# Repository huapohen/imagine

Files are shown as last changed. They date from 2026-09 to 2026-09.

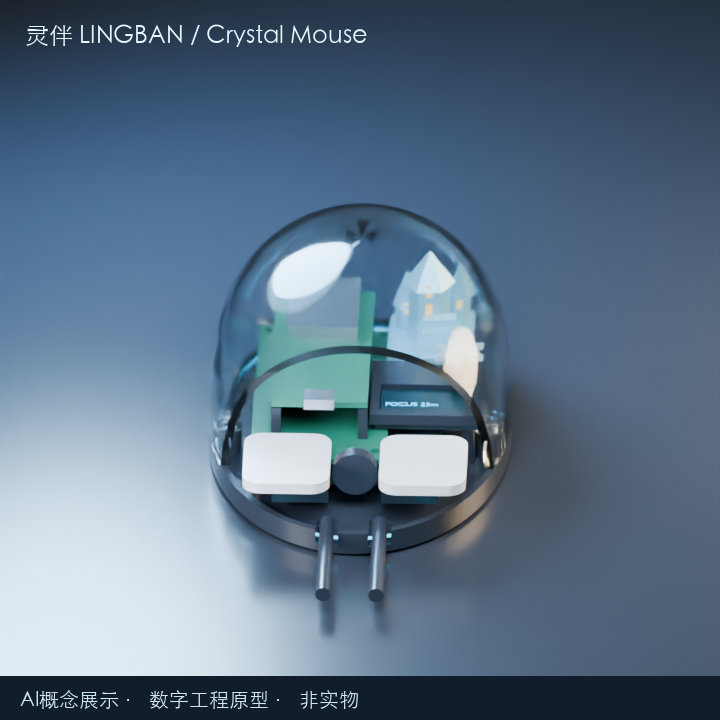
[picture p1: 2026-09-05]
hardware/renders/frames-labeled/0004.png

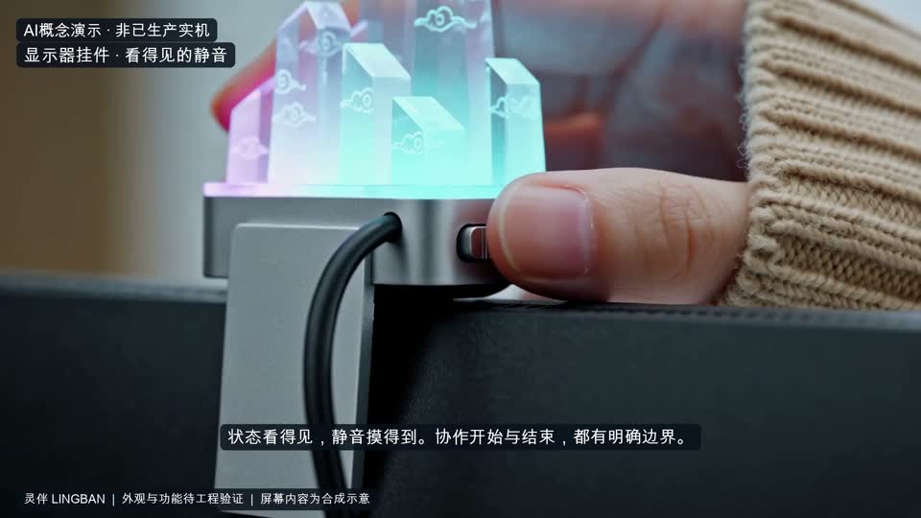
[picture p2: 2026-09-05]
media/qa/05_monitor_charm_05s.jpg

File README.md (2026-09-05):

# 灵伴 LINGBAN / Imagine

透明晶鼠中的原创微型城堡，与电脑上的主动办公伙伴。当前交付是**可运行软件、固件与数字工程原型、商业与路演资料、AI概念影片**；实物样机、认证与量产尚待验证。

## 打开交付

- [本地资料中心](http://127.0.0.1:8766/)：产品图、全部文档、概念影片与评审资料。
- [16页商业计划PDF](pitch/business-plan/lingban-business-plan.pdf) · [商业计划源文](docs/business/business-plan.md)
- [18页可编辑PPTX](pitch/deliverables/final-20260906/lingban-vc-deck.pptx) · [PDF](pitch/deliverables/final-20260906/lingban-vc-deck.pdf) · [离线HTML](pitch/deliverables/final-20260906/lingban-vc-deck.html)
- [3分钟与8分钟逐字稿](docs/business/pitch-scripts.md) · [60个投资人问题](docs/business/investor-qa-60.md)
- [软件启动说明](software/README.md) · [模型接入与真实测试](docs/software/MODEL_INTEGRATION.md) · [固件](firmware/README.md)
- [CAD/PCB工程交接](hardware/COMPLETION.md) · [工厂RFQ](docs/manufacturing-commercial/rfq-template.md) · [独立硬件评审](docs/verification/HARDWARE_REVIEW.md)
- [八条影片与制作验证](media/FINAL_REPORT.md) · [私有GitHub仓库](https://github.com/huapohen/imagine)

## 本地运行

Python 3.9+，软件服务仅使用标准库：

```sh
./software/start.sh
```

按终端显示的员工/企业链接进入。角色令牌是访问凭据，只保存在页面内存；不要把带令牌的链接放进报告。所有默认演示数据均为合成数据，审批结果只进入本地outbox。

本次交付已在8765启动默认离线服务。当前角色链接记录在权限0600、Git忽略且资料服务不提供访问的`.local/demo-server.log`；可在本机终端查看。用户既有Chrome配置曾拦截该端口，未关闭浏览器保护；隔离浏览器验收已通过，录屏可直接查看。

另开终端运行资料中心：

```sh
python3 scripts/serve_workspace.py
```

临时模型测试使用根目录已被Git忽略的`.env`，须按[模型说明](docs/software/MODEL_INTEGRATION.md)显式开启。默认模型为`gpt-6-astra`、推理强度`medium`；模型负责合成场景草稿，本地权限、本人确认和调用预算保持有效。临时配置不进入镜像、交付压缩包或生产环境。

## 验证与交付边界

[最终验收矩阵](docs/verification/RELEASE_READINESS.md)记录自动化、浏览器、协议、固件编译、CAD、KiCad与视频的实际证据及未验证项。

299元是1000台情景下核心版的目标售价；108元制造成本和66.51元单位贡献是模型估算。五台EVT样机的开发板、透明件和装配成本单独计算。融资500万元是建议方案，60万元精简经营模型单独列示，没有收入或融资实绩假设。

企业只获得本人明确分享的业务结果与至少五人的聚合。人数阈值不代表匿名化；不做秘密采集、键盘记录、情绪/生理员工评分或自动雇佣决策。

EVT-A采用OEM USB HID鼠标总成与独立ESP32-S3交互模块、两路USB连接，电脑承担AI。设备唯一线协议是LB1 ASCII + CRC16；MCP 2025-06-18与A2A 0.3.0是本地实现子集。固件可编译、数字检查通过都不能替代实际通电、ESD/EMC、人体工学和工厂DFM签字；制造文件保持**NOT-FOR-FAB**。

大体积影片和制造ZIP通过私有GitHub Release附件分发，源码、财务、文档和精确哈希清单保留在Git。仅克隆仓库时，按[附件清单](docs/operations/RELEASE_ASSETS.md)恢复媒体。没有联系厂家/投资人、租GPU或额外购买工具。

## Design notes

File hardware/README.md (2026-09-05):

# 灵伴 LINGBAN / Crystal Mouse EVT-A

**实际CAD与真实布线PCB数字原型已交接；全部制造文件NOT-FOR-FAB。** 从[COMPLETION.md](COMPLETION.md)查看精确产物、复现命令、实际测试与未验证门槛。

- 主控先传[架构与LB1 ASCII + CRC16串口协议](specs/architecture.md)、[官方核对引脚](specs/pin-map.md)给固件。
- [CAD](cad/README.md)：20件编辑源/STEP/STL，整机和爆炸STEP；底壳、透明上壳、原创独立晶堡/雪花、屏框与组件占位。
- [渲染](renders/README.md)：带概念标识的透明PNG、爆炸PNG、本地转台MP4与可复现Blender源。
- [PCB](pcb/README.md)：可编辑KiCad、实际511段走线/17过孔、BOM/PnP/网表/Gerber/钻孔，真实ERC/几何DRC/schematic-parity报告（均0）。
- [工程与制造](../docs/hardware/engineering-and-manufacturing.md)：99–899分档、299核心量产目标与单列DevKit样机成本、BOM批量/税/良率/NRE、七天样机、装配与验收。
- [验证](validation/README.md)；[工具安装与完整性](tools/README.md)；精简交付包在`delivery/`，不含tools/cache/本地状态。

OEM USB HID + 独立ESP32-S3开发板，双USB或外部Hub；电脑运行Agent。没有融合USB、硬件大模型、已打样/认证/量产或医疗/员工评分声明。主控负责Git、集成与发布；大体积局部工具/DMG/缓存不进交付包。

最终集成：LB1 ASCII+CRC16为唯一设备协议；GPIO/N8R8不变，隐私断SW3V3后灯/屏不显示privacy。49功能节点＋33明确NC节点与原理图完整网名一致，4个机械孔为board_only。既有CAD和pitch渲染hash不变，结果见`validation/integration/result.json`。

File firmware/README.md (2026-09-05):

# 灵伴 ESP32-S3 固件 — safe / EVT-A

工程数字原型，NOT-FOR-FAB。电脑承载 Agent，成熟 USB HID 鼠标底座独立；ESP32-S3 只负责灯光、触摸、隐私开关、可选状态屏与 LB1 串口。无录音摄像、医疗推断或外发。

## 实际构建与测试

```sh
./firmware/test.sh
./software/test-integration.sh
# 已有隔离缓存，构建两个目标，无需安装或网络探测：
PLATFORMIO_CORE_DIR="$PWD/firmware/.platformio" PLATFORMIO_SETTING_ENABLE_TELEMETRY=No \
  firmware/tools/venv/bin/python -m platformio run -d firmware
```

本轮两个目标实际编译 SUCCESS：

|目标|RAM|Flash|物理配置|
|---|---:|---:|---|
|esp32s3_safe|19,964 B / 327,680 B|328,405 B / 3,342,336 B|全部交互引脚和屏地址 -1，缺省隐私，外设不启用|
|esp32s3_evt_a|19,964 B / 327,680 B|332,461 B / 3,342,336 B|GPIO与硬件pin-map对齐，触摸阈值未标定，仍禁用|

产物 `.pio/build/<目标>/firmware.bin` / `.elf`，日志 `build/integration-build.log`。`test.sh` 用 C++11、-Wall/-Wextra/-Werror 编译实际固件共用的协议核心和 Controller 模板。包含104行共用golden以及GPIO/Wire/PWM时序mock，软件完整回归结果见 [COMPLETION](../software/COMPLETION.md)。**这些不是烧录、板测、USB枚举、反灌或触摸校准证明。**

## 板型与端口

PlatformIO Core 6.1.18，espressif32 6.9.0，Arduino ESP32 2.0.17。注册表 `esp32-s3-devkitc-1` 默认描述 N8/no PSRAM，因此两个profile显式覆盖 **N8R8：8MB QIO flash、OPI PSRAM、memory_type=qio_opi、BOARD_HAS_PSRAM**。没有宣称通用板默认配置就是N8R8；实际板标签、PSRAM自检待实物验证。

`ARDUINO_USB_CDC_ON_BOOT=0`。注册表的 `ARDUINO_USB_MODE=1` 仅选择芯片USB模式，**不会自动启用CDC**；本实现的 `Serial` 是 UART0，代码显式 RX44/TX43、115200/SERIAL_8N1。使用开发板 **USB-UART桥连接器**，不是nativeUSB连接器；烧录端口也须硬件人员明确选择，固件会话未运行upload。OEM鼠标另有USB线，载板不并接VBUS。

## EVT-A 针脚与共阳电气合同

|宏|GPIO / 默认值|用途|
|---|---|---|
|LB_PIN_LED_R/G/B|4 / 5 / 6|SW3V3共阳RGB，各经470Ω至GPIO灌电流|
|LB_PIN_TOUCH|7|电极输入；阈值0时不调用touchRead|
|LB_PIN_SDA/SCL|8 / 9|100kHz I2C，外部4.7k上拉到SW3V3|
|LB_PIN_PRIVACY|10|外部10k上拉常供3V3；LOW允许，HIGH/断线隐私|
|LB_SCREEN_ADDRESS|0x3C|SSD1306 128×64候选地址，不等于已探测成功|
|LB_TOUCH_THRESHOLD|0|未实测，禁用触摸采集|

共阳LED亮度b对应8-bit duty=255−b；**off=255/HIGH**，不能写0。恢复时先准备PWM通道off，再预装GPIO HIGH，再attach。当前低亮颜色逻辑为teal=(0,60,38)、amber=(70,30,0)、blue=(0,18,70)，均是占空亮度，不是已实测电流。470Ω限制峰值，LED具体Vf/电流仍需板测。

## 隐私与断线时序

共用控制器 `include/controller.hpp` 是实际固件和mock唯一外设启停策略：

1. 启动先配置/读取GPIO10，再将RGB/I2C/TOUCH全部INPUT，不给未判定电源状态的外设初始化。
2. 物理允许LOW连续稳定40ms，且LB1握手online后，才初始化PWM和屏。屏初始保持Display OFF，写入新图标后才点亮。
3. 检测HIGH立即detach PWM、Wire.end，将4/5/6/7/8/9设INPUT（无内部上拉），清灯/屏/触摸逻辑状态；停止屏刷新。**此分支不发送OLED指令、不强亮LED**，因为SW3V3已经切断。隐私指示靠UI/开关本体。
4. 允许态需重新稳定40ms才能恢复外设；不会恢复隐私前缓存的灯屏指令。
5. 无有效GET/PING心跳>=5秒，清ready/session/cache/灯屏状态；电源仍允许时先OLED Display OFF再释放外设。隐私断电时不发送这个命令。重新HELLO才能恢复online；没有每消息TTL。

主循环每轮及每串口字节检查控制器，串口单轮最多64字节；I2C每个事务前读物理状态、事务timeout=5ms。高电平在正在执行的事务期间变化时，在下一次检查返回后释放外设。这是软件检测时序，**不保证DPDT触点切换瞬间零反灌**；开关两极错时、GPIO复用、在途I2C与实测漏电仍是NOT-FOR-FAB门槛。

无OLED ACK时Wire.end并释放I2C，不持续刷不存在的屏。屏幕仅绘制状态图标，不含中文字体；UTF-8逻辑文本只在串口STATE查询。CAPS声明配置能力，不冒充实物探测报告。

## 触摸启用指南（本轮未启用）

保持threshold=0直至hardware核对电极、串1k、ESD器件DNI/选型、地与外壳，使用合成操作验证干燥/潮湿、接触/不接触噪声分布。不要采用网络示例的未标定固定阈值。经实物审定阈值后，在单独的本地测试profile显式加 `-DLB_TOUCH_THRESHOLD=<实测阈值>`；S3逻辑为touchRead>阈值、稳定40ms才变更布尔状态。

然后必须实测隐私切换时GPIO7输入复用/漏电/触摸硬件是否完全停止、允许恢复是否正确、串口是否始终屏蔽隐私态touch。现有mock不能证明芯片触摸外设的电气状态。触摸只做非敏感本地交互，不能变成情绪/生理信息、医疗判断或审批捷径。

## 串口桥与协议

唯一 [LB1精确规范](../docs/software/serial-protocol.md) 和 [104行golden](../docs/software/serial-golden-vectors.tsv)。无NDJSON、无ttl_ms、无TOUCH/PRIVACY线缆类型。

```sh
cd software
python3 -m lingban.serial_protocol --self-test
LINGBAN_TOKEN='员工本地令牌占位' python3 -m lingban.serial_protocol --once
# 已确认硬件后显式给出设备；本轮未运行：
LINGBAN_TOKEN='员工本地令牌占位' python3 -m lingban.serial_protocol --device /dev/已确认USB_UART
```

桥默认模拟器，不扫描设备。POSIX stdlib termios/select配置115200/8N1；同帧最多重试3次，每次1秒。GET检测offline后新nonce重握手；设备物理拔除造成错误时退出，明确重启后重新打开。关闭时恢复该设备的termios，不改系统全局配置。

## 隔离工具链来源

本轮复用已有 `firmware/tools/venv`、`.platformio` 和 `.pio` 缓存，未下载或安装新依赖。首轮工具来自实测后的可信PyPI镜像和已验证动态系统代理的PlatformIO官方包，包管理器完整性检查开启。`tools-lock.txt` 记录Python依赖；缓存数GiB，均在firmware目录并由.gitignore排除。

新环境需按AGENTS.md先短测源/代理/可信镜像，再建局部venv安装platformio==6.1.18；`build_local.py` 为需网络探测的首次构建辅助脚本，已有缓存优先上面的命令。禁止把构建成功当成允许投板、烧录、认证或量产的依据。

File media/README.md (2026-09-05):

# 灵伴视频研究与制作

官方核验见 `API_CAPABILITIES.md`，完整出处与快照哈希见 `sources.json`。本目录研究代理未读取原始需求/凭据、未调用付费生成。8条原生H3/2K/15秒方案刊例价96元。创建与账单由主控制器负责。

## 复现

```sh
cd /Users/lwblx/huapohen/agent/execute/enterprise_work/imagine/media
python3 video_client.py plan
python3 -m unittest test_video_client.py
# 原生15秒片烧录标签；保留提供方原始尺寸，不将上采样冒称原生2K。
python3 assemble_concept.py --video generated/01_crystal_mouse_focus.mp4 --output edited/01_crystal_mouse_focus.mp4 --title '灵伴晶鼠 · 掌心城堡'
# 可选：真人录制的旁白（voiceover_zh在requests.json），覆盖生成音频。
# 添加 --voiceover narration.wav
# 已有6/10秒AI片源 + CAD静图 = 后期15秒，自动记录provenance而非冒称原生15秒。
python3 assemble_concept.py --video source10s.mp4 --still ../hardware/renders/mouse.png --output edited/composite.mp4
# macOS真实软件屏幕录制；先选中本地演示窗口、全屏，仅显示合成数据。
python3 record_screen.py --list
python3 record_screen.py --screen-index 1 --seconds 15 --output recordings/software-demo.mp4
python3 assemble_concept.py --video recordings/software-demo.mp4 --software-recording --output edited/software-demo.mp4 --title '灵伴本地软件 · 合成数据'
```

屏幕索引必须从本机实时列表取得，示例1不是固定设备。录屏不录麦克风，macOS可能要求系统屏幕录制权限；未授权时不能声称完成录屏。`assemble_concept.py`依赖已有Pillow和ffmpeg/ffprobe，用透明PNG烧录中文，避免当前ffmpeg缺少drawtext/subtitles的问题。默认静音，可添加自有旁白，不下载未经授权配乐。

## 提交与恢复

`MINIMAX_API_KEY`只从环境变量读，不保存在请求/账本或日志。`submit --budget-cny 100 --id …`每次仅提交一条。先将首帧图片以data URL或HTTPS加入对应payload.content（role=first_frame），去掉ratio；参考图免费总数不得超过5。始终保留原始requests和CAD来源。

账本在请求前预占12元；提交后保存task_id；每ID禁止再次提交。网络超时也不释放预占。若task_id未落盘，`list`查看最近任务，与时间/模型/时长/分辨率人工核对，确认身份后`attach`；不可猜测。最近任务窗口7天。失败和取消未核实退款前仍占预算。`poll`只查询一次，不内置等待。`download`只向查询返回的已核验官方CDN域名发送无凭据下载，未知CDN先核验官方文档，不把Key发往CDN。

## 验证与局限

见 `VALIDATION.md`。H3接口/价格为2026-09-06公开文档快照，并非真实账户权限或余额验证。官方未给出输出2K的固定宽高像素表，应保留生成原始分辨率并用ffprobe记录，不强行声称2560×1440。下载SHA-256只能证明本地文件一致性，不能替代提供方签名。没有真实硬件、功能工程验证、医疗测量或量产证明。

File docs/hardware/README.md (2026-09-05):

# 硬件工程交接

产物清单与实际验证：`../../hardware/COMPLETION.md`。

- 架构、引脚和LB1 ASCII + CRC16协议：`../../hardware/specs/`，先传给固件与主控。
- 可编辑CadQuery、STEP/STL：`../../hardware/cad/`。
- 带概念标识的pitch PNG/转台与Blender源：`../../hardware/renders/`。
- 实际布线KiCad、Gerber/drill/BOM/PnP/netlist：`../../hardware/pcb/NOT-FOR-FAB/`。
- 成本分档、7天样机计划、机械/电气审查、制造就绪矩阵及装配验收：`engineering-and-manufacturing.md`。

数字工程原型，不是已验证样机。主控集成与Git；本独立硬件会话没有联系厂家、付费或承诺量产认证。

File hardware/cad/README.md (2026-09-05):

# 参数化机械 EVT-A

编辑 `parameters.json`（mm）与 `build_cad.py`，运行 `hardware/tools/venv/bin/python hardware/cad/build_cad.py`。`exports/`包含每件STEP/STL和整机STEP；`parts.json`列明零件、占位、包围盒和实体有效性。参数并非所有尺寸的唯一来源：放样截面、安装坐标、装饰几何及公差须同时编辑Python源；这是可编辑工程，不是已锁定模具模型。

制造件包括底壳、透明上壳、左右按钮盖、独立晶堡、独立雪花、屏框和城堡定位底座。其余名称带placeholder或标为placeholder的实体仅组件包络。OEM按钮杠杆/滚轮支架/光学镜片安装高度、开关真实固定结构、线缆止拉和屏模组孔位尚未完成，需实际模块图纸后ECO。

实际检查在`../validation/cad-brep.json`及`cad-intersections.json`；不是实物装配通过。STL检查另外记录 watertight/winding；透明壳双层放样名义壁厚非完整等厚认证。工程与装配约束见`../../docs/hardware/engineering-and-manufacturing.md`。

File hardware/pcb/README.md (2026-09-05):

# ESP32-S3 交互载板 EVT-A

`NOT-FOR-FAB/lingban_carrier.kicad_pro` 为可编辑工程；同目录包含原理图、实际双面走线PCB、自包含符号/封装库。36×76×1.6mm，2层1oz假设，0.25mm线宽，0.65/0.30mm过孔。所有输出仅工程评审用。

本载板只含插座、限流/上拉阻容、屏/LED/触摸/物理开关线束接口；ESP32-S3、RGB灯、屏幕与DPDT是外部器件。原理图所有引脚是无源载板触点，ERC只证明本载板连接规则；不证明ESP电气配置或外接器件正确。D1为DNI ESD占位，量产必须冻结真实TVS并更改封装/复验。

复现：仓库根运行 `python3 hardware/pcb/build_pcb.py --sync-existing`、`python3 hardware/pcb/finalize_project.py`、`python3 hardware/pcb/export_and_verify.py`。最后一条真实调用KiCad9.0.7，强制--schematic-parity及--exit-code-violations，同时记录独立几何DRC、ERC并导出制造文件。`gerber-review-only/`不是下单包；禁止仅因DRC/ERC通过即生产。

官方pinout/协议见`../specs/`；供电、线束、装配、成本与未验证项见`../../docs/hardware/engineering-and-manufacturing.md`。PCB顶面箭头方向尚需丝印完善，按J1/J3官方脚1及方形焊盘识别。PnP.csv为设计清单，PnP-kicad.csv为KiCad导出坐标；优先后者并由贴片厂核对底面旋转、原点和DNI。

`build_pcb.py --sync-existing`与`semantic_sync.py`只统一局部标签的完整网名、明确NC单脚网、符号path和机械孔board_only属性，不改铜线坐标。普通全量生成也会调用同一逻辑，未新增忽略规则。H1–H4的exclude_from_bom/pos是真实板上专用机械语义；采购BOM不列机械孔。49功能节点、33个无铜NC节点共82项与KiCad导出网表逐项匹配，检查不删除/前缀。

`sexpr.py`随本目录交付；工具环境不进入ZIP。设备接口只使用LB1；USB-UART115200、GPIO4–10及N8R8按已实装配置冻结，见specs/。

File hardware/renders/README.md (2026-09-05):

# 概念渲染与转台

本地Blender/Cycles渲染，源网格来自同批CAD导出的STL。不是硬件照片，未打样/认证。光环、发光窗和屏幕内容为视觉示意/合成数据；不代表当前低电流LED已经达到光环均匀效果。

```sh
hardware/tools/mount-blender/Blender.app/Contents/MacOS/Blender -b -t 8 --python hardware/renders/render_scene.py -- hero
hardware/tools/mount-blender/Blender.app/Contents/MacOS/Blender -b -t 8 --python hardware/renders/render_scene.py -- exploded
hardware/tools/mount-blender/Blender.app/Contents/MacOS/Blender -b -t 8 --python hardware/renders/render_scene.py -- turntable
hardware/tools/venv/bin/python hardware/renders/finish_media.py
```

`lingban_hero.blend`内已保存120帧/24fps、线性完整旋转的关键帧源；`render_scene.py`可确定性重建灯光、材质、相机、爆炸间距与转台。演示MP4使用每4帧抽样、6fps回放，约5秒一周；不是实时交互。PNG附有概念标识，可直接交pitch；raw文件只供后处理，外发须使用带标识版本。

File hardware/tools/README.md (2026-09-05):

# 任务局部工具环境

已安装/使用 CadQuery 2.8.0（OpenCascade7.9.3）、trimesh5.1.0、Blender4.5.3、KiCad9.0.7；系统现有ffmpeg。Python venv、下载缓存和只读DMG挂载点全部位于hardware/tools或hardware/downloads。未执行brew全局安装，未接受KiCad全局库配置。GUI不是复现依赖。

当前命令：

```sh
hardware/tools/venv/bin/python hardware/cad/build_cad.py
hardware/tools/mount-blender/Blender.app/Contents/MacOS/Blender --version
hardware/tools/mount-kicad/KiCad/KiCad.app/Contents/MacOS/kicad-cli version
```

重启后重新挂载已验证的DMG：

```sh
mkdir -p hardware/tools/mount-blender hardware/tools/mount-kicad
hdiutil attach -readonly -nobrowse -mountpoint "$PWD/hardware/tools/mount-blender" hardware/downloads/blender.dmg
hdiutil attach -readonly -nobrowse -mountpoint "$PWD/hardware/tools/mount-kicad" hardware/downloads/kicad.dmg
```

重建venv先遵守AGENTS网络短测，采用已测可用的PyPI/可信镜像，再运行 `uv venv hardware/tools/venv --python 3.13` 与 `uv pip sync --python hardware/tools/venv/bin/python --require-hashes hardware/tools/requirements.lock`。Python3.13须已经存在；不要为便捷改系统Python。uv缓存使用`UV_CACHE_DIR="$PWD/hardware/tools/uv-cache"`。

网络证据：validation/network-probes.json、mirror-probes.json、download-progress.log。Blender经官方SHA256比对；KiCad DMG通过hdiutil内部校验且应用通过codesign严格验证，签发主体KiCad Services Corporation (9FQDHNY6U2)。首次Blender分段文件损坏已精确删除并重新完整下载，重新校验通过；未清空系统缓存。官方校验文本在downloads/blender.sha256。

主控集成时只打包源码/产物/文档，**不要把downloads、venv、uv-cache或mount-*应用树加入Git或发布包**。本会话不执行Git操作。

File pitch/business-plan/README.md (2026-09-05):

# 灵伴中文商业计划书

交付：`lingban-business-plan.pdf`，A4竖版16页，约3.5MB。包含原创产品概念渲染、需求与主动交互、公司授权边界、20人验证方案、官方竞品事实、完整价格梯度、BOM/单位贡献图、三情景现金图、500万元建议融资用途、7天/30天门槛、工厂验收、半年生态、团队与10个月战略选择、来源页。

本PDF是详细中文BP关键内容的阅读版，非18页横版投资演示稿；完整叙述与可修改假设保留在 `../../docs/business/business-plan.md`、`financial-model.md`、其余商业Markdown和CSV中。正文排版稿在 `build_pdf.py`，财务图表和情景表读取原始CSV，生成时检查关键财务口径；不改变原始模型。融资第11节已追加到源BP。

## 复现

在项目根目录执行：

```bash
/Users/lwblx/.cache/codex-runtimes/codex-primary-runtime/dependencies/python/bin/python3 pitch/business-plan/build_pdf.py
/Users/lwblx/.cache/codex-runtimes/codex-primary-runtime/dependencies/python/bin/python3 pitch/business-plan/validate_pdf.py
```

依赖本机bundled Python中的reportlab、pypdf、pdfplumber、Pillow及bundled Poppler。使用本机 `/System/Library/Fonts/Supplemental/Arial Unicode.ttf`，只在PDF中嵌入必要字体子集；目录没有复制或分发字体文件。未用LibreOffice、网络下载或外部服务。非本机复现需自行提供合法可用的中文TTF和更新脚本中的字体/运行时路径。

`qa/`保留16页实际Poppler渲染、全页拼图、结构/字形检查、抽取文本、布局记录和来源哈希。人工检查结论见 `QA.md`。若修改正文或CSV，重新构建、渲染并目检；修改源Markdown不会自动替代所有编辑过的PDF排版文案。

## 财务与真实性口径

- 500万元为本方案建议的天使融资金额，不是用户原文指定金额、已承诺投资或已到账资金；用途为建议，不构成支出授权。
- 60万元是独立的精简验证模型。500万元用途尚未建立同口径分月模型，因此不报告跑道和投资回报。
- 产品图是原创三维概念渲染，非实物/制造证明；留存、订单、销售与交付门槛均未声称已经达成。
- 官方竞品标价/性能主张与独立测试、订单和众筹成功明确分开。

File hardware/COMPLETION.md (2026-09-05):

# 灵伴 LINGBAN / Crystal Mouse EVT-A — 完成交接

**交付状态：实际CAD + 实际布线PCB的数字工程原型；全部制造输出 NOT-FOR-FAB。** 完成日期2026-09-06。唯一首发为299元核心目标含税零售价（1000台情景，灯＋触摸＋OLED）；当前5台DevKit样机成本约863–1850元/合格台未税工程估算、待报价；108元是未来批量商业模型假设，499仅未来外观/服务套装。没有实物打样、板级通电、固件烧录、认证或量产完成声明。本会话只写hardware/与docs/hardware/，不做Git、不读取原始input/需求或.env、不联系厂家、不付费；主控负责集成。

## 本轮最终集成结果

- 唯一协议LB1 ASCII+CRC16，UART桥115200 8N1、N8R8和GPIO冻结；无每消息TTL/推送事件。隐私切SW3V3并高阻GPIO4–9，不显示privacy灯/屏；touch阈值0默认禁用，屏为状态图标。
- 修复已复现的86项parity差异：保留原理图局部标签，用完整`/3V3`等名称匹配PCB；33个明确NC单脚网按KiCad语义保留且无铜连接；H1–H4设`board_only/exclude_from_bom/exclude_from_pos_files`，不使用全局忽略或错误豁免。
- **KiCad9.0.7 schematic parity=0、几何DRC=0、未连接项=0、ERC=0**。完整网络名逐节点比较：49功能节点＋33明确NC节点，共82节点一致；36项选定/保留脚检查通过。
- CAD与pitch渲染118个既有文件hash均未改变，铜线/过孔/焊盘/板框几何hash未改变，既有CAD干涉仍为[]。本轮不重新生成几何、不重渲染产品图；仅刷新PCB检查、制造导出与PCB图。
- 交付ZIP重新生成，严格不含`tools/`、下载/缓存、`.env`、锁文件、KiCad本地状态或`.DS_Store`；源码S表达式辅助模块随PCB提供。包与逐文件hash在delivery/，包装审核见`package-audit.json`。

证据：`validation/integration/result.json`、`integration/parity-before.json`、`pcb-drc.json`、`pcb-geometric-drc.json`、`sch-erc.json`、`netlist-pinmap-check.json`。生成器用`--sync-existing`只修项目语义，铜线原样保留；之后从头生成也调用同一语义逻辑。

## 精确产物

|用途|路径|内容|
|---|---|---|
|冻结软硬件架构|`hardware/specs/architecture.md`|OEM USB HID + 独立ESP32-S3开发板，双USB/外部Hub，电脑运行Agent；LB1 ASCII + CRC16串口协议|
|官方核对引脚|`hardware/specs/pin-map.md`、`pin-map.json`|GPIO4/5/6/7/8/9/10对应J1.4/5/6/7/12/15/16；v1.1板载RGB38/初版48均避开；官方文本、DXF与原理图缓存在references/|
|参数化CAD源|`hardware/cad/parameters.json`、`build_cad.py`|mm单位，外壳/底板/光学孔/双出线槽/柱位与公差、屏框、原创云阶晶堡、六折雪花、定位底座及组件占位|
|CAD工程导出|`hardware/cad/exports/`|20件逐件STL + 20件逐件STEP；`lingban_assembly.step`整机装配；`lingban_exploded.step`爆炸装配。当前零件以parts.json为准，无旧插座重复件|
|pitch图片|`hardware/renders/lingban_hero.png`、`lingban_exploded.png`|1800×1500透明Cycles渲染，带“AI概念展示 / 数字工程原型 / 非实物”标识|
|动画与源|`hardware/renders/lingban_turntable_concept.mp4`、`lingban_hero.blend`、`lingban_exploded.blend`、`lingban_turntable.blend`、`render_scene.py`、`finish_media.py`|720×720、约5秒完整转台视频；120帧24fps可编辑旋转源，视频每4帧抽样。raw/frames只作中间产物|
|可编辑PCB工程|`hardware/pcb/NOT-FOR-FAB/lingban_carrier.kicad_pro`、`.kicad_sch`、`.kicad_pcb`|36×76×1.6mm两层载板，开发板双排插座，灯/触摸/屏/DPDT物理开关线束，底面阻容，自包含符号和封装库|
|真实走线图|`hardware/pcb/NOT-FOR-FAB/plots/pcb-routed.svg`、`pcb-routed.png`|由实际KiCad铜线/焊盘坐标导出，511段铜线、17过孔、35条连接树边；无未布线连接|
|网表/装配清单|`hardware/pcb/NOT-FOR-FAB/lingban_carrier.net`、`.xml`、`BOM.csv`、`PnP.csv`、`PnP-kicad.csv`|KiCad真实网表；底面SMD贴装坐标，D1标DNI；厂商须确认底视/顶视、原点与旋转|
|制造评审文件|`hardware/pcb/NOT-FOR-FAB/gerber-review-only/`|F/B铜、F/B阻焊、F/B丝印、底面锡膏、Edge.Cuts共8个Gerber；PTH/NPTH两份Excellon钻孔、钻孔图、gbrjob。不是下单包|
|工程/商业交接|`docs/hardware/engineering-and-manufacturing.md`|99/199/299/499/899电子机械差异、BOM批量/税/良率/NRE估算、7天样机计划、制造就绪矩阵、装配验收与工厂待确认尺寸|
|局部工具与校验|工作区`hardware/tools/README.md`（不随ZIP）、`hardware/requirements.lock`；`hardware/validation/tool-integrity.json`|CadQuery2.8.0、trimesh5.1.0、Blender4.5.3、KiCad9.0.7；官方哈希/应用签名验证；不依赖全局brew安装|
|精简交付包|`hardware/delivery/lingban_evt_a_review.zip`、`SHA256SUMS.txt`|供主控集成，不含tools目录、DMG、venv、缓存、挂载应用树、本地状态和视频逐帧中间文件|

## 可重复运行命令

在仓库根运行；工具挂载/重建步骤见hardware/tools/README.md。

```sh
python3 hardware/pcb/build_pcb.py --sync-existing
python3 hardware/pcb/finalize_project.py
python3 hardware/pcb/export_and_verify.py
hardware/tools/venv/bin/python hardware/pcb/render_board.py
hardware/tools/venv/bin/python hardware/validation/validate_artifacts.py
python3 hardware/validation/integration/check_integration.py
python3 hardware/package_delivery.py
```

`export_and_verify.py`调用真实KiCad，parity检查同时启用`--schematic-parity --exit-code-violations`，另导出独立几何DRC和ERC，失败非零退出。当前命令使用工作区既有工具；精简ZIP不附带tools，可用已安装的等版本工具或以hardware/requirements.lock重建局部Python环境。CAD尺寸参数不是全部独立约束求解器；更改壳宽/壳长会调整放样，但安装坐标、OEM接口与装饰仍须检查Python参数与干涉，不能只改一个数字直接制造。

## 实际验证

- OpenCascade：当前20件BREP均有效、均为一个实体；两两正体积干涉 >0.05mm³ 为0。见`validation/cad-brep.json`、`cad-intersections.json`。不意味着局部法向壁厚、公差、强度或实物手感已通过。
- 导出STL：20件均封闭、水密、法向一致、正体积、单连通实体，见`stl-mesh-check.json`、`artifact-check-summary.json`。
- KiCad9.0.7：**ERC 0违规；几何DRC 0违规、0未连接项；schematic parity 0**，未靠规则忽略/排除消除报告。见`sch-erc.json`、`pcb-drc.json`、`pcb-geometric-drc.json`与`kicad-command-results.json`。ERC对象是无源载板触点，不证明ESP/外部模块电气特性。
- 36项官方选定脚/保留脚核对通过；49功能焊盘及33个明确NC焊盘与KiCad导出原理图网表完整名称一致（不再去掉/前缀），NC均单脚且无铜连接。见`netlist-pinmap-check.json`。本轮已只读核对LB1软件/固件、N8R8 profile及GPIO；主控报告两目标编译和HAL测试通过，本会话不重复编译/烧录。
- Blender官方SHA256匹配，Blender/KiCad应用codesign严格验证退出0；KiCad DMG内部校验有效。Python以官方PyPI元数据生成hash锁并从实测可信镜像执行`--require-hashes --reinstall`成功。见工具完整性/安装日志。
- 渲染由本地Cycles执行；视频由ffmpeg编码、ffprobe检查，见`media-probe.json`。城堡窗发光、光导环与屏幕文案是视觉示意/合成数据。

## 工程师/厂商确认后才能推进的点

1. **制造状态不提升到fab-candidate**：D1为未冻结封装的ESD DNI占位；RGB、OLED、DPDT及插座未全部冻结MPN/供应商图纸。需要真实TVS方案、线束脚序、装配方向和DFM审核。
2. **电气未实测**：开发板稳压器/USB能力、启动与无线峰值、满白屏/满亮、隐私断电反灌、触摸阈值/ESD、温升。初版默认USB-UART且关闭Wi-Fi/BLE；通用500mA端口不能按1A电源使用。
3. **隐私边界明确**：机械DPDT切屏/灯电源并给GPIO状态，断线默认隐私；不硬断USB、触摸线路或主机Agent。实装HAL detach PWM/Wire.end并将GPIO4–9置INPUT，无内部上拉；SW3V3断电后不显示privacy灯/屏，只由UI/开关本体指示。触摸默认阈值0、禁用采集，屏仅状态图标；没有音视频、生理诊断、员工评分或秘密采集。
4. **机械需实物ECO**：OEM外形/固定孔/镜片到桌面高度/光学中心、按钮杠杆与滚轮结构；屏模块厚度/孔位和屏框防脱卡扣；装饰底座防脱；隐私开关固定孔与实际止拉件；铜螺母/底脚/螺钉/透明料收缩和后处理。当前名义126×80×54，实际曲面可能超调，完整包络见`assembly-envelope.json`。
5. **RF净空未完成整机验证**：PCB有禁铜区，但附近金属紧固件/铜螺母仍需移位或改非金属，按实际模块天线参考布局复审；不宣称无线/EMC验证通过。
6. **下阶段是7天样机**：到货、工程师签字、电气上电与机械验收均是门槛；30天试销受法规/认证/小批量验收限制。没有厂商报价，所有成本明确批量、税、良率和NRE假设；VC/退出估值不属于本次硬件事实。

specs/已与实装LB1/GPIO同步，继续使用hash未变的带标识PNG/MP4供pitch，最后将NOT-FOR-FAB工程交给电子/机械工程师审核。不要把hardware/downloads、tools/venv、uv-cache、mount-*加入Git或对外包。

## 本轮影响文件

- 接口与商业：`hardware/specs/architecture.md`、`pin-map.md`、`pin-map.json`；`hardware/README.md`、本文件；`docs/hardware/README.md`、`engineering-and-manufacturing.md`。
- PCB语义与复现：`hardware/pcb/build_pcb.py`、新增`semantic_sync.py`与本地`sexpr.py`、`finalize_project.py`、`export_and_verify.py`、`render_board.py`、PCB README；NOT-FOR-FAB中的PCB/原理图、库、BOM、导出网表/制造文件/PCB图已刷新。铜线几何未改，原项目规则未加忽略项。
- 验证与交付：`hardware/validation/validate_artifacts.py`、README、`integration/`和当前检查报告；`hardware/package_delivery.py`、用于无工具环境交付的`hardware/requirements.lock`、delivery/ZIP/manifest/SHA/audit。CAD与产品PNG/MP4/Blender源均未修改；软件、固件及商业主文只读。

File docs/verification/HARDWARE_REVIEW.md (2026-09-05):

# 独立硬件与协议集成评审

日期：2026-09-06。对象：`hardware/pcb/NOT-FOR-FAB` 数字工程原型、当前 CAD、固件与主机串口代码。评审期间各包持续修改，以下为本轮实际读取/执行的快照；未将实物未验证或正常在制列为缺陷。保留 NOT-FOR-FAB 状态，不授权投板。

## 2026-09-06 最终再复核状态（以此表覆盖下方早期快照）

本轮已发现的代码、电气网表一致性与交付口径问题均已关闭；没有剩余必须修改源码的阻断。制造文件仍为 NOT-FOR-FAB，原因是实物验证门槛尚未完成。

|项目|最新独立证据|状态|
|---|---|---|
|共阳 RGB 反相|真实 Controller 输出 OFF=255，teal=[255,195,217]；独立 Mock HAL 测试通过|代码级关闭，未通电验证|
|隐私高阻/I2C 停止|启动先读 GPIO10；隐私进入 detach PWM、Wire.end、GPIO4..9 INPUT；期间不刷屏；允许稳定 40ms 后才重启|代码级关闭，未测物理反灌瞬态|
|5秒通信失效|独立测试精确 5000ms、恢复握手、millis uint32 回绕；失效关灯/清文本/断外设驱动|代码级关闭|
|固件配置/端口|safe 全部交互禁用；独立 EVT-A GPIO4..10、触摸阈值0、OLED候选0x3C、CDC_ON_BOOT=0、UART0 RX44/TX43；N8R8 qio_opi/8MB|两个配置独立编译通过|
|LB1 实现|Python 编码 HELLO/SET/GET → C++ → Python 解码 CAPS/ACK/STATE，含 session nonce；C++/Python各执行104行冻结golden，75条期望响应CRC另经stdlib独立核验|已通过原生互通|
|硬件协议/299售价文件|architecture、hardware README/COMPLETION、docs/hardware 已统一LB1和299灯＋触摸＋OLED核心目标；499仅未来套装，5台DevKit成本863–1850单列，旧LBP仅出现在废弃声明|口径冲突关闭|
|KiCad parity|硬件修复后独立官方 CLI full parity：0几何错误、0未连线、**0 parity**；再次导出XML，82个SCH针脚与PCB精确网名完全一致|原86项已关闭|
|CAD|最新完整生成报告为 `[]`；独立回读20个实际导出STEP全部有效，base/carrier/canopy分别与所有其他当前部件求交，无>0.05mm³正体积干涉|已有几何证据，未做公差/实物装配验收|
|硬件专用ZIP|02:25更新的145条manifest与磁盘、ZIP逐SHA一致；ZIP CRC、SHA256SUMS均通过，关键LB1/299文档和PCB为最新|包内一致性通过；完整软硬件交付范围见下文|

独立 HAL 测试交付源码为 [hal_independent.cpp](hal_independent.cpp)，没有复用构建者测试。覆盖启动隐私、safe 配置、允许去抖、共阳 OFF/颜色、隐私停止、禁用触摸、通信失效/重连、PWM准备期间隐私突变和计时回绕；全部通过。另编译运行构建者 protocol/controller 测试，也通过。测试源码不包含本机绝对路径、凭据或二进制。

在项目根目录复现（仅 C++11 编译器，输出位于忽略的本地目录）：

```sh
mkdir -p .local/review
c++ -std=c++11 -Wall -Wextra -Werror -Ifirmware/include \
  docs/verification/hal_independent.cpp -o .local/review/hal_independent
.local/review/hal_independent
```

STEP 回读证据 `.local/review/final-step-check.json` 使用当前 `parts.json` 有效清单，不导入 exports 中的旧迭代部件；没有重跑或修改硬件生成源。

硬件专用ZIP的独立核对证据为 `.local/review/final-package-check.json`，145条manifest与包中内容全部匹配，未包含 `.env`、`.local`、工具虚拟环境或下载目录。该专包未包含权威 `docs/software/serial-protocol.md` 与 `serial-golden-vectors.tsv`。主控已确认总集成 `scripts/package_factory.py` 负责配套完整协议/向量、固件src/include/test、本独立HAL源码与报告、RFQ/验收资料；完整工程交接应使用总集成包。总包的最终生成、打包检查与发布由主控收尾，本评审不把尚未执行的总包发布写作已验证。

共享协议向量已分别用 C++ runner 和 Python Simulator 独立重放 **104 行**，全部通过；75 条带线缆帧的期望响应另外用 Python 标准库 `binascii.crc_hqx(...,0xffff)` 核验 CRC。可复现命令：

```sh
c++ -std=c++11 -Wall -Wextra -Werror -Ifirmware/include \
  firmware/test/protocol_test.cpp -o .local/review/protocol_final
.local/review/protocol_final --golden docs/software/serial-golden-vectors.tsv
```

编译使用现有缓存 PlatformIO/ESP32 工具链，无下载；输出目录 `.local/review/pio-build`，日志 `independent-pio-build.log`：safe 和 EVT-A 均 SUCCESS。safe RAM 19,964B、Flash 328,405B；EVT-A RAM 19,964B、Flash 332,461B。**编译、Mock HAL 与原生协议通过不等于烧录或实物验证。**

<details>
<summary>首次发现记录（历史快照；已修固件问题不作为当前阻断）</summary>

1. **P1：固件输出模式与载板电气合同不一致。** 当前 `firmware/src/main.cpp:36-41` 用 active-high PWM，`firmware/include/board_config.hpp` 也明确写 active-high；载板为 SW3V3 共阳 RGB，GPIO 经 470Ω 灌电流。启用实际引脚后，`off` 对应三路 0 占空比，即持续拉低、实际全亮；颜色和亮度反相。必须为共阳反相输出。默认全部引脚 -1 使此问题暂未施加到实物，不能据此将错误的 EVT 配置交给接线人员。
2. **P1：隐私态未停止外设 GPIO/I2C 驱动。** 当前 `firmware/src/main.cpp:57` 仅更新逻辑状态；`:71-72` 继续 PWM 与定期 Wire 刷屏，`:48-50` 在首次读取物理隐私输入前已初始化外设。载板切断 SW3V3 后，这不满足 pin-map 要求的 RGB/I2C/TOUCH 高阻，并可能经数据线给断电外设反灌。应先采样隐私，再按允许态启用；隐私激活时立即停止/卸载 PWM、结束 Wire 并将交互引脚设高阻；恢复允许需明确重初始化。主控已通知软件会话修复，**本轮尚未获得修复后硬件适配代码回归结果**。
3. **协议合同冲突必须收敛。** 已实现的 Python/C++ 都是 `LB1|seq|TYPE|payload|CRC16`，ASCII、256-byte 上限、序号 1..65535；`hardware/specs/architecture.md:14-26` 当时仍为 LBP/0.1 NDJSON、512-byte、uint32、RGB/TTL 字段。二者不可互解。主控已裁决 LB1 为唯一现行协议并通知硬件更新；收尾需全仓消除将 NDJSON 视为现行协议的声明。`firmware/platformio.ini` 当前还启用 USB CDC，而硬件架构约定 USB-UART 桥，主控已通知用独立 EVT 配置统一端口。
4. **P2：KiCad 原理图/PCB 实际网名不一致。** 独立开启 `--schematic-parity` 得到 86 条：82 条 net_conflict、4 条 extra_footprint。49 个有效连接的拓扑逐脚一致；冲突主要为 SCH 局部标签 `/3V3` 与 PCB `3V3` 的根路径名称，以及 SCH 的 33 个 `unconnected-*` 与 PCB 空网。4 个安装孔没有 SCH 元件。必须统一网名/NC 与机械孔策略，或精确记录认可的 board-only 孔项，不能以普通 DRC=0 宣称 parity=0。这不是已证实的电气短接或 GPIO 接错。

上述 P1 与协议冲突已即时发送主控。旧协议中的 5 秒离线/TTL 承诺也需处理：当前 `main.cpp:70` 仅在半帧超时时清输入缓存，完整会话断线不清 ready/灯/屏状态；采用 LB1 后应实现有效帧心跳失效回安全态，或明确不再宣称尚未实现的能力。

</details>

## 针脚、网络与电源核对结果

用实际挂载的 **KiCad 9.0.7 CLI** 导出 SCH 的 XML 网表，另行解析 PCB 的每个 footprint/pad-net；没有仅依赖路由脚本或 DRC 摘要。首次49个有效连接节点/14个网络在规范化根路径后拓扑一致；**修复后再次独立导出，全部82个SCH针脚（含NC）与PCB精确网名直接比较，零错配，不再去掉根路径**。PCB 86 个焊盘中的额外4个是明确的board-only安装孔 H1–H4。

|功能|实际连接|判定|
|---|---|---|
|常供 3V3|J1-1/2、C1-1、R7-1、J7-2|与开发板官方针序一致|
|GND|J1-22、J3-1/21/22，以及屏/触摸/电容/开关回路|与官方针序一致|
|红/绿/蓝|J1-4/5/6 → R1/R2/R3 470Ω → J5-2/3/4|GPIO4/5/6 正确，共阳 J5-1 接 SW3V3|
|触摸|J1-7(GPIO7) → R4 1k → J6-1 ELECTRODE；D1 预留到 GND|拓扑一致，D1 是明确 DNI 的待选件|
|屏|J1-12(GPIO8) SDA、J1-15(GPIO9) SCL；R5/R6 4.7k 上拉到 SW3V3；J4=GND/VCC/SCL/SDA|正确，没有将上拉接常供 3V3|
|隐私|J1-16(GPIO10) ↔ R7 10k 常供 3V3 ↔ J7-4；J7-5=GND|高/断线为隐私，与 fail-closed 文档一致|
|双极外置开关|J7-1=SW3V3 common、2=3V3 allow、3=NC；4=PRIVACY_N common、5=GND allow、6=NC|按已写的外置线束约定允许态两极同时闭合；无开关具体料号，仍需实物触点/线束核对|

缓存官方文本 `hardware/specs/references/esp32-official-text.txt` 的 J1/J3 表与上述接用针脚一致。22×2 排针节距 2.54 mm；两排 x=6.57/29.43，中心距 22.86 mm。未用 J1-21 的 5V，未占用 N8R8 的 GPIO35/36/37、启动绑带或 USB/UART 保留脚。

LED 峰值不能只凭低 PWM 占空比声称达标，串阻才约束峰值。以常见红 LED Vf≈1.8 V 举例，(3.3−1.8)/470≈3.2 mA；绿色/蓝色电流取决于真实 Vf。当前 470Ω 共阳方案没有发现必然过流，但 LED 具体料号与 Vf 未定，“每路峰值 ≤5 mA”仍须按最坏电源/电阻/LED 参数复核，不能算已板测。

触摸 D1 在 SCH 标 dnp、BOM 标 DNI，当前实板设计不具有已选定/已装配的 ESD 防护。该限制已写入工程资料，作为 NOT-FOR-FAB 候选可接受；接触放电、漏电/寄生电容和触摸阈值必须在器件选型后验收。

## KiCad 实际检查

- 本轮独立执行 ERC：**0 violations**。
- 本轮独立执行 DRC，含 all-track-errors、severity-all：**0 几何/间距 violations、0 unconnected items**。
- 修复后同一命令加 schematic-parity、severity-all：**0 parity issues**；原86项已关闭，没有把4个安装孔误作缺失电气元件。
- 所有符号为被动连接器/无源器件，ERC=0 不会检测 MCU 固件方向、共阳反相或断电反灌。
- PCB 0..36 × 0..76 mm，厚 1.6 mm；实际有 511 段铜线、17 个过孔，不是仅飞线。天线区存在实际双层 keepout：x=7..29、y=0..8，禁止 tracks/vias/pads/copperpour；当前铜线端点最低 y=10 mm，没有看到进入该区域的线路。keepout 不证明射频性能，开发板版本/天线位置/外壳金属距离仍须实物核对。

最终独立证据：`.local/review/final-netlist.xml`、`final-drc.json`、`final-erc.json`。初次 `independent-drc.json` 的86项只保留作修复历史。命令使用项目内挂载的 `hardware/tools/mount-kicad/KiCad/KiCad.app/Contents/MacOS/kicad-cli`，没有安装/下载工具或修改系统设置。ERC/DRC 配置目录限定 `.local/review`。

安装同版本 KiCad 后，从项目根目录复现全量 parity 检查（可将 `kicad-cli` 替换为本机官方工具路径）：

```sh
kicad-cli pcb drc --schematic-parity --all-track-errors --severity-all \
  --exit-code-violations --format json -o .local/review/final-drc.json \
  hardware/pcb/NOT-FOR-FAB/lingban_carrier.kicad_pcb
kicad-cli sch erc --severity-all --exit-code-violations --format json \
  -o .local/review/final-erc.json hardware/pcb/NOT-FOR-FAB/lingban_carrier.kicad_sch
```

## CAD 与载板实物占位

当前 `hardware/cad/build_cad.py:52-57` 的载板为 36×76×1.6 mm，与实际 PCB Edge.Cuts 相同。CAD 坐标关系可对齐为 x_CAD=x_PCB−28、y_CAD=40−y_PCB；PCB 四孔 (3,3)/(33,3)/(3,71)/(33,71) 对应 CAD x=−25/5、y=37/−31，孔径均 2.5 mm。排母 x=−21.43/1.43、长 55.88 mm，与双排 22 脚及 22.86 mm 排距一致。

CAD 的板底 z=12 mm、板顶 13.6 mm、排母高 9 mm、开发板底 z=23 mm 已留出堆叠关系；但板底 SMD 元件、连接器壳体/插头/线束、焊点高度尚无完整实体包络，不能把“载板矩形没有相交”写为完整装配净空验证。开发板和 OEM 仍是明确的待实测占位。

评审中相交报告持续更新：开始见排母与屏框/屏占位相交，后续已消失；本轮最后读取 `hardware/validation/cad-intersections.json` 尚列 canopy↔castle_socket_sled 2.564 mm³。硬件会话仍在修，此项记为**在制、未做最终关闭**，不把此前已消失的中间问题列作当前缺陷。最终应检查最新 assembly 与有效 parts 清单；exports 中存在以前迭代的不同排母坐标文件，不能逐个导入整个目录当作最终装配。

## 协议实际运行与上一轮 P1 回归

本轮把现有 `firmware/test/protocol_test.cpp` 编译至 `.local/review/protocol_test`，未修改源码。原生 C++ 测试通过 CRC16-CCITT-FALSE 标准向量、帧界限、握手、默认隐私、幂等/冲突、字段验证。再用 Python 的真实 `encode` 生成 HELLO/SET/GET 喂给 C++ `--echo`，Python `decode` 成功读取 CAPS/ACK/STATE。**这证明 LB1 编解码跨语言一致，不证明 Arduino GPIO、USB、OLED 或真实串口通信。**

- 前轮 R1 已关闭：全新内存 Store 首次 `task.upsert` 与 `meeting.upsert` 都成功，不再出现 9 列/10 占位符错误。
- 前轮 R2 已关闭：5 人企业 A2A 摘要后撤回 1 人，旧 `tasks/get` 返回 404，同 `messageId` 重放重新计算 `available=false`；旧 artifacts/history/status.message 不再经该路径读回。
- 本轮没有再次审计全部前轮 P2 或新增加的全部软件 API，不能将上述两项通过扩大为全软件验收。

## 可接受限制

无真实样机、板级功耗/ESD/反灌/射频/人机工程验证，属于明确的数字原型边界。safe 配置引脚禁用、EVT-A 触摸阈值待标定、D1 DNI、双 USB、未完成中文屏幕字体均可在准确标识下接受。共阳 PWM 与隐私高阻已完成代码修复和独立 Mock HAL 回归；生产输出继续保持 NOT-FOR-FAB，直到工程复核与实测门槛完成。

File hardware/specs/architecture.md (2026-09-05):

# 灵伴 LINGBAN / Crystal Mouse — EVT-A 冻结接口

工程数字原型，未打样、未板测、未认证。日期2026-09-06。主控集成；所有尺寸mm。原创「云阶晶堡」。本轮同步已实装的协议和固件配置，不改变GPIO、CAD几何或pitch渲染。

## 唯一首发与硬件边界

- **299元是1000台情景的核心版目标含税零售价，功能为灯＋触摸＋OLED。** 首轮只验证这一核心硬件；108元批量直接成本是未来商业模型假设，非当前开发板样机报价。5台DevKit工程样机成本单列、待报价。499元仅未来外观/服务套装，不是第二个首发版本。完整分档和敏感性见docs/hardware/engineering-and-manufacturing.md。
- 成熟有线USB HID鼠标OEM总成＋独立ESP32-S3-DevKitC-1 N8R8开发板＋交互载板，电脑运行Agent。A线为OEM鼠标，B线固定使用开发板**USB-UART桥**：UART0 RX44/TX43、115200 8N1、无流控；`ARDUINO_USB_CDC_ON_BOOT=0`。可接外部供电Hub；不融合USB、不并接VBUS、不改OEM HID。
- 载板接3V3/GND与GPIO4/5/6低电流共阳RGB、GPIO7触摸、GPIO8/9 I2C、GPIO10物理隐私。GPIO和N8R8设置以已实装的`firmware/platformio.ini`、`include/board_config.hpp`及`include/controller.hpp`为准，见本目录pin-map.md/json。
- 3V3来自开发板稳压器；载板外设预算<=60mA，5V电源按1A能力预留验证。500mA端口不得按1A使用，实耗、启动峰值和热耗未测；首版关闭Wi-Fi/BLE。
- 物理DPDT一极切断灯/屏SW3V3，另一极在允许态将GPIO10接GND；外10k上拉常供3V3。HIGH/断线/未配置=隐私。隐私时外设断电，**不显示隐私灯，也不在屏上显示privacy**；指示由主机UI和开关本体提供。
- 固件先读取隐私再初始化外设。进入隐私时detach PWM、Wire.end，GPIO4/5/6/7/8/9改INPUT、不启用内部上拉，清灯/屏/触摸逻辑状态。允许LOW连续40ms且已握手online才恢复。共阳RGB的PWM duty=255−亮度，off=255/HIGH，初始化先预装off。
- 隐私开关不硬断触摸线路、USB或主机Agent，不删除电脑任务、不自动改变主机专注计时器。无音视频/医疗传感器、无员工评分；审批仍由主机执行授权流程，触摸不隐式批准。
- OEM原主控、镜片、光学高度、滚轮和按键沿用成熟总成，CAD包络不等于任意OEM能装入。壳体和电气仍需工程师及实物审查。

## 唯一设备协议：LB1 ASCII + CRC16

**权威规范：`docs/software/serial-protocol.md`**；`firmware/serial-protocol.md`指向同一合同。软件标识`lingban.serial/1`对应线缆`LB1`，非MCP/A2A。旧LBP/0.1 NDJSON草案已废弃，无兼容解析器。下表只是硬件交接摘要，不定义第二套协议。

```text
LB1|<seq>|<TYPE>|<payload>|<CRC16><LF>
```

|项目|冻结值/行为|
|---|---|
|帧|ASCII，最多256 bytes（含单个LF），不接受CRLF；seq=1..65535十进制、无前导零|
|CRC|CRC16-CCITT-FALSE，poly=0x1021、init=0xffff、无反射/xorout=0；覆盖最后CRC分隔符之前全部字节；4位大写hex；123456789→29B1|
|握手|HELLO `versions=1;session=<16位小写hex>`；每次连接新nonce，返回CAPS；无session仅一次性自检兼容|
|状态赋值|SET只允许`led=off/teal/amber/blue`和/或`text=<0..80 UTF-8 bytes的小写hex>`，非空字段集合；无任意RGB数组、无每消息TTL；ACK applied=1不代表电脑审批执行完成|
|读取/心跳|GET/PING payload为空；GET→STATE，PING→ACK alive=0/1。正式桥每秒GET，其他控制器最多每2秒GET/PING|
|5秒离线|距最后有效心跳>=5000ms，poll清会话/缓存/输出。仅合法空GET/PING（含同帧重试）刷新心跳；SET、错误帧、序号冲突、缓存HELLO不保活。恢复需HELLO|
|离线电气|仍有外设电源时先Display OFF再卸载PWM/Wire并高阻；若已物理隐私断电，跳过所有屏/PWM写操作，直接高阻|
|重试|最近16个seq FIFO；同seq异帧sequence_conflict；SET重试不重复应用，GET/PING重试返回当前状态|
|错误|坏CRC/帧/ASCII/类型词/seq静默丢弃；合法帧的方法/字段错误才返回可信seq的ERR；无ttl_ms、TOUCH/PRIVACY推送类型|
|能力|EVT-A配置led=1、privacy=1、screen=1，**touch=0**（阈值0未标定）；safe四项为0。CAPS描述配置而非板测|
|屏幕|SSD1306候选0x3C；当前HAL显示状态图标。text为逻辑数据，GET可读取，无任意文字/中文字体已实装承诺|
|隐私状态|STATE privacy=1、led=off、touch=0、text为空；SET被拒绝。主机UI的`led=privacy`是合成标签，不是线缆枚举或物理灯光|

未完成帧1秒清接收缓冲仅用于分帧恢复，不是命令TTL或5秒会话watchdog。黄金向量为`docs/software/serial-golden-vectors.tsv`，RESET/PRIVACY/TOUCH/POLL是测试驱动命令，不是线缆消息。本轮只读核对实现；主控报告两目标编译及HAL隐私/共阳/断联测试通过，不替代烧录和实际串口/反灌/屏幕验证。

## 机械与制造边界

名义126×80×54，已验证的CAD/STEP及pitch渲染本轮保持不变。偏大展示样机，人体工学未验证。壁厚、间隙、柱位、双USB槽、光学孔等见CAD参数与工程交接；OEM真实尺寸、屏/LED/开关料号、反灌、ESD、天线净空和止拉须到货复审。即使ERC/DRC/parity清零，制造文件仍为NOT-FOR-FAB。

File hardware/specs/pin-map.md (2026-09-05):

# EVT-A 冻结引脚表（已对照官方 v1.1 文档逐脚核对）

ESP32-S3-DevKitC-1，N8R8，2×22排针，2.54mm节距。必须逐脚对照官方表；禁止用 ESP32 普通款 pinout。避开启动绑带GPIO0/3/45/46，USB19/20，UART43/44，板载RGB38（v1.1）/48（初版），以及N8R8保留GPIO35/36/37。

|信号|GPIO|方向|电平/约束|
|---|---:|---|---|
|RGB_R|4|PWM sink|3.3V，串470Ω，低亮|
|RGB_G|5|PWM sink|3.3V，串470Ω|
|RGB_B|6|PWM sink|3.3V，串470Ω|
|TOUCH|7|touch input|3.3V，1k串联，ESD；调校后启用|
|I2C_SDA|8|open drain|3.3V，4.7k到外设电源；隐私态高阻|
|I2C_SCL|9|open drain|3.3V，4.7k到外设电源；100kHz起步|
|PRIVACY_ALLOW_N|10|input|外10k上拉到常供3V3；开关允许态接GND；高/断线=隐私|

屏幕候选 0.96in SSD1306 128×64 I2C 模组，首版连接器约定GND/VCC/SCL/SDA，不假定市售模块排列一致。禁止5V模块上拉进入GPIO。物理DPDT开关一极外设3V3通断，另一极允许态GPIO10接地。固件进入隐私立即将RGB/I2C/TOUCH变高阻，防止GPIO反灌断电外设；反灌仍须板测。

官方来源：https://docs.espressif.com/projects/esp-dev-kits/en/latest/esp32s3/esp32-s3-devkitc-1/user_guide_v1.1.html ，缓存 references/esp32-official-text.txt。所选GPIO4/5/6/7/8/9/10分别为官方J1的4/5/6/7/12/15/16脚；J1-1/2=3V3，J1-22=GND；J3-1/21/22=GND。实物排针宽度与脚1方向仍需量测。不得投板。

机读接口见 `pin-map.json`。额外官方尺寸证据 `references/devkit-dimensions.dxf` 提取到62.74mm、25.40mm、2.54mm、1.27mm、8.00mm文字；排间22.86=25.40−2×1.27。CAD开发板与载板定位按该几何假设对应，但到货仍需确认绘图基准和公差。v1.1板载RGB=GPIO38（官方明确），初版=GPIO48，均保留不用。

注意：`PRIVACY_ALLOW_N`是硬件说明名，PCB网络缩写为`PRIVACY_N`，都是GPIO10、高/断线=隐私，低=允许。本轮已只读核对固件实现；主控报告safe/EVT-A两目标编译和mock HAL测试通过。本硬件会话未重复编译或烧录，不冒称板测。

## 已实装 profile 与设备合同

唯一设备协议为 **LB1 ASCII + CRC16**，以 `docs/software/serial-protocol.md` 为准；UART桥115200 8N1，UART0 RX44/TX43，native CDC关闭。GPIO43/44由开发板USB-UART桥使用，载板不再接它们。

`firmware/platformio.ini`的esp32s3_evt_a：8MB flash、qio、qio_opi、opi PSRAM、BOARD_HAS_PSRAM、ARDUINO_USB_CDC_ON_BOOT=0；GPIO4/5/6/7/8/9/10与上表逐项一致，屏地址固定候选0x3C。LB_TOUCH_THRESHOLD=0，触摸采集默认禁用，CAPS touch=0；有电极不等于已标定。safe所有引脚/屏地址默认-1，能力为0。

共阳灯PWM duty=255−亮度，off=255/HIGH；先预装off再attach。隐私切SW3V3后灯/屏不显示privacy；GPIO4–9全部INPUT且不启用内部上拉。LOW稳定40ms且online才恢复。离线>=5秒会清状态并释放外设；已断电不再向屏/PWM写入。逻辑text可经GET读取，当前屏只画状态图标，不承诺渲染任意文字。实现来源为firmware/include/board_config.hpp、controller.hpp及software/lingban/serial_protocol.py；不自行变更引脚/协议。

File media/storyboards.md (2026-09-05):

# 灵伴 LINGBAN · 8 条原生15秒概念片

统一输出：MiniMax-H3 / 2K / 15秒 / 16:9；每条预算12元，总96元。原生视频生成不是硬件实机证明。

常驻后期标签：左上「AI概念演示 · 非已生产实机」；结尾12–15秒附「功能/外观待工程验证」。屏幕内容如有重建须标「合成演示数据」。

统一风格：透明PC晶体感、原创非IP城堡、珍珠银底座、青紫柔光。企业明确分享与≥5人聚合；不展现隐蔽监控。

## 01_crystal_mouse_focus · 晶鼠 · 透明城堡产品 Hero

场景：透明鼠标 / 开放工位

0–4s：微距掠过透明顶壳，城堡浮雕与USB线清晰可见。4–10s：缓慢环绕完整鼠标，珍珠银底座与物理按键保持形状。10–15s：手指轻触侧面独立交互区，柔和青紫灯亮起，城堡不运动、不凭空漂浮。

旁白：一座掌心城堡，让提醒变得温柔。灵伴晶鼠，外观与交互概念。

生成Prompt：

```text
A photorealistic original industrial-design concept film for LINGBAN, not an existing manufactured product. Contemporary Chinese creative workplace, calm premium materials, believable object scale, practical USB cabling. Unified design language: optically clear crystal-like polycarbonate shell, original miniature architectural castle with asymmetrical stepped spires and floating-cloud motifs, soft cyan to lavender accent lighting, brushed pearl-silver lower structure. This castle must be original, not resembling any famous entertainment castle or branded character. Restrained cinematic lighting, macro material detail, physically plausible reflections and refraction, stable geometry and consistent object identity across shots. 16:9, continuous 15-second storytelling. No fabricated medical readouts, no biometric employee scoring, no surveillance, no hidden camera, no keyboard logging. Do not generate logos, subtitles, readable screen text or watermarks; reserve top-left empty space for a permanent post-production AI concept label. No speech; quiet natural room ambience only. The hardware appearance and interactions are speculative, not claims of a tested prototype.

0–4 seconds: extreme macro glide across the clear top shell of a palm-sized wired computer mouse, revealing a miniature asymmetrical stepped crystal castle firmly mounted inside. 4–10 seconds: slow 120-degree tabletop orbit reveals the entire mouse with two real click buttons, a scroll wheel, a pearl-silver base and a visible USB cable. The shell proportions remain constant. 10–15 seconds: a single adult hand enters and gently touches the distinct side interaction pad; only a subtle cyan-lavender light blooms inside. No moving castle, no hologram, no magical floating objects. Clear functional mouse silhouette throughout, hero product framing.
```

## 02_crystal_mouse_workday · 晶鼠 · 由人批准的办公搭档

场景：透明鼠标 / 设计项目审批

0–4s：设计师在开放工位审阅合成任务卡。4–10s：鼠标侧灯提醒，设计师看屏幕、主动点击确认；屏幕文字留给后期。10–15s：一个任务完成标记出现于后期叠层，手离开鼠标短暂舒展。

旁白：待办先提醒，执行由你确认。工作进度分享，也由你选择。

生成Prompt：

```text
A photorealistic original industrial-design concept film for LINGBAN, not an existing manufactured product. Contemporary Chinese creative workplace, calm premium materials, believable object scale, practical USB cabling. Unified design language: optically clear crystal-like polycarbonate shell, original miniature architectural castle with asymmetrical stepped spires and floating-cloud motifs, soft cyan to lavender accent lighting, brushed pearl-silver lower structure. This castle must be original, not resembling any famous entertainment castle or branded character. Restrained cinematic lighting, macro material detail, physically plausible reflections and refraction, stable geometry and consistent object identity across shots. 16:9, continuous 15-second storytelling. No fabricated medical readouts, no biometric employee scoring, no surveillance, no hidden camera, no keyboard logging. Do not generate logos, subtitles, readable screen text or watermarks; reserve top-left empty space for a permanent post-production AI concept label. No speech; quiet natural room ambience only. The hardware appearance and interactions are speculative, not claims of a tested prototype.

0–4 seconds: medium over-shoulder shot of an adult designer at a bright open studio desk, looking at a monitor with simple abstract neutral task cards, no readable text. The same transparent wired crystal castle mouse sits next to a keyboard. 4–10 seconds: a subtle amber reminder light appears in its dedicated side strip; the designer calmly reviews the monitor and deliberately clicks once to approve an action. 10–15 seconds: monitor changes to a simple abstract completion card; the person releases the mouse and stretches fingers gently. Show agency and consent, not automatic computer takeover. No health diagnosis or metrics, no colleague tracking. Keep the mouse geometry consistent.
```

## 03_keyboard_sidecar · 键盘边栏 · 专注节奏

场景：键盘独立侧边栏 / 财务合成报表

0–4s：宽镜头展示键盘旁独立透明侧边栏与独立线缆。4–10s：拨轮设置专注时段，阶梯城堡灯缓缓变暖。10–15s：轻按静音键，灯降低亮度，回到安静工作。

旁白：一个拨轮，切换专注节奏。独立边栏，不读取你的每次击键。

生成Prompt：

```text
A photorealistic original industrial-design concept film for LINGBAN, not an existing manufactured product. Contemporary Chinese creative workplace, calm premium materials, believable object scale, practical USB cabling. Unified design language: optically clear crystal-like polycarbonate shell, original miniature architectural castle with asymmetrical stepped spires and floating-cloud motifs, soft cyan to lavender accent lighting, brushed pearl-silver lower structure. This castle must be original, not resembling any famous entertainment castle or branded character. Restrained cinematic lighting, macro material detail, physically plausible reflections and refraction, stable geometry and consistent object identity across shots. 16:9, continuous 15-second storytelling. No fabricated medical readouts, no biometric employee scoring, no surveillance, no hidden camera, no keyboard logging. Do not generate logos, subtitles, readable screen text or watermarks; reserve top-left empty space for a permanent post-production AI concept label. No speech; quiet natural room ambience only. The hardware appearance and interactions are speculative, not claims of a tested prototype.

0–4 seconds: overhead shot of a compact keyboard with a separate narrow transparent control sidecar to its right, with its own visible USB cable, on an accounting workspace showing only abstract synthetic spreadsheet shapes. 4–10 seconds: close-up of one hand rotating a tactile silver dial on the sidecar; a tiny original stepped crystal skyline under the clear shell glows warmer to suggest a focus timer. 10–15 seconds: the user presses an obvious physical mute button; light dims and the hand returns to normal desk work. The sidecar is physically independent, not a keylogger. No scrolling personal data, no unreadable text to camera.
```

## 04_desktop_orb · 桌面晶球 · 私人待办入口

场景：透明晶球 / 产品经理计划

0–4s：磨砂环座托住透明晶球，内部原创阶梯小城堡。4–10s：轻触环座，后方屏幕展现三张合成任务卡。10–15s：手动旋钮选择一张卡，球内柔光回应。

旁白：把一天的重点，放在看得见的地方。私人待办，按需唤醒。

生成Prompt：

```text
A photorealistic original industrial-design concept film for LINGBAN, not an existing manufactured product. Contemporary Chinese creative workplace, calm premium materials, believable object scale, practical USB cabling. Unified design language: optically clear crystal-like polycarbonate shell, original miniature architectural castle with asymmetrical stepped spires and floating-cloud motifs, soft cyan to lavender accent lighting, brushed pearl-silver lower structure. This castle must be original, not resembling any famous entertainment castle or branded character. Restrained cinematic lighting, macro material detail, physically plausible reflections and refraction, stable geometry and consistent object identity across shots. 16:9, continuous 15-second storytelling. No fabricated medical readouts, no biometric employee scoring, no surveillance, no hidden camera, no keyboard logging. Do not generate logos, subtitles, readable screen text or watermarks; reserve top-left empty space for a permanent post-production AI concept label. No speech; quiet natural room ambience only. The hardware appearance and interactions are speculative, not claims of a tested prototype.

0–4 seconds: slow dolly in on a palm-sized clear crystal desk orb on a brushed silver ring base, containing a firmly mounted miniature original stepped castle. A product manager sits in a calm private desk setting. 4–10 seconds: a hand taps the clearly visible base touch pad; a desktop monitor behind the orb reveals three simple abstract task cards without readable text. 10–15 seconds: rotate a small physical ring dial one notch to select a card and the orb gives a restrained cyan light response. No floating interfaces, no hidden camera, no magical projections. Refraction remains realistic and the orb stays perfectly spherical.
```

## 05_monitor_charm · 显示器挂件 · 看得见的静音

场景：显示器透明挂件 / 远程协作

0–4s：屏幕顶部夹持式透明小城堡挂件特写。4–10s：侧面物理静音滑钮切换，指示灯显著变化。10–15s：镜头拉远到用户自主开启的协作会话，所有人屏幕为合成头像。

旁白：状态看得见，静音摸得到。协作开始与结束，都有明确边界。

生成Prompt：

```text
A photorealistic original industrial-design concept film for LINGBAN, not an existing manufactured product. Contemporary Chinese creative workplace, calm premium materials, believable object scale, practical USB cabling. Unified design language: optically clear crystal-like polycarbonate shell, original miniature architectural castle with asymmetrical stepped spires and floating-cloud motifs, soft cyan to lavender accent lighting, brushed pearl-silver lower structure. This castle must be original, not resembling any famous entertainment castle or branded character. Restrained cinematic lighting, macro material detail, physically plausible reflections and refraction, stable geometry and consistent object identity across shots. 16:9, continuous 15-second storytelling. No fabricated medical readouts, no biometric employee scoring, no surveillance, no hidden camera, no keyboard logging. Do not generate logos, subtitles, readable screen text or watermarks; reserve top-left empty space for a permanent post-production AI concept label. No speech; quiet natural room ambience only. The hardware appearance and interactions are speculative, not claims of a tested prototype.

0–4 seconds: detailed close-up of a small clear castle-shaped desk accessory clipped securely to the top corner of a computer monitor, with a visible cable and an obvious side mute slider. 4–10 seconds: user slides the physical switch, with an immediate unmistakable change from lit cyan to unlit state. 10–15 seconds: slow pullback shows the user calmly starting a remote collaboration session on a monitor showing simple synthetic avatar circles and abstract panels, no identifiable faces or readable text. The accessory has no lens and no covert recording. Emphasize tactile control, clear mounting and believable light diffusion.
```

## 06_meeting_puck · 会议 Puck · 明确共享的会议结果

场景：透明会议圆盘 / 六人项目会

0–4s：六位成人围桌，透明圆盘中央城堡浮雕、麦克风开关可见。4–10s：主持人示意与会者并按下明确启用键，状态环点亮。10–15s：屏幕上只出现共享行动项图形，用户按键结束，状态灯熄灭。

旁白：明确启用，随时静音。共享会议行动项，不评判个人状态。

生成Prompt：

```text
A photorealistic original industrial-design concept film for LINGBAN, not an existing manufactured product. Contemporary Chinese creative workplace, calm premium materials, believable object scale, practical USB cabling. Unified design language: optically clear crystal-like polycarbonate shell, original miniature architectural castle with asymmetrical stepped spires and floating-cloud motifs, soft cyan to lavender accent lighting, brushed pearl-silver lower structure. This castle must be original, not resembling any famous entertainment castle or branded character. Restrained cinematic lighting, macro material detail, physically plausible reflections and refraction, stable geometry and consistent object identity across shots. 16:9, continuous 15-second storytelling. No fabricated medical readouts, no biometric employee scoring, no surveillance, no hidden camera, no keyboard logging. Do not generate logos, subtitles, readable screen text or watermarks; reserve top-left empty space for a permanent post-production AI concept label. No speech; quiet natural room ambience only. The hardware appearance and interactions are speculative, not claims of a tested prototype.

0–4 seconds: natural wide shot of exactly six adult coworkers in a bright meeting room, a small transparent round meeting puck in the center of the table, visible physical microphone mute button and original low-relief stepped castle inside. 4–10 seconds: facilitator makes an open consent gesture toward participants, then deliberately presses the enable button; a conspicuous status light ring turns on. 10–15 seconds: show a wall monitor with abstract shared action-item cards, no transcript text, then the facilitator presses stop and the ring turns off. No facial recognition, no emotion scores, no covert recording, no ranking individuals. Hardware is a speculative concept, not a certification demonstration.
```

## 07_deskmat_module · 桌垫模块 · 温和休息建议

场景：桌垫边缘透明模块 / 长时写作

0–4s：羊毛灰桌垫右上角可拆透明城堡模块与USB线。4–10s：柔光提示，用户按下稍后提醒。10–15s：用户自行起身，模块安静待机；不呈现心率血压数值。

旁白：久坐时给个温和提醒。是否休息，由你决定；它不作医疗判断。

生成Prompt：

```text
A photorealistic original industrial-design concept film for LINGBAN, not an existing manufactured product. Contemporary Chinese creative workplace, calm premium materials, believable object scale, practical USB cabling. Unified design language: optically clear crystal-like polycarbonate shell, original miniature architectural castle with asymmetrical stepped spires and floating-cloud motifs, soft cyan to lavender accent lighting, brushed pearl-silver lower structure. This castle must be original, not resembling any famous entertainment castle or branded character. Restrained cinematic lighting, macro material detail, physically plausible reflections and refraction, stable geometry and consistent object identity across shots. 16:9, continuous 15-second storytelling. No fabricated medical readouts, no biometric employee scoring, no surveillance, no hidden camera, no keyboard logging. Do not generate logos, subtitles, readable screen text or watermarks; reserve top-left empty space for a permanent post-production AI concept label. No speech; quiet natural room ambience only. The hardware appearance and interactions are speculative, not claims of a tested prototype.

0–4 seconds: shallow-focus tabletop shot of a wool-grey desk mat with a small removable clear rectangular castle module clipped along its upper right edge and a practical USB cable. An adult writer is working comfortably. 4–10 seconds: the module emits a gentle warm light reminder; the user presses a clearly visible snooze button and the light dims. 10–15 seconds: the user chooses to stand and stretch beside the desk, leaving the module quietly idle. No heart-rate, blood-pressure, stress or diagnostic numbers, no claims of medical measurement. The accessory is a reminder and non-medical comfort concept.
```

## 08_robot_extension · 机器人扩展 · 由人确认的小任务

场景：桌面机器人底座 / 创意工作坊

0–4s：透明城堡上装置固定在小型桌面移动底座，轮子与急停清楚。4–10s：用户在桌面按钮确认，机器人缓慢沿空桌移动10厘米。10–15s：用户按急停，停止在文具托盘旁；保持边缘安全距离。

旁白：从桌面伙伴，到生态探索。每一步动作，先确认，再执行。

生成Prompt：

```text
A photorealistic original industrial-design concept film for LINGBAN, not an existing manufactured product. Contemporary Chinese creative workplace, calm premium materials, believable object scale, practical USB cabling. Unified design language: optically clear crystal-like polycarbonate shell, original miniature architectural castle with asymmetrical stepped spires and floating-cloud motifs, soft cyan to lavender accent lighting, brushed pearl-silver lower structure. This castle must be original, not resembling any famous entertainment castle or branded character. Restrained cinematic lighting, macro material detail, physically plausible reflections and refraction, stable geometry and consistent object identity across shots. 16:9, continuous 15-second storytelling. No fabricated medical readouts, no biometric employee scoring, no surveillance, no hidden camera, no keyboard logging. Do not generate logos, subtitles, readable screen text or watermarks; reserve top-left empty space for a permanent post-production AI concept label. No speech; quiet natural room ambience only. The hardware appearance and interactions are speculative, not claims of a tested prototype.

0–4 seconds: original small tabletop robot extension: a transparent miniature stepped castle enclosure securely fixed onto a low pearl-silver two-wheel base, visible prominent physical emergency stop, a tiny empty stationery tray. Bright creative workshop with no people in the motion path. 4–10 seconds: an adult deliberately presses a separate approval button on the desk; the robot moves slowly exactly ten centimeters across a clear flat area far from the table edge. 10–15 seconds: user presses the emergency stop and the robot comes to rest beside a pencil holder. Simple plausible wheel motion, no arms, no flight, no unsupervised action or facial tracking. This is an exploratory product concept, no claim of tested navigation.
```

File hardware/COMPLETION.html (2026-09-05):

# 灵伴 LINGBAN / Crystal Mouse EVT-A — 完成交接

交付状态：实际CAD + 实际布线PCB的数字工程原型；全部制造输出 NOT-FOR-FAB。 完成日期2026-09-06。唯一首发为299元核心目标含税零售价（1000台情景，灯＋触摸＋OLED）；当前5台DevKit样机成本约863–1850元/合格台未税工程估算、待报价；108元是未来批量商业模型假设，499仅未来外观/服务套装。没有实物打样、板级通电、固件烧录、认证或量产完成声明。本会话只写hardware/与docs/hardware/，不做Git、不读取原始input/需求或.env、不联系厂家、不付费；主控负责集成。

## 本轮最终集成结果

- 唯一协议LB1 ASCII+CRC16，UART桥115200 8N1、N8R8和GPIO冻结；无每消息TTL/推送事件。隐私切SW3V3并高阻GPIO4–9，不显示privacy灯/屏；touch阈值0默认禁用，屏为状态图标。
- 修复已复现的86项parity差异：保留原理图局部标签，用完整/3V3等名称匹配PCB；33个明确NC单脚网按KiCad语义保留且无铜连接；H1–H4设board_only/exclude_from_bom/exclude_from_pos_files，不使用全局忽略或错误豁免。
- KiCad9.0.7 schematic parity=0、几何DRC=0、未连接项=0、ERC=0。完整网络名逐节点比较：49功能节点＋33明确NC节点，共82节点一致；36项选定/保留脚检查通过。
- CAD与pitch渲染118个既有文件hash均未改变，铜线/过孔/焊盘/板框几何hash未改变，既有CAD干涉仍为[]。本轮不重新生成几何、不重渲染产品图；仅刷新PCB检查、制造导出与PCB图。
- 交付ZIP重新生成，严格不含tools/、下载/缓存、.env、锁文件、KiCad本地状态或.DS_Store；源码S表达式辅助模块随PCB提供。包与逐文件hash在delivery/，包装审核见package-audit.json。

证据：validation/integration/result.json、integration/parity-before.json、pcb-drc.json、pcb-geometric-drc.json、sch-erc.json、netlist-pinmap-check.json。生成器用--sync-existing只修项目语义，铜线原样保留；之后从头生成也调用同一语义逻辑。

## 精确产物

用途 | 路径 | 内容
冻结软硬件架构 | hardware/specs/architecture.md | OEM USB HID + 独立ESP32-S3开发板，双USB/外部Hub，电脑运行Agent；LB1 ASCII + CRC16串口协议
官方核对引脚 | hardware/specs/pin-map.md、pin-map.json | GPIO4/5/6/7/8/9/10对应J1.4/5/6/7/12/15/16；v1.1板载RGB38/初版48均避开；官方文本、DXF与原理图缓存在references/
参数化CAD源 | hardware/cad/parameters.json、build_cad.py | mm单位，外壳/底板/光学孔/双出线槽/柱位与公差、屏框、原创云阶晶堡、六折雪花、定位底座及组件占位
CAD工程导出 | hardware/cad/exports/ | 20件逐件STL + 20件逐件STEP；lingban_assembly.step整机装配；lingban_exploded.step爆炸装配。当前零件以parts.json为准，无旧插座重复件
pitch图片 | hardware/renders/lingban_hero.png、lingban_exploded.png | 1800×1500透明Cycles渲染，带“AI概念展示 / 数字工程原型 / 非实物”标识
动画与源 | hardware/renders/lingban_turntable_concept.mp4、lingban_hero.blend、lingban_exploded.blend、lingban_turntable.blend、render_scene.py、finish_media.py | 720×720、约5秒完整转台视频；120帧24fps可编辑旋转源，视频每4帧抽样。raw/frames只作中间产物
可编辑PCB工程 | hardware/pcb/NOT-FOR-FAB/lingban_carrier.kicad_pro、.kicad_sch、.kicad_pcb | 36×76×1.6mm两层载板，开发板双排插座，灯/触摸/屏/DPDT物理开关线束，底面阻容，自包含符号和封装库
真实走线图 | hardware/pcb/NOT-FOR-FAB/plots/pcb-routed.svg、pcb-routed.png | 由实际KiCad铜线/焊盘坐标导出，511段铜线、17过孔、35条连接树边；无未布线连接
网表/装配清单 | hardware/pcb/NOT-FOR-FAB/lingban_carrier.net、.xml、BOM.csv、PnP.csv、PnP-kicad.csv | KiCad真实网表；底面SMD贴装坐标，D1标DNI；厂商须确认底视/顶视、原点与旋转
制造评审文件 | hardware/pcb/NOT-FOR-FAB/gerber-review-only/ | F/B铜、F/B阻焊、F/B丝印、底面锡膏、Edge.Cuts共8个Gerber；PTH/NPTH两份Excellon钻孔、钻孔图、gbrjob。不是下单包
工程/商业交接 | docs/hardware/engineering-and-manufacturing.md | 99/199/299/499/899电子机械差异、BOM批量/税/良率/NRE估算、7天样机计划、制造就绪矩阵、装配验收与工厂待确认尺寸
局部工具与校验 | 工作区hardware/tools/README.md（不随ZIP）、hardware/requirements.lock；hardware/validation/tool-integrity.json | CadQuery2.8.0、trimesh5.1.0、Blender4.5.3、KiCad9.0.7；官方哈希/应用签名验证；不依赖全局brew安装
精简交付包 | hardware/delivery/lingban_evt_a_review.zip、SHA256SUMS.txt | 供主控集成，不含tools目录、DMG、venv、缓存、挂载应用树、本地状态和视频逐帧中间文件

## 可重复运行命令

在仓库根运行；工具挂载/重建步骤见hardware/tools/README.md。

python3 hardware/pcb/build_pcb.py --sync-existing
python3 hardware/pcb/finalize_project.py
python3 hardware/pcb/export_and_verify.py
hardware/tools/venv/bin/python hardware/pcb/render_board.py
hardware/tools/venv/bin/python hardware/validation/validate_artifacts.py
python3 hardware/validation/integration/check_integration.py
python3 hardware/package_delivery.py

export_and_verify.py调用真实KiCad，parity检查同时启用--schematic-parity --exit-code-violations，另导出独立几何DRC和ERC，失败非零退出。当前命令使用工作区既有工具；精简ZIP不附带tools，可用已安装的等版本工具或以hardware/requirements.lock重建局部Python环境。CAD尺寸参数不是全部独立约束求解器；更改壳宽/壳长会调整放样，但安装坐标、OEM接口与装饰仍须检查Python参数与干涉，不能只改一个数字直接制造。

## 实际验证

- OpenCascade：当前20件BREP均有效、均为一个实体；两两正体积干涉 >0.05mm³ 为0。见validation/cad-brep.json、cad-intersections.json。不意味着局部法向壁厚、公差、强度或实物手感已通过。
- 导出STL：20件均封闭、水密、法向一致、正体积、单连通实体，见stl-mesh-check.json、artifact-check-summary.json。
- KiCad9.0.7：ERC 0违规；几何DRC 0违规、0未连接项；schematic parity 0，未靠规则忽略/排除消除报告。见sch-erc.json、pcb-drc.json、pcb-geometric-drc.json与kicad-command-results.json。ERC对象是无源载板触点，不证明ESP/外部模块电气特性。
- 36项官方选定脚/保留脚核对通过；49功能焊盘及33个明确NC焊盘与KiCad导出原理图网表完整名称一致（不再去掉/前缀），NC均单脚且无铜连接。见netlist-pinmap-check.json。本轮已只读核对LB1软件/固件、N8R8 profile及GPIO；主控报告两目标编译和HAL测试通过，本会话不重复编译/烧录。
- Blender官方SHA256匹配，Blender/KiCad应用codesign严格验证退出0；KiCad DMG内部校验有效。Python以官方PyPI元数据生成hash锁并从实测可信镜像执行--require-hashes --reinstall成功。见工具完整性/安装日志。
- 渲染由本地Cycles执行；视频由ffmpeg编码、ffprobe检查，见media-probe.json。城堡窗发光、光导环与屏幕文案是视觉示意/合成数据。

## 工程师/厂商确认后才能推进的点

1. 制造状态不提升到fab-candidate：D1为未冻结封装的ESD DNI占位；RGB、OLED、DPDT及插座未全部冻结MPN/供应商图纸。需要真实TVS方案、线束脚序、装配方向和DFM审核。
2. 电气未实测：开发板稳压器/USB能力、启动与无线峰值、满白屏/满亮、隐私断电反灌、触摸阈值/ESD、温升。初版默认USB-UART且关闭Wi-Fi/BLE；通用500mA端口不能按1A电源使用。
3. 隐私边界明确：机械DPDT切屏/灯电源并给GPIO状态，断线默认隐私；不硬断USB、触摸线路或主机Agent。实装HAL detach PWM/Wire.end并将GPIO4–9置INPUT，无内部上拉；SW3V3断电后不显示privacy灯/屏，只由UI/开关本体指示。触摸默认阈值0、禁用采集，屏仅状态图标；没有音视频、生理诊断、员工评分或秘密采集。
4. 机械需实物ECO：OEM外形/固定孔/镜片到桌面高度/光学中心、按钮杠杆与滚轮结构；屏模块厚度/孔位和屏框防脱卡扣；装饰底座防脱；隐私开关固定孔与实际止拉件；铜螺母/底脚/螺钉/透明料收缩和后处理。当前名义126×80×54，实际曲面可能超调，完整包络见assembly-envelope.json。
5. RF净空未完成整机验证：PCB有禁铜区，但附近金属紧固件/铜螺母仍需移位或改非金属，按实际模块天线参考布局复审；不宣称无线/EMC验证通过。
6. 下阶段是7天样机：到货、工程师签字、电气上电与机械验收均是门槛；30天试销受法规/认证/小批量验收限制。没有厂商报价，所有成本明确批量、税、良率和NRE假设；VC/退出估值不属于本次硬件事实。

specs/已与实装LB1/GPIO同步，继续使用hash未变的带标识PNG/MP4供pitch，最后将NOT-FOR-FAB工程交给电子/机械工程师审核。不要把hardware/downloads、tools/venv、uv-cache、mount-*加入Git或对外包。

## 本轮影响文件

- 接口与商业：hardware/specs/architecture.md、pin-map.md、pin-map.json；hardware/README.md、本文件；docs/hardware/README.md、engineering-and-manufacturing.md。
- PCB语义与复现：hardware/pcb/build_pcb.py、新增semantic_sync.py与本地sexpr.py、finalize_project.py、export_and_verify.py、render_board.py、PCB README；NOT-FOR-FAB中的PCB/原理图、库、BOM、导出网表/制造文件/PCB图已刷新。铜线几何未改，原项目规则未加忽略项。
- 验证与交付：hardware/validation/validate_artifacts.py、README、integration/和当前检查报告；hardware/package_delivery.py、用于无工具环境交付的hardware/requirements.lock、delivery/ZIP/manifest/SHA/audit。CAD与产品PNG/MP4/Blender源均未修改；软件、固件及商业主文只读。

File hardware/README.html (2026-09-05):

# 灵伴 LINGBAN / Crystal Mouse EVT-A

实际CAD与真实布线PCB数字原型已交接；全部制造文件NOT-FOR-FAB。 从COMPLETION.md查看精确产物、复现命令、实际测试与未验证门槛。

- 主控先传架构与LB1 ASCII + CRC16串口协议、官方核对引脚给固件。
- CAD：20件编辑源/STEP/STL，整机和爆炸STEP；底壳、透明上壳、原创独立晶堡/雪花、屏框与组件占位。
- 渲染：带概念标识的透明PNG、爆炸PNG、本地转台MP4与可复现Blender源。
- PCB：可编辑KiCad、实际511段走线/17过孔、BOM/PnP/网表/Gerber/钻孔，真实ERC/几何DRC/schematic-parity报告（均0）。
- 工程与制造：99–899分档、299核心量产目标与单列DevKit样机成本、BOM批量/税/良率/NRE、七天样机、装配与验收。
- 验证；工具安装与完整性；精简交付包在delivery/，不含tools/cache/本地状态。

OEM USB HID + 独立ESP32-S3开发板，双USB或外部Hub；电脑运行Agent。没有融合USB、硬件大模型、已打样/认证/量产或医疗/员工评分声明。主控负责Git、集成与发布；大体积局部工具/DMG/缓存不进交付包。

最终集成：LB1 ASCII+CRC16为唯一设备协议；GPIO/N8R8不变，隐私断SW3V3后灯/屏不显示privacy。49功能节点＋33明确NC节点与原理图完整网名一致，4个机械孔为board_only。既有CAD和pitch渲染hash不变，结果见validation/integration/result.json。

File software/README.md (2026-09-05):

# 灵伴 LINGBAN · 本地主动 Agent 原型

全部为合成演示数据。电脑运行确定性规则 Agent，透明晶鼠为原创概念插画和交互模拟。默认离线；可显式启用受限的第三方模型合成测试。无外部消息发送、录音摄像、生理推断或员工评分。名称与商标待检索。

## 一键启动

```sh
./software/start.sh
```

Python 3.9+，仅标准库，无需 pip。默认 `http://127.0.0.1:8765`，数据库在 `software/data/lingban.sqlite3`。终端显示员工和企业两个带片段令牌的链接；打开后令牌从地址栏清除，仅在页面内存持有。重启会轮换令牌，不恢复撤销的授权。链接持有者拥有对应角色权限，请勿分享。

```sh
./software/start.sh --port 8766 --db data/custom.sqlite3
```

注意脚本工作目录为 software，因此自定义数据库建议使用绝对路径或 `--db data/custom.sqlite3`。板级与可选模型集成当前共通过 59 项离线回归测试；完整接口、测试及限制见 `COMPLETION.md` 和 `../docs/software/README.md`。

## 快速体验

1. 员工工作台点击「会议将近」或「项目阻塞」，查看提醒及判断依据。
2. 点击「专注与休息」：新提醒暂缓；点击「结束专注」查看休息建议。
3. 批准待办动作，只生成本地 outbox；拒绝无 outbox。
4. 另开企业令牌链接，初始可见 5 位合成员工的聚合。员工撤销分享，企业立即隐藏结果。

服务端根据 Bearer 令牌识别角色和归属。页面没有权限切换后门。插件只做 manifest 注册和受限 API 调用，不加载第三方代码。串口模拟与固件见 `../firmware/README.md`。

## 复现测试

本轮板级/LB1固定回归从仓库根目录执行 `./software/test-integration.sh`，不包含并行模型测试。全量集成测试由主控执行：

```sh
cd software
python3 -m unittest discover -s tests -v
```

## 临时真实模型测试

仅本机明确启用：`./software/start.sh --local-model-test`（从仓库根目录执行）。配置只从权限为 0600、Git 忽略的根 `.env` 读取，容器镜像不包含该文件。员工在行动审批区同意本次固定合成场景后生成草稿，仍须批准才保存本地 outbox。默认启动不调用模型。完整预算、复现与实测见 [MODEL_INTEGRATION.md](../docs/software/MODEL_INTEGRATION.md)。

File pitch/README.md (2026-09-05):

# 灵伴 LINGBAN 中文VC演示稿

最终交付是 **18页、16:9、中文** 的可编辑PPTX、同内容PDF、自包含HTML和逐页讲稿。指定会话口径为 gpt-6-astra / high。所有本会话写入限定在 `pitch/`，主控负责后续集成、Git和对外发布。

## 最终交付

**唯一发布入口：`deliverables/final-20260906/`**。旧release已移至`.build/archived-deliverables/`，不作为当前版本：

- [可编辑PPTX](deliverables/final-20260906/lingban-vc-deck.pptx)
- [同内容PDF](deliverables/final-20260906/lingban-vc-deck.pdf)
- [自包含HTML](deliverables/final-20260906/lingban-vc-deck.html)
- [逐页演讲稿](deliverables/final-20260906/speaker-notes.md)
- [与幻灯片一致的正文](deliverables/final-20260906/deck-content.md)

PPTX包含原生文字、6张原生表格及可编辑架构图，18页均写入演讲者备注和来源。产品图作为嵌入图像，可替换或缩放；封面原创图同时提供[SVG源文件](assets/crystal-mouse.svg)。PDF通过bundled LibreOffice直接从最终PPTX生成，包含已嵌入的中文字体。HTML将最终PDF的18张1600×900渲染页完整嵌入，不依赖网络、字体下载或相邻文件；其展示页为图像，编辑请使用PPTX或构建源代码。

## HTML使用

双击HTML在浏览器打开。方向键、空格、PageUp/PageDown切页，Home/End跳到首尾，N显示或隐藏当前讲稿，F进入或退出全屏，P打开打印。移动端支持按钮及横向滑动。全屏控制栏靠近底部悬停或聚焦后显示。打印样式输出全部18页，不包含操作栏或讲稿。

## 内容和口径

1. 首发299元，99/199/499/899元为目标价格及后续方案，1499/3999仅生态探索。透明晶鼠、原创城堡、电脑承担AI、HID与ESP32-S3伴随模块分离。
2. 个人先受益，企业只看逐项明确批准的业务结果和≥5人聚合。禁止个人钻取、秘密采集、键盘记录、情绪/生理员工评分和自动雇佣决策。人数阈值不等于匿名化。
3. 协议页已按软件源码及验收记录同步：**MCP 2025-06-18 stdio JSON-RPC tools子集**，覆盖initialize、notifications/initialized、ping、tools/list、tools/call，4个本地工具；**A2A 0.3.0 JSON-RPC子集**，覆盖Agent Card、message/send、tasks/get，同步新建文本摘要任务、按身份隔离和持久化。页面列出实际测试覆盖与主要未覆盖项，讲稿列出完整限制。无官方SDK端到端互通或认证。本稿以电脑端本地规则演示为验收范围，审批只写本地outbox，没有外部发送器；可选模型适配由主控独立验收，不纳入本稿验证。最新软件完成记录报告LB1集成代码与模拟测试修复完成，仍待实机验证，未接设备、未验证硬件连通。
4. 299元版贡献66.51元、22.24%、827台/月来自商业CSV。1000台规模成本108元含10元损耗预留，良率未验证；13%销项税预留、不抵进项。小批170元成本时贡献约3.27元。
5. 最新研究已补充Microduck官方产品页：预售价399美元、税运另计，不能再沿用“查无标价”。Violoop仍为预发布预约页，399美元起、优惠后369美元起。均无本次可核验销量或交付实绩。
6. **500万元是本方案提出的建议融资目标，并非用户原文指定金额**，用途200/100/60/80/60万元，与商业计划第11节一致。独立运营模型仍是假设起始60万元、NRE12万元、月固定5.5万元，基准10个月期末现金60494.30元（约6.05万元）。500万元建议尚未建立分月扩张现金模型，不报告其跑道、收入、估值或回报，也不声称融资到账。
7. 7天5台样机和30天试销均为有门槛的计划。未声称客户、订单、收入、团队履历、实物打样或认证完成。10个月1亿美元退出只在收束页及讲稿中列为无估值依据、无收购承诺的目标情景。

## 来源和素材

商业与研究来源只读 `docs/business/` 与 `docs/research/`；协议实现另核对 `software/COMPLETION.md`、`docs/software/README.md`、`docs/software/protocols.md`、`software/lingban/protocols.py`、`mcp.py` 和现有测试输出，关键数据文件及研究快照版本的SHA-256保留在 [source-manifest.json](qa/source-manifest.json)。市场20人研究、200人/30团队名单等均为目标或假设，没有转写为实绩。讲稿标出逐页来源。

封面继续使用明确标注“原创产品概念示意”的SVG。第5页已同步本轮最新 `hardware/renders/hero_raw.png` 概念建模图，裁去空白背景并保留产品主体，原图副本保留在 `assets/hardware-hero-source.png`。素材裁剪参数及哈希见 [assets/manifest.json](assets/manifest.json)。两图均标为概念示意，不能替代实物。

## 可重复构建

在仓库根目录运行：

```bash
./pitch/build.sh review-20260906
```

每次使用新的版本名，不覆盖已定稿文件。输出在 `pitch/deliverables/<版本>/`，中间文件和报告在 `pitch/.build/<版本>/`。源文件：`src/build.mjs`、`src/postprocess.py`、`src/verify-html.mjs`。生成后仍须逐页目检再选择发布版本。

脚本读取已由商业会话生成的财务CSV，不运行会写商业目录的重算脚本。关键模型假设变化时会停止并要求同步讲稿，避免固定叙事与新数据混用。非数字文字及研究事实变化需要编辑者复核。源码与字体配置均仅写 `pitch/`。`src/postprocess.py`还输出deck-content.md，并确保286段PPTX文字都能在对应PDF页中找到。

运行时定位自 `/Users/lwblx/.cache/codex-runtimes/codex-primary-runtime/runtime.json`：

- Node: `dependencies/node/bin/node`，v24.19.0
- Node packages: `dependencies/node/node_modules`，`@oai/artifact-tool` 2.8.59
- Python: `dependencies/python/bin/python3`，3.12.14
- **仅用bundled LibreOffice**: `dependencies/bin/override/soffice`，指向runtime的headless LibreOffice 25.2
- Poppler: `dependencies/bin/override/pdftoppm`
- 字体：本机已存在的 `Hiragino Sans GB`，仅通过仓库内Fontconfig配置加载，不修改全局设置、不打包系统字体文件。
- HTML验证使用bundled Playwright模块与 `/Applications/Google Chrome.app/Contents/MacOS/Google Chrome` 的隔离headless会话。无新增浏览器或依赖下载。

`load_workspace_dependencies`本轮未暴露，因此使用用户指定runtime。模板picker不可用，使用用户指定的白/深墨蓝/青绿视觉。PPTX及PDF技能的artifact开始标记脚本在初次创作前各执行一次；本次内容同步在首次修改前各执行一次edit标记，构建重试不重复标记。不使用python-pptx、不修改runtime依赖。

## 实际验收与限制

详见 [QA报告](qa/QA-report.md) 与 [全稿拼图](qa/contact-sheet.jpg)。本次重渲染18页，检查受影响的第5/6/16页及全稿缩略图，检查包结构、字体策略、原生表格、融资金额合计、PPTX/PDF正文、18页讲稿与HTML一致性。既有HTML脚本15项检查通过，实际打印18页。软件测试结果引用已有验收记录，本融资稿任务未重跑软件/固件测试。用户已有Chrome profile对8765演示的拦截与本离线file://HTML验收无关，本次未访问8765、未绕过该拦截。

**没有在Microsoft PowerPoint或Google Slides中打开、编辑并保存验证。** PPTX依赖目标电脑有兼容中文字体，跨平台替换字体可能影响行宽，正式路演前建议在实际放映电脑检查。PDF和HTML已固化中文外观。未验证真实硬件、连接器/官方协议SDK端到端互通、用户留存、供应商报价、融资可得性及法律/认证结论。

## 中间文件

`src/`是可维护构建源，`assets/`是素材源及副本，`qa/`是最终验收证据。`.build/`包含草稿、旧版、字体缓存、独立LibreOffice配置、渲染页、HTML打印检查和node_modules符号链接，均非对外交付。主控不要把`.build/node_modules`或缓存打包进项目发布物。

本任务未执行Git操作、未读取原始需求/input/1.txt或env文件、未联系外部人员、未付费。本轮没有修改`pitch/business-plan/`及其中的BP PDF，该目录由另一任务负责。

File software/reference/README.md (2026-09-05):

# 只读协议参考

- `a2a-v0.3.0.json`：A2A v0.3.0 官方 schema，Apache-2.0，许可见 LICENSE-A2A。
- `mcp-2025-06-18.ts`：MCP 2025-06-18 官方 schema，MIT，许可见 LICENSE-MCP。

来源标签 URL 与本地 SHA-256 见 `../../docs/software/protocols.md`。schema 用于实现核对与测试，不参与本地服务运行。没有使用 ../active_agent 的源代码。

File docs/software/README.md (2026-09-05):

# 灵伴软件与固件验收资料

本会话只实现 `software/`、`firmware/`、`docs/software/`；Git、主板定型与发布由主控制器负责。未访问原始需求文件、任何 .env 或已有密钥，未读取或修改 `../active_agent`；本次代码为独立实现，无该项目代码来源。

## 运行与数据流

```sh
./software/start.sh
./software/test-integration.sh
```

Python 3.9+ 标准库 HTTP 服务 + SQLite，默认仅 `127.0.0.1:8765`。员工/企业使用启动时生成的不同 256-bit 随机 Bearer 令牌。终端输出的片段链接属于本地演示凭据，不能作为公开材料。页面清除 URL 片段，令牌只在内存中保存；不使用 localStorage、Cookie、第三方脚本或外部字体。重启清除旧令牌。SQLite 中仅存令牌 SHA-256。

```text
合成日程 / 任务事件 → 鉴权与权限 → 幂等事务 → SQLite 任务记忆
                                          ↓
                               每秒 worker 评估当前证据
                                 ↓ 新版本 / 新状态
                          专注静默与同规则同任务冷却
                                 ↓
                    带依据提醒 → 用户反馈 → 模拟灯光/小屏
                                 ↓
                   动作提案 → 人工批准 / 拒绝 → 审计
                                 ↓ 批准一次
                           本地 outbox（无发送器）
```

任务版本只在任务字段实际改变时增加。幂等键按员工隔离，相同键同内容返回原事件，不同内容返回 409。新幂等键但相同任务状态不会制造新提醒。冷却按员工、规则、任务计，默认 300 秒；新证据在冷却后仍有效才触发。专注期间所有主动提醒暂缓，结束后按当前状态重评；已解决的阻塞和已过期的会议不会补发。休息来自用户设置的计时器，无生理检测。提醒反馈支持有帮助、忽略、安静 10 分钟。API 名 snooze 保留兼容，但含义是暂停全部主动提醒 10 分钟，不承诺同一证据到期再通知；新证据在安静期后仍有效才触发。

审批采用 SQLite `BEGIN IMMEDIATE`，动作状态只能从 pending 转为 approved 或 rejected；outbox.action UNIQUE，重复相同决定返回 duplicate；终态改变返回 409。所有批准只持久化本地内容。没有邮件、聊天、支付或网络动作执行器。

## 权限与撤销

| 身份 | 可读 | 可写 | 不可访问 |
| --- | --- | --- | --- |
| 员工 | 自己的任务、提醒、动作、outbox、审计、设备 | 自己的事件、反馈、审批、授权及明确业务分享 | 他人数据、企业聚合 |
| 企业 | 本组织至少 5 位明确授权员工的业务聚合 | A2A 只读摘要任务的协议状态 | 个人工作台、事件、个人动作、录音、生理数据、员工评分 |
| 插件令牌 | manifest 授予的 tasks:read，且仅所属员工 | 白名单事件 / 灯光状态 | 审批、授权、分享、注册其他插件、A2A、隐私开关 |

企业结果只包含明确分享的 completed/blocked 整数。无按员工、群组任意过滤、排名、个人结果明细或历史聚合查询接口；人数仅显示分段。4 人及以下隐藏数值和精确人数。单次雇佣同意不构成共享授权。

撤销事务删除共享行，并删除本组织企业身份缓存的全部 A2A 摘要任务，避免历史 tasks/get 继续返回撤销前的聚合。重新授权不会恢复旧分享；必须再次明确提交。SQLite 开启 secure_delete，但本地磁盘/WAL、备份及浏览器已经看到的内容不等同于可取回；本原型不声称法证级擦除。企业 API 使用 no-store，页面每 2.5 秒刷新。>=5 仅满足本次演示门槛，不构成差分隐私，持续观察与外部知识仍可能推断变化，真实部署需固定发布窗口/队列和更严格隐私设计。

输入结构禁止音频、影像、生理字段、键盘记录及评分类型。自由任务文本是员工主动提供的合成内容，不执行语义分类；本原型不能保证自由文本中永远没有个人信息。企业从不读取自由任务文本。

## 插件

manifest 权限白名单：`events:write`、`tasks:read`、`hardware:write`。事件另需 `event_types` 白名单。manifest 登记不执行代码、不访问 URL、不安装依赖，不宣称 OS 沙箱。通过 `/api/plugins/token` 生成专用插件令牌。服务端从令牌绑定插件身份，省略或伪造 plugin_id 无法绕过权限；插件不应持有员工主令牌。修改 manifest 后下一次请求重新检查权限。

## 验证范围

自动化测试和接口细节见 [COMPLETION](../../software/COMPLETION.md)、[HTTP 示例](http-examples.md)、[协议子集](protocols.md)、[部署边界](deployment.md)、[固件说明](../../firmware/README.md)。实际测试输出在 `software/test-output/latest-tests.txt`；该目录为运行产物，不应提交数据库或令牌。

主控已用独立 headless Chrome 152.0.7977.66 与实际 HTTP 完成 **14/14 UI 链路检查**，errors=[]，证据为 `docs/verification/browser/report.json` 及同目录截图。本轮读取并引用该证据，未重复浏览器测试。用户现有 Chrome profile 打开本地地址仍 `ERR_BLOCKED_BY_CLIENT`，保护未关闭；这与独立浏览器验证通过是两件事。

板级集成修复、两种固件配置及待主控协调的旧硬件文档冲突见 [INTEGRATION_NOTES](INTEGRATION_NOTES.md)。LB1精确规范与104行共用golden见 [serial-protocol](serial-protocol.md)。

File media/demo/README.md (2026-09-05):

# 灵伴 · 实际软件浏览器演示

[播放28秒演示](lingban-software-demo.mp4) · [六帧联系图](contact-sheet.jpg) · [来源/剪辑记录](provenance.json)

这是已运行软件的隔离Chrome浏览器录屏剪辑，与另外8条MiniMax AI产品概念片分开交付。常驻标签为「真实软件浏览器录屏 · 合成数据 · 设备模拟 · 离线规则」。没有硬件实测、真实业务数据或联网模型运行声明。

采用2026-09-06 01:50:09（上海时间）完成的最新成功QA员工/企业录制，与同次14项全通过的[报告快照](qa-report-snapshot.json)及截图时间一致。排除所有更早录制，包括01:49:20的一秒失败录制。员工15秒源与企业4.48秒源均为1440×960；成片放入1920×1080说明画布，不冒称原始浏览器录制为2K。

| 成片时间 | 画面与实际行为 |
|---|---|
| 00–06秒 | 员工收到会议提醒，本人批准后写入本地outbox，不外发 |
| 06–12秒 | 开启模拟隐私开关，模拟触摸被禁用 |
| 12–16秒 | 企业仅看到明确授权的业务汇总 |
| 16–21秒 | 员工撤销分享，已有共享数据被删除 |
| 21–28秒 | 同次成功验证截图定格：分享不足5人，企业汇总隐藏 |

前四段均是实际操作录像，标注0.5×慢放以便阅读。末段明确标注「同次成功验证截图定格」，原因是QA的移动布局检查会改变录屏视口；没有将静态截图伪装成连续操作。员工源8.72–8.84秒的fullPage截图瞬时视口变化已精确剪除，其他移动测试尾段也未使用。

所有选用片段都已进入认证后的工作台，未包含登录过程、令牌输入框或浏览器地址栏。原登录输入已核实`type=password`；制作脚本没有读取凭据文件、令牌或API Key。实际抽帧没有看到令牌明文。声轨为本机已有Tingting通过系统say生成的中文说明，未下载声音、未调用付费语音。

实际验收：精确28.000秒，1920×1080，25fps，H.264/AAC；[实测音量](loudness.json) −16.19 LUFS、−1.50 dBTP；全部700帧执行灰色视口异常检查，0帧异常，见[检查记录](viewport_check.json)。另目视六帧联系图，确认常驻标签、分段说明、隐私开关与撤销结果可读。像素检查不是OCR或综合秘密检测；这里通过仅选认证后工作台区间、排除登录内容来避免令牌入镜。未声称人工听音或完整UI逐帧验收。

从项目根复现：

```sh
python3 media/demo/build_demo.py
```

脚本仅读取明确选定的既有录制和成功QA截图/报告，离线剪辑与本地配音，不启动浏览器、服务端口、用户全屏或其他应用。需要本机原始`.local/qa-recording`源文件及已安装ffmpeg/Pillow。成片展示的是该次成功QA快照，不替代此后软件改动的重新验证。大文件发布由主控统一处理。

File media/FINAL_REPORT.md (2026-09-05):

# 灵伴 LINGBAN · 最终视频报告

核验时间：2026-09-05T18:06:21.358758+00:00。**8条成片及2分钟合集全部完成**。

[播放2分钟合集](final/LINGBAN_8_concepts_2min.mp4) · [8款总览图](qa/ALL_8_CONCEPTS.jpg) · [合集来源记录](final/LINGBAN_8_concepts_2min.provenance.json)

## API状态与预算

八个既有MiniMax-H3任务全部经API确认`succeeded`，每项用量15输出秒、0输入视频秒；01/02各1张首帧参考图，03–08无图输入。确认输出总计120秒。仅轮询和下载既有任务，未重提、未付费重做。

**本地预占96.00元，用户上限100.00元，未预占额度4.00元。** 按已抓取官方2K刊例价0.80元/秒，120秒对应96.00元；各任务≤5张图免费。此为预算账本与官方刊例价核算，不是账户账单结算凭证。未查询账单、余额、发票或退款，不声称账户已最终扣款96元；4元也不是账户实际余额。无收费视频参考或Context-IR，无付费语音。

[官方能力/价格核验](API_CAPABILITIES.md) · [公开来源及快照哈希](sources.json) · [脱敏API状态与成片规格](qa/final_specs_status.json)

## 成片

全部单片：**15.000秒、2560×1440、24fps、H.264**，音轨AAC / 48kHz / 单声道。原片全部为2560×1440、24fps、实际15.084秒，带AAC / 32kHz / 双声道及MiniMax AIGC元数据；后期保留原像素尺寸，仅裁至15秒，没有放大、静图补时或付费补拍。

所有片常驻「AI概念演示 · 非已生产实机」及「外观与功能待工程验证 / 屏幕内容为合成示意」，附中文旁白、字幕。旁白使用本机已有Tingting，通过系统say本地合成；保留原声10%线性增益混入。

| 片段 | API | 实测LUFS / dBTP | 检查与来源 |
|---|---|---|---|
| [01 晶鼠 · 透明城堡产品 Hero](final/01_crystal_mouse_focus.mp4) | succeeded | -16.00 / -1.50 | [4帧联系表](qa/01_crystal_mouse_focus_contact.jpg) · [来源/后期](final/01_crystal_mouse_focus.provenance.json) · [音量](qa/01_crystal_mouse_focus_loudness.json) |
| [02 晶鼠 · 由人批准的办公搭档](final/02_crystal_mouse_workday.mp4) | succeeded | -16.09 / -1.51 | [4帧联系表](qa/02_crystal_mouse_workday_contact.jpg) · [来源/后期](final/02_crystal_mouse_workday.provenance.json) · [音量](qa/02_crystal_mouse_workday_loudness.json) |
| [03 键盘边栏 · 专注节奏](final/03_keyboard_sidecar.mp4) | succeeded | -16.06 / -1.50 | [4帧联系表](qa/03_keyboard_sidecar_contact.jpg) · [来源/后期](final/03_keyboard_sidecar.provenance.json) · [音量](qa/03_keyboard_sidecar_loudness.json) |
| [04 桌面晶球 · 私人待办入口](final/04_desktop_orb.mp4) | succeeded | -16.27 / -1.50 | [4帧联系表](qa/04_desktop_orb_contact.jpg) · [来源/后期](final/04_desktop_orb.provenance.json) · [音量](qa/04_desktop_orb_loudness.json) |
| [05 显示器挂件 · 看得见的静音](final/05_monitor_charm.mp4) | succeeded | -16.04 / -1.51 | [4帧联系表](qa/05_monitor_charm_contact.jpg) · [来源/后期](final/05_monitor_charm.provenance.json) · [音量](qa/05_monitor_charm_loudness.json) |
| [06 会议 Puck · 明确共享的会议结果](final/06_meeting_puck.mp4) | succeeded | -16.17 / -1.51 | [4帧联系表](qa/06_meeting_puck_contact.jpg) · [来源/后期](final/06_meeting_puck.provenance.json) · [音量](qa/06_meeting_puck_loudness.json) |
| [07 桌垫模块 · 温和休息建议](final/07_deskmat_module.mp4) | succeeded | -15.89 / -1.51 | [4帧联系表](qa/07_deskmat_module_contact.jpg) · [来源/后期](final/07_deskmat_module.provenance.json) · [音量](qa/07_deskmat_module_loudness.json) |
| [08 机器人扩展 · 由人确认的小任务](final/08_robot_extension.mp4) | succeeded | -16.40 / -1.50 | [4帧联系表](qa/08_robot_extension_contact.jpg) · [来源/后期](final/08_robot_extension.provenance.json) · [音量](qa/08_robot_extension_loudness.json) |

合集按01–08顺序，视频与音频均从0.000开始、长120.000秒，容器精确120.000秒，2560×1440。拼接时修正AAC预滚时间戳，仅重编码音频去除21ms容器尾差，视频不二次编码。 [原片元数据脱敏记录](qa/source_metadata.json) · [合集音量](qa/compilation_loudness.json)

## 目视检查与边界

已实际查看8条各1/5/9/13秒的联系表，共32帧。中文标签和字幕可读、未裁切；主要物体可辨识，透明/晶体城堡风格贯穿。检查是抽帧和客观音量测量，不冒称完整逐帧验收或人工听音。

- 01/02以参考CAD起镜，随后转为写实鼠标；外壳、内部城堡与线缆形态有生成变化，并非严格CAD尺寸一致。只作外观/交互概念。
- 06会议人数与原始六人分镜不完全一致，圆盘演绎成透明圆顶摆件；不作为真实同意记录或会议系统验证。
- 07桌垫模块未证明夹持结构可实现；健康叙事仅休息建议、明确不作医疗判断。
- 08机器人路线靠近桌边，急停/安全距离没有工程验证；不得据此承诺运动安全。
- 生成屏幕存在合成文字/图形，旁白中的提醒、审批与共享均是叙事设想，不证明软件与硬件已联调。

原片保持不变，保留原提供方AIGC元数据。后期重编码不冒称原始数字签名仍绑定成片；来源哈希与成片哈希独立记录。企业内容禁止解读为隐蔽监控或个人情绪/生理评分。

## 复现

从项目根运行 `python3 media/final/produce.py`；脚本只做本地后期，完成项可跳过，不访问API、凭据或预算账本。八条齐全时制作合集。公开报告不包含Key、原始凭据输入、私有账本下载URL或认证响应全文。

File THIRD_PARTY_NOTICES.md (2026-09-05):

# 第三方来源与发布前许可核对

本仓库为用户个人私有工程与融资资料库。灵伴/晶鼠命名、外观和相关内容不表示已获商标、专利或第三方背书。

- `docs/research/snapshots/`：Microduck、Violoop、Espressif及法规的研究快照。来源与抓取记录见同目录上级`sources.json`。它们是事实核验材料，不是本产品的界面、美术或销售文案。公开发布产品包时排除完整第三方快照。
- `software/reference/`：MCP与A2A的版本化规范，用于核对协议；不等于官方认证、实现授权背书或已通过互操作测试。再分发时按对应上游版本许可保留版权声明。
- `hardware/downloads/`、`hardware/tools/vendor/`及本地工具环境不进入Git与厂商资料包。Blender、KiCad、CadQuery及其它工具各自保留许可；使用工具生成文件不表示继承其品牌。
- 软件吸收相邻本地`active_agent`项目的主动事件、记忆、审批和outbox设计思路。具体复用与独立实现说明以`software/README.md`为准，不向本仓库复制其本地凭据或业务数据。
- 融资PPTX通过本机授权运行时的`@oai/artifact-tool`生成；运行时和商业字体不打包分发。
- MiniMax-H3片源来自本用户授权付费生成，保留任务、费用和剪辑来源记录。成片常驻标记AI概念展示，不宣称是实物测试影像。

公开开源、插件商店上架及实际商业发售前，应由负责人核对最终依赖锁文件、上游license/notice、字体嵌入与生成内容使用条款，选择正式产品许可。此内部工程资料不代替上述具体许可检查。

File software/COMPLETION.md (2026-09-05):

# 软件会话完成记录

本轮集成修复完成时间：2026-09-06 02:12（Asia/Shanghai）。只修改 `software/`、`firmware/`、`docs/software/`，未操作 Git。未读取原始需求文件、.env、已有密钥或 `../active_agent`；无外联消息、付费模型、付费视频、厂商联系或系统全局修改。

## 本轮主控集成修复

已读 HARDWARE_REVIEW / REVIEW_FINDINGS 与实际 pin-map，修复共阳LED active-low PWM、隐私断电高阻及首次初始化时序。新增共用 Controller mock HAL 验证和 N8R8 / USB-UART 的 EVT-A profile；保留全-1 safe profile。LB1 为唯一现行协议，104行冻结golden由Python/C++共用，GET/PING连续5秒失效清握手与输出，返回安全offline；没有ttl_ms。

前轮R1任务初次INSERT和R2撤销A2A缓存修复保留，新增R2同messageId重放三个派生字段回归。A2A内容类型错误按官方0.3.0改为-32005。snooze沿用UI“安静10分钟”，明确不承诺同证据到期再通知。

请主控按 [INTEGRATION_NOTES](../docs/software/INTEGRATION_NOTES.md) 协调硬件旧文档；软件会话未越界修改硬件目录。未启动持久业务服务，临时HTTP测试服务已由测试退出清理，启动与最终推送交还主控。

## 运行

从仓库根目录：

```sh
./software/start.sh
```

Python 3.9+，stdlib 零运行依赖 + SQLite，默认 `127.0.0.1:8765`。打开终端显示的员工/企业角色链接。令牌在启动时生成并轮换，仅存哈希；链接不写入文档。合成演示数据自动初始化，撤销状态跨重启保留。

```sh
./software/test-integration.sh
# 本轮复用仓库内缓存，实际构建 safe 和 EVT-A 两个目标：
PLATFORMIO_CORE_DIR="$PWD/firmware/.platformio" PLATFORMIO_SETTING_ENABLE_TELEMETRY=No \
  firmware/tools/venv/bin/python -m platformio run -d firmware
```

## 已交付

- 暖白、墨蓝、青绿的中文响应式 Web 工作台，原创透明城堡晶鼠 SVG；员工/企业角色由服务端令牌强制区分。界面全局标注 DEMO / 合成数据，硬件模拟与命名待检索说明明确。
- 事件摄入和按员工隔离的幂等键、SQLite 任务记忆、后台 worker、证据版本解释、冷却、专注静默、非医疗休息计时器与提醒反馈。
- 人工动作审批和审计；并发批准最多写一次本地 outbox，拒绝无 outbox，没有对外发送器。
- 明确授权 + 明确提交业务结果；企业只见本组织至少 5 人聚合。撤销删除共享行及企业 A2A 历史聚合缓存，重新授权不复活旧数据。
- manifest 权限校验及专用插件令牌；省略 plugin_id 也不能越权。插件无任意代码执行，不能审批、授权或解除隐私开关。
- 模拟灯光、触摸、隐私开关、小屏逻辑状态；有真实 POSIX 串口桥、协议模拟器、CRC、版本/会话协商、16项FIFO重试窗口、严格UTF-8 hex、5秒offline和隐私高阻控制。
- MCP 2025-06-18 stdio JSON-RPC：initialize、initialized、ping、tools/list、tools/call 与错误。
- A2A 0.3.0：Agent Card、message/send、tasks/get、同步任务生命周期与持久化。正式方法与字段，支持子集，未认证。
- 一键场景：会议将近、项目阻塞、专注与休息、撤销企业分享。
- 启动脚本、Dockerfile、HTTP 示例、部署边界、官方版本化 schema 参考及许可、ESP32-S3 PlatformIO 固件和硬件无关 C++ 自检。

## 实际验证结果

| 检查 | 实际结果 |
| --- | --- |
| 启动与HTTP | 前轮一键启动成功；本轮测试实际启动本地临时HTTP服务完成协议/鉴权/审批链路，未留下持久服务 |
| `./software/test-integration.sh` | **48 项本轮固定范围 unittest 全部通过**，本轮 2.208 秒；包含真实 HTTP、worker、并发审批、MCP 子进程和模拟串口桥 |
| `./firmware/test.sh` | C++11 + `-Wall -Wextra -Werror` 编译并执行共享协议核心、104行冻结golden和实际Controller的mock HAL，PASS |
| Python 串口自检 | CRC、握手、去重和隐私优先，PASS |
| Python/C++ 交叉验证 | 同一104行fixture逐字节通过，含5秒边界、UTF-8/CRC错误、FIFO和隐私；mock含millis回绕与硬件调用顺序 |
| `node --check software/web/app.js` | PASS |
| `python3 -m compileall -q software/lingban` | PASS |
| PlatformIO safe | **SUCCESS**，RAM 19,964 B，Flash 328,405 B，binary 328,768 B |
| PlatformIO EVT-A | **SUCCESS**，RAM 19,964 B，Flash 332,461 B，binary 332,832 B；两个目标构建总计5.713秒 |
| 独立浏览器验证 | 主控隔离headless Chrome 152.0.7977.66，**14/14链路通过**、errors=[]；本轮读取 `docs/verification/browser/report.json` 与截图证据，不重复宣称自行运行 |
| 用户现有Chrome | 仍 `ERR_BLOCKED_BY_CLIENT`，未关闭保护；与独立浏览器已通过须区分 |
| Docker build/run | 未验证：本机 Docker daemon 未运行；未启动或修改系统服务 |
| 实际硬件 | 未接设备、未烧录、未板级验证，不声称打样或认证完成 |

本轮测试明细 `software/test-output/integration-tests.txt`；固件构建日志 `firmware/build/integration-build.log`。这两个目录及数据库、工具缓存列入各自 .gitignore。

两个固件的大小与SHA-256、测试数量和证据来源见 [INTEGRATION_RESULTS.json](../docs/software/INTEGRATION_RESULTS.json)。

固定范围为 `test_core.py`、`test_http.py`、`test_protocols.py`，`test-integration.sh` 不发现或执行并行新增的 `test_model.py`，不读 .env。原有 `test.sh` 仍由主控用于全仓集成测试。

覆盖项目：幂等与键冲突、状态相同不重提醒、证据变化与冷却、专注及解除、阻塞解决、会议时间窗口、后台自动触发、反馈归属、16 次并发批准仅 1 次落箱、拒绝与终态不可翻转、员工/企业/组织隔离、>=5 门槛、撤销清数据与历史摘要、重新授权不恢复、隐私输入拒绝、插件白名单和专用令牌越权、Host/Origin/令牌/体积/路径边界、MCP 握手/通知/错误/真实 stdio、A2A 生命周期/归属/类型错误、串口 CRC/重试/字段/隐私/会话/跨语言交叉验证、持久化和非回环绑定显式门槛。

## 接口与文档入口

- [运行说明](README.md)
- [架构、授权与撤销](../docs/software/README.md)
- [HTTP 示例](../docs/software/http-examples.md)
- [MCP / A2A 版本、能力和未覆盖项](../docs/software/protocols.md)
- [部署与 Docker 边界](../docs/software/deployment.md)
- [固件、配置与复现](../firmware/README.md)
- [LB1精确规范](../docs/software/serial-protocol.md) 与 [104行共用golden](../docs/software/serial-golden-vectors.tsv)

HTTP：`/api/me`、`/api/state`、`/api/events`、`/api/alerts/feedback`、`/api/actions`、`/api/actions/decide`、`/api/consent`、`/api/share`、`/api/enterprise/summary`、`/api/plugins`、`/api/plugins/token`、`/api/plugins/{id}/tasks`、`/api/hardware`、`/api/scenarios`、`/.well-known/agent-card.json`、`/a2a`、`/health`。

## 未验证与交付边界

本地合成演示，不是公网多租户生产系统。未做 TLS/SSO、限流配额、加密备份、法证级删除、差分隐私、官方协议 SDK 互通或认证。>=5 并不防止所有持续观察推断；撤销不能取回用户已看见的数据。任务列表最近 100 条，提醒/动作 UI 最近 8 条。本轮只修改离线规则与板级/协议边界，不实现或调用模型。并行主控正在加入的可选模型适配由其独立验收；不覆盖其文件、不读取配置或调用付费接口。

safe目标全部交互引脚-1，EVT-A目标按pin-map设GPIO4/5/6 LED、7 touch、8/9 I2C、10 privacy和屏地址候选0x3C。两个目标均显式N8R8内存配置、UART0 USB-UART 115200，CDC关闭。触摸阈值0未标定，禁用采集；无隐私开关时默认禁用交互。可选 SSD1306 只渲染状态图标，不具备中文字体。USB HID底座独立。共阳LED反相与隐私高阻软件时序通过mock；实际LED电流、断电反灌、开关两极触点错时、PSRAM、触摸复用/ESD、屏地址、UART桥枚举都仍须实物验收。保留NOT-FOR-FAB，不把编译与mock当作板测。

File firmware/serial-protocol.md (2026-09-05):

# LB1 串口协议

唯一现行规范位于 [docs/software/serial-protocol.md](../docs/software/serial-protocol.md)，共用 [golden vectors](../docs/software/serial-golden-vectors.tsv)。旧 LBP NDJSON 草案不再支持；没有 ttl_ms 或 TOUCH/PRIVACY 推送类型。

```sh
./firmware/test.sh
./software/test-integration.sh
```

LB1 ASCII + CRC16，115200 8N1，最大 256 bytes，16 项 FIFO 重试缓存，GET/PING 心跳 5 秒失效安全离线。精确字段、UTF-8 hex 验证、错误优先级、物理隐私时序均见唯一规范。

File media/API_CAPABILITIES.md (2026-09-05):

# MiniMax 视频接口核验 · 2026-09-06

已通过 HTTPS 实际抓取官方文档；来源、时间和本地快照 SHA-256 见 `sources.json`。SHA-256 仅用于快照一致性，不冒称官方签名。未调用付费 API、未读取或寻找任何凭据。

## 可直接满足用户规格

- 模型精确值：`MiniMax-H3`，不是 H3-Max，也不是旧 Hailuo 模型。
- 原生输出支持 `2K`；时长支持 4–15 的整数秒，**原生15秒可用**。
- 创建：`POST https://api.minimax.cn/v2/video_generation`。
- 查询：`GET https://api.minimax.cn/v2/query/video_generation/{task_id}`。
- 成功：`task.status=succeeded`，`task.content.url` 是限时下载地址；最近7天内可查询，过期下载地址可重新查询。
- 纯文本使用 `content:[{"type":"text","text":"…"}]`，`ratio:"16:9"` 必填且不能adaptive。提示词≤7000字符。
- 首尾帧可用 `image_url` + `role:first_frame/last_frame`；I2V省略ratio，以参考图片比例为准。

## 预算

官方 `pricing-paygo.md`「视频」：H3 2K **0.80元/秒**，H3 768P 0.50元/秒。H3-Max 480P 0.33元/秒、768P 0.50元/秒，但**不支持2K**。H3图片≤5张免费，超过部分0.20元/张；音频输入免费，视频参考2K按0.80元/秒另计。Context-IR按token额外计费。

本方案：**8条 × 15秒 × 0.80元 = 96元**，授权总上限100元，剩余4元不足重做一条15秒片。最便宜的原规格候选就是H3 / 2K / 15秒、纯文本或一张首帧图，无视频参考、无Context-IR。先提交透明鼠标2条（24元），合格后继续其余6条（72元）；不自动重试付费创建请求。失败/网络不确定请求保留预算占用，核实账单前不释放。

没有官方证据证明当前价格时必须拒绝提交；不能靠自定单价绕过。`video_client.py`仅支持已核验的H3纯文本或≤5张免费图片请求，并校验本地价格证据SHA-256、预算100元和最多8次提交。账本为本工作批次预算，不代表账户余额、税务发票或并发其他应用支出。账户权限及实际余额仍未验证。

## 主控制器接口

```sh
cd /Users/lwblx/huapohen/agent/execute/enterprise_work/imagine/media
python3 video_client.py plan --requests requests.json
# 主控制器从安全来源设置 MINIMAX_API_KEY，不写命令历史/产物。
python3 video_client.py submit --requests requests.json --id 01_crystal_mouse_focus --budget-cny 100
python3 video_client.py poll --id 01_crystal_mouse_focus
# poll每次只做一次请求，至少间隔10秒；成功后download。
python3 video_client.py download --id 01_crystal_mouse_focus
```

客户端默认账本 `video_ledger.json`，响应中只保留task_id/status/usage/限时下载地址，绝不打印Key、原始错误body或下载URL。提交前在磁盘保留摘要及预算预占。若创建超时，禁止盲目重试；使用 `list` 查询最近任务，人工核对后 `attach --id … --task-id …` 恢复。所有付费创建由主控制器执行。

## 质量与真实性

`storyboards.md`有8条15秒镜头、旁白与prompt。每条由后期烧录常驻「AI概念演示 · 非已生产实机」，末尾说明「功能/外观待工程验证」。不要让模型绘制中文界面或关键标签；后期叠加。健康仅舒适度/休息建议；企业展示合成数据、明确分享与≥5人聚合，禁止秘密监控。分辨率和时长必须用ffprobe验收，不能将插帧/放大当作原生2K。

原生15秒生成是首选。若质量不足，`assemble_concept.py`可把授权生成的6/10秒片源与CAD图/真实软件录屏组合成15秒，必须记录片源实际长度；这种剪辑不等同于原生15秒AI生成，不能虚报。由于本轮96元预算无足够余量，任何重新生成应先核实账单及剩余额度。

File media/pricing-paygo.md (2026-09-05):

> ## Documentation Index
> Fetch the complete documentation index at: https://platform.minimaxi.com/docs/llms.txt
> Use this file to discover all available pages before exploring further.

# 按量计费

> MiniMax按量计费定价

按量计费使用开放平台普通 API Key，并按实际用量消耗账户余额。积分是通过订阅 Key 使用的独立预付余额，资源覆盖范围与 Token Plan 相同。积分定价和使用规则请参考 [Token Plan 定价](/docs/guides/pricing-token-plan)。

## 语言模型

[立即充值](https://platform.minimaxi.com/user-center/payment/balance)

<Tabs>
  <Tab title="标准">
    | **模型**                                                                                                                                                                                                   | **输入价格**<br /> 元/百万 tokens | **输出价格**<br /> 元/百万 tokens | **缓存读取**<br /> 元/百万 tokens |
    | :------------------------------------------------------------------------------------------------------------------------------------------------------------------------------------------------------- | :------------------------: | :------------------------: | :------------------------: |
    | **MiniMax-M3**<br />≤ 512k 输入 tokens <span className="inline-flex items-center rounded-full bg-red-50 px-2 py-0.5 text-xs font-semibold text-red-700 dark:bg-red-900/30 dark:text-red-300">永久五折</span>   |        ~~4.20~~ 2.10       |       ~~16.80~~ 8.40       |        ~~0.84~~ 0.42       |
    | **MiniMax-M3**<br />> 512k 输入 tokens\* <span className="inline-flex items-center rounded-full bg-red-50 px-2 py-0.5 text-xs font-semibold text-red-700 dark:bg-red-900/30 dark:text-red-300">永久五折</span> |        ~~8.40~~ 4.20       |       ~~33.60~~ 16.80      |        ~~1.68~~ 0.84       |
  </Tab>

  <Tab title="优先*">
    | **模型**                                                                                                                                                                                                 | **输入价格**<br /> 元/百万 tokens | **输出价格**<br /> 元/百万 tokens | **缓存读取**<br /> 元/百万 tokens |
    | :----------------------------------------------------------------------------------------------------------------------------------------------------------------------------------------------------- | :------------------------: | :------------------------: | :------------------------: |
    | **MiniMax-M3**<br />≤ 512k 输入 tokens <span className="inline-flex items-center rounded-full bg-red-50 px-2 py-0.5 text-xs font-semibold text-red-700 dark:bg-red-900/30 dark:text-red-300">永久五折</span> |        ~~6.30~~ 3.15       |       ~~25.20~~ 12.60      |        ~~1.26~~ 0.63       |
    | **MiniMax-M3**<br />> 512k 输入 tokens <span className="inline-flex items-center rounded-full bg-red-50 px-2 py-0.5 text-xs font-semibold text-red-700 dark:bg-red-900/30 dark:text-red-300">永久五折</span> |       ~~12.60~~ 6.30       |       ~~50.40~~ 25.20      |        ~~2.52~~ 1.26       |

    \* 优先服务可让请求获得优先准入，从而更快响应并降低失败率。调用时将 `service_tier` 设为 `priority` 即可启用。该层级按标准价格的 1.5 倍计费。
  </Tab>
</Tabs>

| **模型** | **输入价格**<br /> 元/百万 tokens | **输出价格**<br /> 元/百万 tokens | **缓存读取**<br /> 元/百万 tokens | **缓存写入**<br /> 元/百万 tokens |
| :--- | :---: | :---: | :---: | :---: |
| **MiniMax-M2.7** | 2.1 | 8.4 | 0.42 | 2.625 |
| **MiniMax-M2.7-highspeed** | 4.2 | 16.8 | 0.42 | 2.625 |

<Accordion title="历史模型">
  | **模型**                     | **输入价格**<br /> 元/百万 tokens | **输出价格**<br /> 元/百万 tokens | **缓存读取**<br /> 元/百万 tokens | **缓存写入**<br /> 元/百万 tokens |
  | :------------------------- | :------------------------: | :------------------------: | :------------------------: | :------------------------: |
  | **MiniMax-M2.5**           |             2.1            |             8.4            |            0.21            |            2.625           |
  | **MiniMax-M2.5-highspeed** |             4.2            |            16.8            |            0.21            |            2.625           |
  | **MiniMax-M2.1**           |             2.1            |             8.4            |            0.21            |            2.625           |
  | **MiniMax-M2.1-highspeed** |             4.2            |            16.8            |            0.21            |            2.625           |
  | **MiniMax-M2**             |             2.1            |             8.4            |            0.21            |            2.625           |
</Accordion>

<Info>
  请注意：

  1. 计费项是token数；tokens字符比值根据使用场景的不同略有浮动，以实际消耗为准，字符数包括标点等
  2. Token与字符比（估算）：1600 中文字符约消耗 1000 tokens
</Info>

## 语音

[立即充值](https://platform.minimaxi.com/user-center/payment/balance)

MiniMax 语音大模型能够根据上下文，智能预测文本的情绪、语调等信息，并生成超自然、高保真、个性化的语音。在社交、播客、有声书、新闻资讯、教育、数字人等多种场景中展现出强大的实力。

| **计费项** | **模型** | **接口说明** | **单价**<br />元/万字符 |
| :--- | :--- | :--- | :---: |
| 同步语音合成<br />T2A | speech-2.8-hd | 支持音量、语调、语速调整和混音功能，支持比特率、采样率相关参数调整特性，支持音频时长、音频大小等返回参数，适用于需要短文本快速得到结果的场景，比如闲聊、对话等场景 | 3.5 |
| 同步语音合成<br />T2A | speech-2.8-turbo | 支持音量、语调、语速调整和混音功能，支持比特率、采样率相关参数调整特性，支持音频时长、音频大小等返回参数，适用于需要短文本快速得到结果的场景，比如闲聊、对话等场景 | 2 |
| 异步长文本语音合成<br />T2A Async | speech-2.8-hd | 支持基于文本到语音的异步生成，单次文本生成传输最大支持 100 万字符，生成的完整音频结果支持异步的方式进行检索。 | 3.5 |
| 异步长文本语音合成<br />T2A Async | speech-2.8-turbo | 支持基于文本到语音的异步生成，单次文本生成传输最大支持 100 万字符，生成的完整音频结果支持异步的方式进行检索。 | 2 |

| **计费项** | **模型** | **接口说明** | **单价**<br /> 元/音色 |
| :--- | :----- | :--- | :---: |
| **音色设计**<br /> Voice Design  | 所有模型 | 支持基于用户输入的声音描述 prompt，来生成音色（voice\_id）；并支持使用该生成的音色（voice\_id）在同步语音合成、异步长文本语音合成接口中进行语音合成。 | 9.9 <br /> 调用本接口获得新设计的音色时，不会立即收取音色设计费用。音色生成费用将在首次使用此音色进行语音合成时收取。<br />本接口内的试听语音合成会收取 2 元/万字符的费用。 |
| **快速复刻**<br /> Voice Cloning | 所有模型 | 基于大语言模型的音色克隆更加精准快速，无需数小时时长的超高质量原音频、无需传统 TTS 的超长工期，可以在极短时间内完成音色复刻，并通过大语言模型加持，使复刻后的音色与原音色进行高质量还原，从而满足客户需求。 | 9.9 <br /> 调用本接口获得复刻音色时，不会立即收取音色复刻费用。音色的复刻费用将在首次使用此复刻音色进行语音合成时收取。<br />试听字符根据选择的试听模型收费。 |

<Accordion title="历史模型">
  | **计费项**             | **模型**                             | **单价**<br />元/万字符 |
  | :------------------ | :--------------------------------- | :---------------: |
  | 同步语音合成 T2A          | speech-2.6-hd / speech-02-hd       |        3.5        |
  | 同步语音合成 T2A          | speech-2.6-turbo / speech-02-turbo |         2         |
  | 异步长文本语音合成 T2A Async | speech-2.6-hd / speech-02-hd       |        3.5        |
  | 异步长文本语音合成 T2A Async | speech-2.6-turbo / speech-02-turbo |         2         |
</Accordion>

<Info>
  注：计费项是字符数，以10000个字符（输入）为单位，1个汉字算2个字符，英文字母、希腊字母、标点符号、特殊符号、空格、回车等算1个字符。
</Info>

## 视频

[立即充值](https://platform.minimaxi.com/user-center/payment/balance)

**视频生成-输出价格**

| **模型/接口** | **分辨率** | **计费规则** | **刊例价**  |
| :--- | :--- | :--- | :--- |
| <div style={{minWidth:'240px'}}>MiniMax-H3</div> | 768P | 按秒计费 | 0.50 元/秒 |
| <div style={{minWidth:'240px'}}>MiniMax-H3</div> | 2K | 按秒计费 | 0.80 元/秒 |
| <div style={{minWidth:'240px'}}>MiniMax-H3-Max</div> | 480P | 按秒计费 | 0.33 元/秒 |
| <div style={{minWidth:'240px'}}>MiniMax-H3-Max</div> | 768P | 按秒计费 | 0.50 元/秒 |

<Note>
  MiniMax-H3-Max 目前仅支持 T2V、I2V，仅输出视频计费，输入素材（图片）暂不计费。
</Note>

**视频生成-输入素材价格**

| **模型/接口** | **素材类型** | **计费规则** |
| :--- | :--- | :--- |
| <div style={{minWidth:'240px'}}>MiniMax-H3</div> | 音频 | 免费 |
| <div style={{minWidth:'240px'}}>MiniMax-H3</div> | 图片 | **5 张**以内免费，超出部分 **0.20 元/张** |
| <div style={{minWidth:'240px'}}>MiniMax-H3</div> | 视频 | 按输入视频时长及生成视频分辨率计费：**2K 0.80 元/秒**，**768P 0.50 元/秒** |

**视频再生成-输出价格**

将已生成的 768P 视频进一步生成为 2K 视频，按视频再生成输出秒数计费。

| **模型/接口** | **分辨率** | **计费规则** | **刊例价**  |
| :--- | :--- | :--- | :--- |
| <div style={{minWidth:'240px'}}>MiniMax-H3-Regeneration</div> | 768P → 2K | 按视频再生成输出秒数计费 | 0.30 元/秒 |

**视频再生成-输入素材价格**

原 768P 生成任务中使用的输入素材需要重新计费。

| **模型/接口** | **素材类型** | **计费规则** |
| :--- | :--- | :--- |
| <div style={{minWidth:'240px'}}>MiniMax-H3-Regeneration</div> | 音频 | 免费 |
| <div style={{minWidth:'240px'}}>MiniMax-H3-Regeneration</div> | 图片 | **5 张**以内免费，超出部分 **0.15 元/张** |
| <div style={{minWidth:'240px'}}>MiniMax-H3-Regeneration</div> | 视频 | 按原 768P 生成任务中输入视频的秒数计费：**0.30 元/秒** |

**H3-Context-IR 任务价格**

| **模型/接口** | **输入价格** | **输出价格** |
| :--- | :---: | :---: |
| <div style={{minWidth:'240px'}}>MiniMax-H3-Context-IR</div> | 5.80 元/百万 tokens | 23.00 元/百万 tokens |

<Accordion title="历史模型">
  | **模型**                  | **功能**             | **单价**<br /> 元/视频 |
  | :---------------------- | :----------------- | :---------------- |
  | MiniMax-Hailuo-2.3-Fast | 图生视频，768P 6s       | 1.35              |
  | MiniMax-Hailuo-2.3-Fast | 图生视频，768P 10s      | 2.25              |
  | MiniMax-Hailuo-2.3-Fast | 图生视频，1080P 6s      | 2.31              |
  | MiniMax-Hailuo-2.3      | 文生视频，图生视频，768P 6s  | 2.00              |
  | MiniMax-Hailuo-2.3      | 文生视频，图生视频，768P 10s | 4.00              |
  | MiniMax-Hailuo-2.3      | 文生视频，图生视频，1080P 6s | 3.50              |
  | MiniMax-Hailuo-02       | 文生视频，图生视频，768P 6s  | 2.00              |
  | MiniMax-Hailuo-02       | 文生视频，图生视频，768P 10s | 4.00              |
  | MiniMax-Hailuo-02       | 文生视频，图生视频，1080P 6s | 3.50              |
  | MiniMax-Hailuo-02       | 图生视频，512P 6s       | 0.60              |
  | MiniMax-Hailuo-02       | 图生视频，512P 10s      | 1.00              |
</Accordion>

## 音乐

<Note title="Music API 服务调整通知">
  自 2026 年 8 月 20 日起，付费接口（音乐生成、歌词生成）不再面向新用户提供服务，历史付费用户可继续使用现有 API 服务；免费音乐生成接口（Music-3.0-free、Music-2.6-free、music-cover-free）停止服务。

  如需体验或使用音乐生成能力，可前往 [MiniMax Audio](https://www.minimaxi.com/audio)，或使用已发布在 [Hugging Face](https://huggingface.co/MiniMaxAI/MiniMax-Music3) 和 [魔搭 ModelScope](https://modelscope.cn/models/MiniMax/MiniMax-Music3) 的 MiniMax Music 3 开源模型。
</Note>

| **模型** | **接口说明** | **单价**<br /> 元/首 |
| :--- | :--- | :---: |
| Music-3.0（已下线） | RPM = 120，若需提升可联系销售定制 | 1.0 |
| Music-2.6（已下线） | RPM = 120，若需提升可联系销售定制 | 1.0 |
| 歌词生成（已下线） | 歌词生成/编辑 | 0.05 |

<Accordion title="历史模型">
  | **模型**          | **接口说明**              | **单价**<br /> 元/首 |
  | :-------------- | :-------------------- | :--------------: |
  | Music-2.5+（已下线） | 最新音乐生成模型，纯音乐解锁，突破风格边界 |        1.0       |
  | Music-2.5（已下线）  | 全维度突破，指挥细节，定义真实       |        1.0       |
  | Music-2.0（已下线）  | 多变音色，丰富乐器表现           |       0.25       |
</Accordion>

## 图像

[立即充值](https://platform.minimaxi.com/user-center/payment/balance)

| **模型** | **接口说明** | **单价**<br /> 元/张 |
| :--- | :--- | :---: |
| image-01<br />image-01-live | 支持用户通过文本描述或参考图片生成图片 | 0.025 |

## MCP

[立即充值](https://platform.minimaxi.com/user-center/payment/balance)

| **模型**  | **接口说明** | **输入价格**<br />元/次 |
| :--- | :--- | :---: |
| API-vlm | 通过 **Token Plan MCP** 插件或工具自带的视觉接口调用 | 0.025 |

通过 Token Plan 调用 API-vlm 时，会按其按量计费价格扣减套餐内 Token Plan 额度；套餐内额度耗尽且已购积分可用时，超出部分可由已购积分自动补充支付。

<Callout color="#FFC107">
  🔔 **定价调整预告**：自2026年7月22日起，API-vlm 按量价格调整为 ¥0.025 元/次。Token Plan 套餐内单次 API-vlm 调用扣减的 token 额度将同步减少，同等套餐可支持更多次调用。接口与能力保持不变，无需任何代码调整。
</Callout>

## 服务端工具 <span className="inline-flex items-center rounded-full bg-blue-50 px-2 py-0.5 text-xs font-semibold text-blue-700 before:content-['Beta'] dark:bg-blue-900/30 dark:text-blue-300" />

[立即充值](https://platform.minimaxi.com/user-center/payment/balance)

| **服务端工具** | **接口说明** | **单价**<br /> 元/次 |
| :--- | :--- | :---: |
| **web\_search** | 联网搜索，模型在服务端自动执行搜索并基于结果作答，详见[服务端工具](/docs/guides/server-tools) | 0.03 |

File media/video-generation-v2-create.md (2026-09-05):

> ## Documentation Index
> Fetch the complete documentation index at: https://platform.minimaxi.com/docs/llms.txt
> Use this file to discover all available pages before exploring further.

# 创建视频生成任务

> 视频生成 V2 接口，通过多模态 content 数组输入（文本 / 图片 / 视频 / 音频），可通过 `model` 字段切换 MiniMax H3 与 MiniMax H3 Max，覆盖文生视频、图生视频（首尾帧）、多模态参考生视频，最高 2K 输出。<br /><br />提示：若需要使用 MiniMax H3 或 MiniMax H3 Max，请点击 [按量购买 API](/docs/guides/pricing-paygo#%E8%A7%86%E9%A2%91)。

## OpenAPI

````yaml api-reference/video/generation/api/v2-video-generation.json POST /v2/video_generation
openapi: 3.1.0
info:
  title: MiniMax API
  description: MiniMax video generation V2 (Hailuo-03) API
  license:
    name: MIT
  version: 2.0.0
servers:
  - url: https://api.minimax.cn
security:
  - bearerAuth: []
paths:
  /v2/video_generation:
    post:
      tags:
        - Video V2
      summary: 创建视频生成任务
      description: >-
        创建视频生成任务。模型依据传入的文本、图片、视频、音频等多模态信息生成视频。本接口为异步接口，创建成功后返回
        `task_id`，需通过[查询任务](/api-reference/video-generation-v2-query)接口轮询任务状态，任务成功后获取生成视频。

        当前支持模型：`MiniMax-H3`。
      operationId: videoGenerationV2Create
      parameters:
        - name: Content-Type
          in: header
          required: true
          description: 请求体的媒介类型，请设置为 `application/json`。
          schema:
            type: string
            enum:
              - application/json
            default: application/json
      requestBody:
        content:
          application/json:
            schema:
              $ref: '#/components/schemas/VideoGenerationV2Req'
            examples:
              文生视频 (t2va):
                value:
                  model: MiniMax-H3
                  content:
                    - type: text
                      text: >-
                        史诗级太空歌剧院线预告：女舰长独自站在巨大观景窗前，最后一支舰队正在集结并跃迁离去，强光爆闪、舰桥震动，她被留在原地。
                  resolution: 2K
                  duration: 5
                  ratio: '16:9'
              图生视频 (i2va):
                value:
                  model: MiniMax-H3
                  content:
                    - type: text
                      text: >-
                        Pull focus to the people in the background and add more
                        steam to the ramen bowl.
                    - type: image_url
                      image_url:
                        url: >-
                          https://cdn.hailuoai.com/prod/hailuo_demo/testsets/H3_AA_I2VA/gallery/sr_v17_variants_seed42_43_20260724/inputs/4a3a90bf9100_KDmcbkhzYo5sjjxr9FqcVmWVnzb.png
                      role: first_frame
                  resolution: 2K
                  duration: 5
                  ratio: adaptive
              多模态参考生视频 (r2va):
                value:
                  model: MiniMax-H3
                  content:
                    - type: text
                      text: >-
                        角色说话：Follow the wind, live free.Leave worries behind,
                        enjoy the moment，音色参考音频1
                    - type: video_url
                      video_url:
                        url: >-
                          https://cdn.hailuoai.com/prod/hailuo_demo/testsets/h3_promo_eval_ref2va/gallery/sr_v2p26_trio_seed42_20260724/inputs/297573323635_00_%E8%A7%86%E9%A2%911_YnyRbxEwio_v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
                      role: reference_video
                    - type: audio_url
                      audio_url:
                        url: >-
                          https://cdn.hailuoai.com/prod/hailuo_demo/testsets/h3_promo_eval_ref2va/gallery/sr_v2p26_trio_seed42_20260724/inputs/f463d523c5ce_01_%E9%9F%B3%E9%A2%911_RSLcbpzJPo_6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
                      role: reference_audio
                  resolution: 2K
                  duration: 5
                  ratio: adaptive
        required: true
      responses:
        '200':
          description: >-
            创建成功后返回 `task_id`。使用该 `task_id`
            调用[查询任务](/api-reference/video-generation-v2-query)接口获取任务状态与结果。

            **查询任务成功响应示例**

            ```json

            {
              "task": {
                "id": "424010985738629",
                "model": "MiniMax-H3",
                "status": "succeeded",
                "created_at": 1785125529,
                "updated_at": 1785125946,
                "content": {
                  "url": "https://your-cdn.example.com/h3-generated-2k-output.mp4"
                },
                "resolution": "2K",
                "duration": 5,
                "usage": {
                  "total_seconds": 5,
                  "input_seconds": 0,
                  "output_seconds": 5,
                  "input_image_count": 0
                },
                "ratio": "16:9",
                "task_type": "generation",
                "modality": "video"
              }
            }

            ```
          content:
            application/json:
              schema:
                $ref: '#/components/schemas/VideoGenerationV2Resp'
        '400':
          $ref: '#/components/responses/Err400'
        '401':
          $ref: '#/components/responses/Err401'
        '402':
          $ref: '#/components/responses/Err402'
        '422':
          $ref: '#/components/responses/Err422'
        '429':
          $ref: '#/components/responses/Err429'
        '500':
          $ref: '#/components/responses/Err500'
components:
  schemas:
    VideoGenerationV2Req:
      type: object
      required:
        - model
        - content
        - resolution
        - duration
      properties:
        model:
          type: string
          description: >-
            模型名称。当前可用值：`MiniMax-H3`、`MiniMax-H3-Max`。

            - **`MiniMax-H3`**：支持文生视频、图生视频（首帧 / 尾帧）与多模态参考生视频；分辨率 `768P` /
            `2K`，时长 4~15 秒。

            - **`MiniMax-H3-Max`**：**极速生成**版本。仅支持**文生视频**与**图生视频（首帧 /
            尾帧）**，不支持多模态参考（参考图 / 参考视频 / 参考音频）；分辨率 `480P` / `768P`，**不支持
            `2K`**；时长 5~15 秒。
          enum:
            - MiniMax-H3
            - MiniMax-H3-Max
        content:
          type: array
          description: >-
            多模态输入内容数组，描述用于生成视频的信息。每个元素通过 `type` 区分类型（`text` / `image_url` /
            `video_url` / `audio_url`），并可通过 `role` 标注用途。

            **每次请求必须包含一个非空 `text` 项（prompt 必填）**；缺失会返回参数错误。

            支持的输入组合（对应不同生成场景）：

            - **文生视频**：仅一个 `text` 元素。

            - **图生视频-首帧**：`text` + 1 张 `image_url`（`role=first_frame` 或不填）。

            - **图生视频-尾帧**：`text` + 1 张 `image_url`（`role=last_frame`）。

            - **图生视频-首尾帧**：`text` + 2 张 `image_url`（`role` 分别为
            `first_frame`、`last_frame`）。

            - **多模态参考生视频**：`text` + 参考图片（`role=reference_image`）+
            参考视频（`role=reference_video`）+ 参考音频（`role=reference_audio`）的组合。

            > **图生视频与多模态参考生视频互斥**：content 中出现 `reference_image` /
            `reference_video` / `reference_audio` 任一 role，就不能再出现 `first_frame` /
            `last_frame`（反之亦然），二者不可混用。

            ---

            **输入媒体限制**（请求体总大小 ≤ 64 MB，大文件请用公网 URL，勿用 Base64）

            图片 `image_url`：

            | 项 | 限制 |

            | :--- | :--- |

            | 格式 | JPG、JPEG、PNG、WEBP、HEIC、HEIF |

            | 单文件大小 | ≤ 30 MB |

            | 宽高范围 | [256, 5760] px |

            | 长宽比（宽/高） | [0.4, 2.5] |

            | 数量 | 首帧 ≤ 1、尾帧 ≤ 1、参考图 ≤ 9 |

            视频 `video_url`（仅多模态参考场景）：

            | 项 | 限制 |

            | :--- | :--- |

            | 容器 / 格式 | MP4（`.mp4`）、MOV（`.mov`） |

            | 编码 | 视频 H.264/AVC、H.265/HEVC；音频 AAC、MP3 |

            | 单文件大小 | ≤ 50 MB |

            | 个数 | ≤ 3 |

            | 单段时长 | [2, 15] s；总时长 ≤ 15 s |

            | 宽高范围 | [256, 5760] px |

            | 长宽比（宽/高） | [0.4, 2.5] |

            | 帧率 | [23.976, 60] |

            音频 `audio_url`（仅多模态参考场景）：

            | 项 | 限制 |

            | :--- | :--- |

            | 格式 | WAV、MP3 |

            | 单文件大小 | ≤ 15 MB |

            | 个数 | ≤ 3 |

            | 单段时长 | [2, 15] s；总时长 ≤ 15 s |
          items:
            $ref: '#/components/schemas/ContentItem'
        resolution:
          type: string
          description: |-
            视频分辨率。不同模型支持的档位不同：

            - **`MiniMax-H3`**：`768P`、`2K`
            - **`MiniMax-H3-Max`**：`480P`、`768P`（默认 `768P`，不支持 `2K`）
          enum:
            - 480P
            - 768P
            - 2K
        duration:
          type: integer
          description: |-
            生成视频时长（秒），必选，整数。不同模型可用值不同：

            - **`MiniMax-H3`**：`4`~`15`
            - **`MiniMax-H3-Max`**：`5`~`15`（不支持 4 秒）
          enum:
            - 4
            - 5
            - 6
            - 7
            - 8
            - 9
            - 10
            - 11
            - 12
            - 13
            - 14
            - 15
        ratio:
          type: string
          description: >-
            生成视频的宽高比，默认 `adaptive`（自动，由输入自适应选择最合适的宽高比，实际比例可在查询接口的 `ratio`
            字段获取）。可用值：`adaptive`、`21:9`、`16:9`、`4:3`、`1:1`、`3:4`、`9:16`。

            **文生视频（t2va，content 仅含 `text`）**：`ratio` 必填，且不能为 `adaptive`；可用值
            `21:9`、`16:9`、`4:3`、`1:1`、`3:4`、`9:16`。

            **图生视频（i2va，content 含 `first_frame` / `last_frame`
            图片）**：宽高比由输入图片决定，`ratio` 恒为 `adaptive`；传入其他合理值不会报错，但会被忽略并按
            `adaptive` 处理。

            **多模态参考生视频（r2va，content 含 `reference_image` / `reference_video` /
            `reference_audio`）**：`ratio` 可选，默认 `adaptive`；也可显式指定上述任一具体比例。
          enum:
            - adaptive
            - '21:9'
            - '16:9'
            - '4:3'
            - '1:1'
            - '3:4'
            - '9:16'
        callback_url:
          type: string
          description: >-
            任务状态变更的回调通知地址。配置后 MiniMax 服务器会先发送含 `challenge` 字段的验证请求（需 3 秒内原样返回
            `challenge` 完成验证），验证成功后每当任务状态变更即向该地址 POST
            推送，推送体结构与[查询任务](/api-reference/video-generation-v2-query)接口的响应一致。
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

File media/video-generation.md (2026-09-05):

> ## Documentation Index
> Fetch the complete documentation index at: https://platform.minimaxi.com/docs/llms.txt
> Use this file to discover all available pages before exploring further.

# 视频生成

> 本文档介绍 MiniMax 视频生成服务（MiniMax H3、MiniMax H3 Max）的使用方法，助力高效创作视频内容。

MiniMax 视频生成目前提供 **MiniMax H3** 与 **MiniMax H3 Max** 两款模型：

* **MiniMax H3**：开放通用的多模态视频模型，可以统一理解文本、图片、视频和音频输入，完成视频生成、参考创作与视频编辑。
* **MiniMax H3 Max**：MiniMax 与 [fal.ai](https://fal.ai/) 联合出品，基于 MiniMax H3 后训练的视频生成模型，专为高速视频生成而优化。输出 480P、768P 主流分辨率，生成速度比 MiniMax H3 更快。当前支持 T2V（文生视频）、I2V（图生视频），全能参考生成能力敬请期待。

提示：若需要使用 MiniMax H3 或 MiniMax H3 Max，请点击 [按量购买 API](/docs/guides/pricing-paygo#视频)。

## 支持的生成方式

### MiniMax H3

| 生成方式 | 输入内容 | 适用场景 |
| --- | --- | --- |
| 文生视频 | Prompt | 根据文字描述从零生成视频 |
| 图生视频 | Prompt + 首帧图片和/或尾帧图片 | 控制视频的开始或结束画面，让指定画面自然动起来 |
| 全能参考生成 | Prompt + 参考图片、视频或音频  | 参考角色、动作、镜头、风格、声音或剪辑节奏 |

### MiniMax H3 Max

| 生成方式 | 输入内容 | 适用场景 |
| --- | --- | --- |
| 文生视频（T2V） | Prompt | 根据文字描述从零生成视频 |
| 图生视频（I2V） | Prompt + 首帧图片和/或尾帧图片 | 控制视频的开始或结束画面，让指定画面自然动起来 |

## 模型规格与输入条件

### 输出规格

| 项目 | MiniMax H3 | MiniMax H3 Max |
| ----- | --- | --- |
| 模型名称  | `MiniMax-H3` | `MiniMax-H3-Max` |
| 输出分辨率 | 768P / 2K | 480P / 768P |
| 输出时长  | 4～15 秒，仅支持整数值 | 5～15 秒，仅支持整数值 |
| 宽高比 | 支持多种常见比例或自适应，[详见 API 文档](/docs/api-reference/video-generation-v2-create) | 支持多种常见比例或自适应，[详见 API 文档](/docs/api-reference/video-generation-v2-create) |

### 输入条件

| 项目 | 要求 |
| --- | --- |
| **首/尾帧入口**  | 图片：0、1、2 张；宽高范围 \[256, 5760]；宽高比 5:2～2:5 范围内 |
| | 无图片输入时为文生视频模式 |
| **全能参考入口**  | 图片：≤ 9 张；宽高范围 \[256, 5760] |
| | 视频：≤ 3 段；单段时长 \[2, 15] 秒；总时长 ≤ 15 秒；宽高范围 \[256, 5760]；宽高比 5:2～2:5 范围内 |
| | 音频：≤ 3 段；单段时长 \[2, 15] 秒；总时长 ≤ 15 秒 |
| | 混合输入的总上限是 12 个文件 |
| | 无图片、视频、音频输入时为文生视频模式 |
| **输入格式支持**  | 视频：H.264/AVC、H.265/HEVC；视频内音频：AAC、MP3 |
| | 图片：JPG、JPEG、PNG、WEBP、HEIC、HEIF |
| | 音频：WAV、MP3 |
| **传入大小限制**  | 视频单个 50 MB；图片单个 30 MB；音频单个 15 MB（加起来的不限制，限制都在单个素材上） |
| | API 请求体 64 MB（推荐使用 URL 传入素材） |
| **提示词字数上限** | 不超过 7000 字符 |

## 工作流程

视频生成是一个异步过程，包含以下三个步骤：

1. 创建生成任务：提交一个视频生成请求，获得任务 ID (`task_id`)
2. 查询任务状态：使用 `task_id` 轮询任务状态。任务成功后，直接返回成片下载地址 (`content.url`)
3. 获取视频文件：下载 `content.url` 指向的视频并保存到本地

## 功能与代码示例

为了简化代码，我们将轮询和下载的逻辑封装为公共函数，并举例了四种模式下如何创建任务。

```python theme={null}
import os
import time
import requests

api_key = os.environ["MINIMAX_API_KEY"]
headers = {"Authorization": f"Bearer {api_key}"}
BASE_URL = "https://api.minimax.cn"
MODEL = "MiniMax-H3"

# --- 步骤 1: 发起视频生成任务 ---
# MiniMax-H3 使用多模态 content[] 结构：每个元素通过 type（text / image_url / video_url / audio_url）区分，
# 并可用 role 标注用途。以下四个函数分别对应文生视频、图生视频、首尾帧、多模态参考四种模式，
# 都会发起一个异步任务并返回唯一的 task_id。

def invoke_text_to_video() -> str:
    """（模式一）纯文本生成视频（t2va）。t2va 场景 ratio 必填且不能为 adaptive。"""
    url = f"{BASE_URL}/v2/video_generation"
    payload = {
        "model": MODEL,
        "content": [
            # type=text 为必填项，用于描述视频的动态内容。
            {"type": "text", "text": "镜头拍摄一个女性坐在咖啡馆里，女人抬头看着窗外，镜头缓缓移动拍摄到窗外的街道，画面呈现暖色调，色彩浓郁，氛围轻松惬意。"},
        ],
        "duration": 5,
        "resolution": "2K",
        "ratio": "16:9",
    }
    response = requests.post(url, headers=headers, json=payload)
    response.raise_for_status()
    return response.json()["task_id"]

def invoke_image_to_video() -> str:
    """（模式二）首帧图 + 文本生成视频（i2va）。"""
    url = f"{BASE_URL}/v2/video_generation"
    payload = {
        "model": MODEL,
        "content": [
            {"type": "text", "text": "Contemporary dance, the people in the picture are performing contemporary dance."},
            # role=first_frame 指定视频起始帧；图生视频场景下宽高比由输入图片决定，ratio 恒为 adaptive。
            {"type": "image_url", "image_url": {"url": "https://filecdn.minimax.chat/public/85c96368-6ead-4eae-af9c-116be878eac3.png"}, "role": "first_frame"},
        ],
        "duration": 5,
        "resolution": "2K",
    }
    response = requests.post(url, headers=headers, json=payload)
    response.raise_for_status()
    return response.json()["task_id"]
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

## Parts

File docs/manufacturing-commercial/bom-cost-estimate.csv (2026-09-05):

item | description | quantity_per_unit | target_unit_cost_cny_at_1000 | estimate_status | rfq_validation
M01 | 标准有线USB鼠标OEM底座 | 1 | 19 | 未报价估算 | 主控传感器微动与合法USB身份
M02 | 透明壳与底结构件 | 1 | 11 | 未报价估算 | 公模可用性材料磨损不含新开模
M03 | ESP32-S3模块 | 1 | 16 | 未报价估算 | 内存型号与供应渠道
M04 | 小屏及排线 | 1 | 15 | 未报价估算 | 尺寸接口坏点与长期供货
M05 | 离散共阳RGB灯导光触摸件 | 1 | 5 | 未报价估算 | GPIO4/5/6 PWM并按pin-map冻结
M06 | PCB电源连接器线材或hub分摊 | 1 | 14 | 未报价估算 | 优先双USB单线方案另验证供电EMC
M07 | 装配和100%功能测试 | 1 | 12 | 未报价估算 | 记录工时产测治具另列NRE
M08 | 包装标签说明书 | 1 | 6 | 未报价估算 | 运输保护序列号合规信息
M09 | 制造损耗与返工预留 | 1 | 10 | 未报价估算 | 记录首次良率避免重复加损耗

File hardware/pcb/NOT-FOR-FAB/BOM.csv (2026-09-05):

Reference | Value | Footprint | Qty | Assembly | Qualification
J1 | DevKitC1_LEFT_1x22 | LINGBAN:J1 | 1 | fit | unqualified engineering estimate; verify exact supplier drawing
J3 | DevKitC1_RIGHT_1x22 | LINGBAN:J3 | 1 | fit | unqualified engineering estimate; verify exact supplier drawing
R1 | 470R | LINGBAN:R1 | 1 | fit | unqualified engineering estimate; verify exact supplier drawing
R2 | 470R | LINGBAN:R2 | 1 | fit | unqualified engineering estimate; verify exact supplier drawing
R3 | 470R | LINGBAN:R3 | 1 | fit | unqualified engineering estimate; verify exact supplier drawing
R4 | 1k | LINGBAN:R4 | 1 | fit | unqualified engineering estimate; verify exact supplier drawing
R5 | 4.7k | LINGBAN:R5 | 1 | fit | unqualified engineering estimate; verify exact supplier drawing
R6 | 4.7k | LINGBAN:R6 | 1 | fit | unqualified engineering estimate; verify exact supplier drawing
R7 | 10k | LINGBAN:R7 | 1 | fit | unqualified engineering estimate; verify exact supplier drawing
C1 | 100nF_16V_X7R | LINGBAN:C1 | 1 | fit | unqualified engineering estimate; verify exact supplier drawing
C2 | 10uF_10V_X5R | LINGBAN:C2 | 1 | fit | unqualified engineering estimate; verify exact supplier drawing
C3 | 100nF_16V_X7R | LINGBAN:C3 | 1 | fit | unqualified engineering estimate; verify exact supplier drawing
D1 | ESD_DNI_REVIEW | LINGBAN:D1 | 1 | DNI | unqualified engineering estimate; verify exact supplier drawing
J4 | OLED_GND_VCC_SCL_SDA | LINGBAN:J4 | 1 | fit | unqualified engineering estimate; verify exact supplier drawing
J5 | REMOTE_RGB_COMMON_ANODE | LINGBAN:J5 | 1 | fit | unqualified engineering estimate; verify exact supplier drawing
J6 | TOUCH_ELECTRODE_GND | LINGBAN:J6 | 1 | fit | unqualified engineering estimate; verify exact supplier drawing
J7 | DPDT_HARNESS_6 | LINGBAN:J7 | 1 | fit | unqualified engineering estimate; verify exact supplier drawing

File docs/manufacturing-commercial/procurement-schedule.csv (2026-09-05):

phase | planned_window | item | quantity_cap | gate | owner | cash_policy | lead_time_status | fallback
原型 | D1-D2 | 现成OEM鼠标与开发板屏触摸件 | 5套加必要备件 | 规格v0.1与实物库存盘点 | 硬件负责人 | 阶段预算上限1.5万元不代表已批准付款 | 待供应商确认 | 保留双USB和外置伴随模块
原型 | D3-D4 | 打印展示壳固定架 | 5套 | 台架链路通过 | 结构负责人 | 按确认文件小单采购 | 待服务商确认 | 采用现有透明壳不抢开模
EVT | D8-D10 | 工程验证用物料 | 10套 | 原型G0通过 | 采购与工程 | 计入12万元总NRE预算不重复列支 | 待报价确认 | 延期EVT不放大采购量
EVT | D8-D14 | 实验室适用性与预检 | 1项 | 最终供电结构和目标市场清楚 | 质量负责人 | 书面范围与报价后付款 | 可能超过30天 | 延期交付不跳过测试
试产 | D15-D21 | 试产物料与装配 | 50至100套 | EVT和采购G1通过 | 采购与财务 | 拟谈30%订金70%验收后出货但模型保守按全额预付 | 依最长物料重排 | 缩批或延期不无授权替料
试产 | D22-D26 | 终检包装售后备件 | 与合格批次数匹配 | G2前缺陷闭环与追溯齐全 | 质量与交付 | 验收后支付约定余额并保留质保准备 | 按实际一次良率更新 | 隔离不良全批问题先围堵
规模 | M3以后 | 分批核心SKU采购 | 不得提前承诺1000套 | 真实留存退款贡献与90天现金覆盖 | 创始人与采购财务 | 分批采购并与实际回款匹配 | 至少双源评估关键料 | 现金不足停止非必要采购

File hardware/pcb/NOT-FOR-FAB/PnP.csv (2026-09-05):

Ref | Value | X_mm | Y_mm | Rotation_deg | Side | Fit
R1 | 470R | 14 | 18 | 0 | bottom | yes
R2 | 470R | 14 | 23 | 0 | bottom | yes
R3 | 470R | 14 | 28 | 0 | bottom | yes
R4 | 1k | 14 | 33 | 0 | bottom | yes
R5 | 4.7k | 18 | 39 | 0 | bottom | yes
R6 | 4.7k | 18 | 44 | 0 | bottom | yes
R7 | 10k | 14 | 49 | 0 | bottom | yes
C1 | 100nF_16V_X7R | 23 | 18 | 0 | bottom | yes
C2 | 10uF_10V_X5R | 23 | 24 | 0 | bottom | yes
C3 | 100nF_16V_X7R | 23 | 30 | 0 | bottom | yes
D1 | ESD_DNI_REVIEW | 23 | 50 | 0 | bottom | DNI

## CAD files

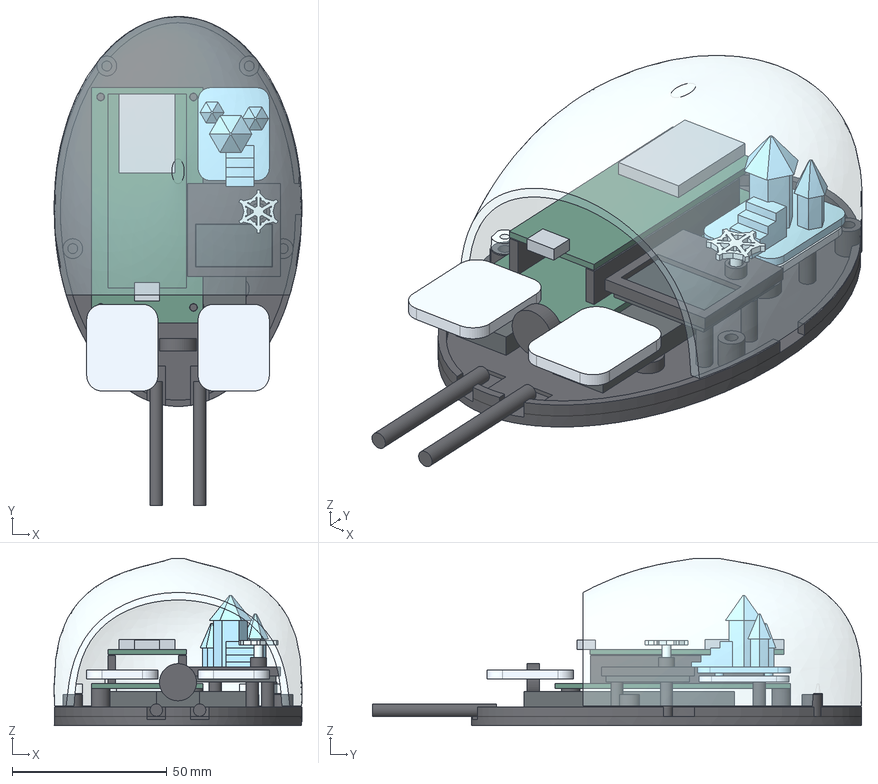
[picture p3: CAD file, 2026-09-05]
hardware/cad/exports/lingban_assembly.step
80.0 x 158.0 x 54.0 mm
01_base
02_clear_canopy
03_button_left
03_button_right
04_oem_wheel_placeholder
05_carrier_placeholder
06_devkit_placeholder
07_socket_-21.43
07_socket_1.43
08_esp_module_placeholder
09_usb_uart_placeholder
10_oem_placeholder
11_cloud_stair_castle
12_snowflake
13_screen_frame
14_display_placeholder
15_display_glass
16_castle_socket_sled
17_usb_cable_-7
17_usb_cable_7

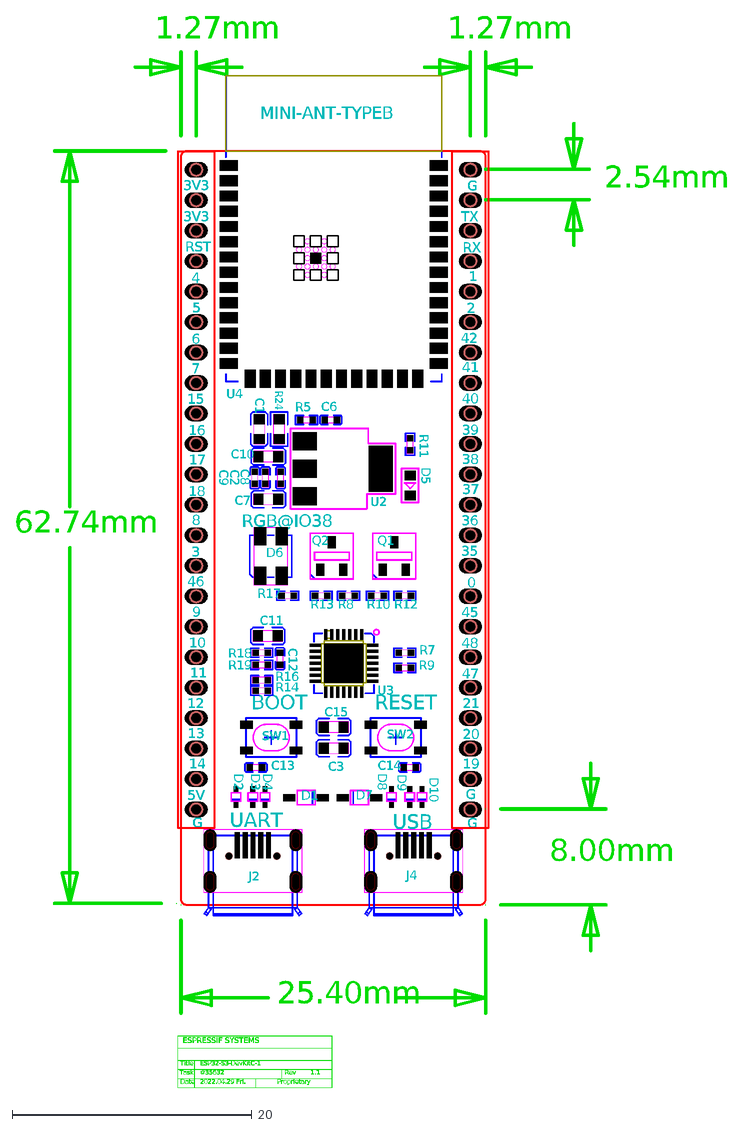
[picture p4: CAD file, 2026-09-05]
hardware/specs/references/devkit-dimensions.dxf
BOOT
RGB@IO38
Date
Task
Title
ESPRESSIF SYSTEMS
Proprietary
2022.04.29 Fri.
#35632
ESP32-S3-DevKitC-1
1.1
Rev
UART
USB
RESET
3V3
RST
4
5
6
7
15
16
17
18
8
3
46
9
10
11
12
13
14
5V
G
TX
RX
19
20
21
47
48
45
35
36
0
40
39
38
37
1
2
42
41
62.74mm
1.27mm
2.54mm
25.40mm
8.00mm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

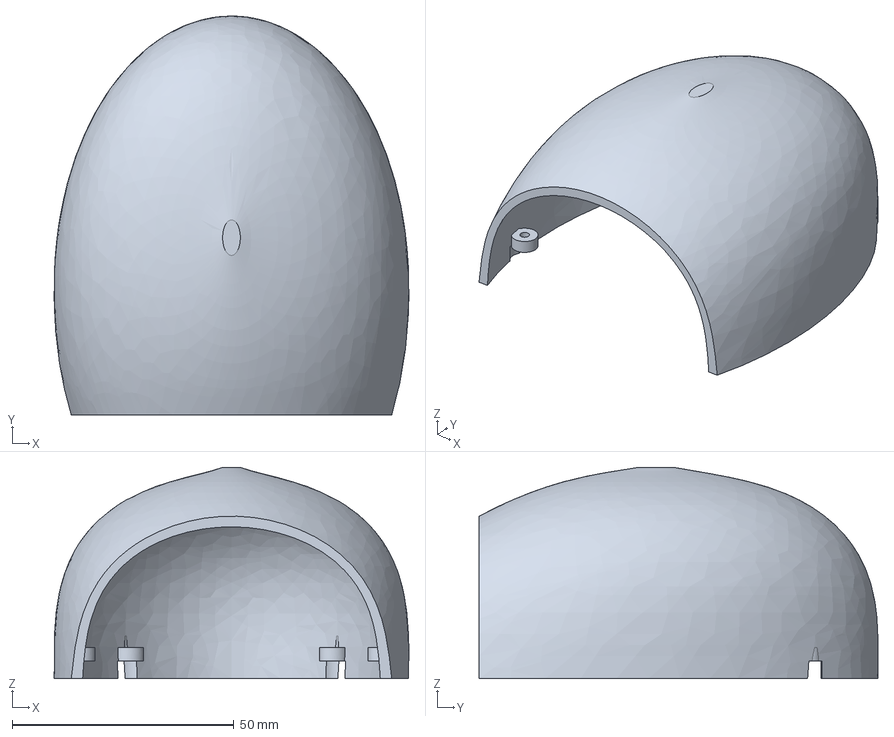
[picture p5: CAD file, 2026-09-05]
hardware/cad/exports/02_clear_canopy.step
80.0 x 90.0 x 47.6 mm

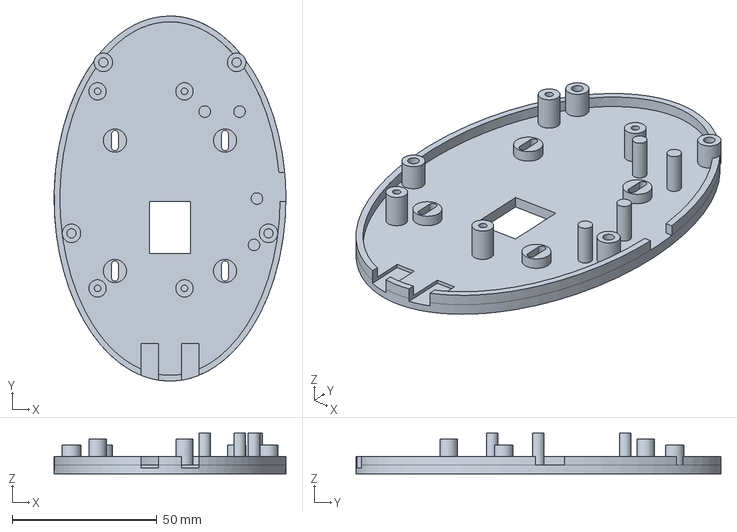
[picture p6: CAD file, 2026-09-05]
hardware/cad/exports/01_base.step
80.0 x 126.0 x 14.0 mm

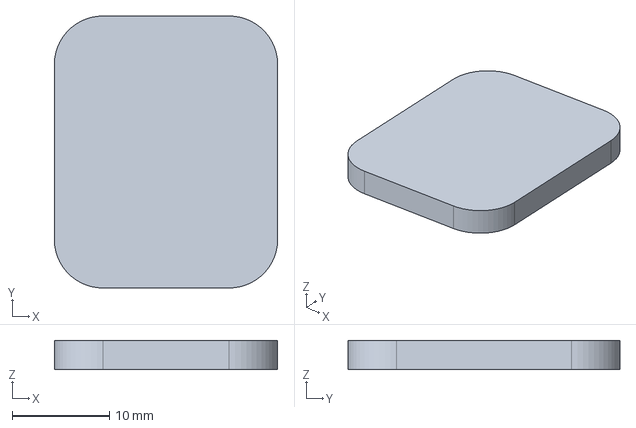
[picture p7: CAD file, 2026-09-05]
hardware/cad/exports/03_button_right.step
23.0 x 28.0 x 3.00 mm

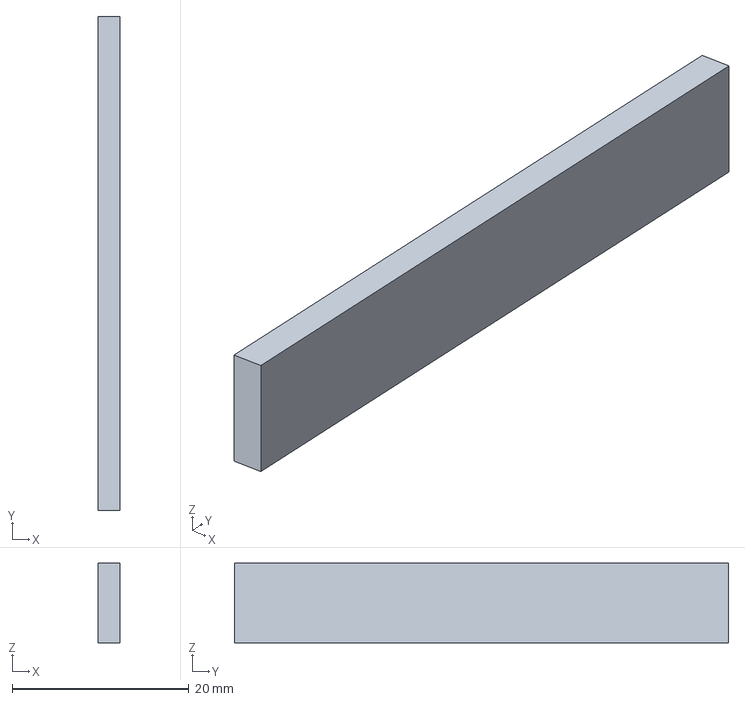
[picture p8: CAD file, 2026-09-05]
hardware/cad/exports/07_socket_1.43.step
2.50 x 55.9 x 9.00 mm

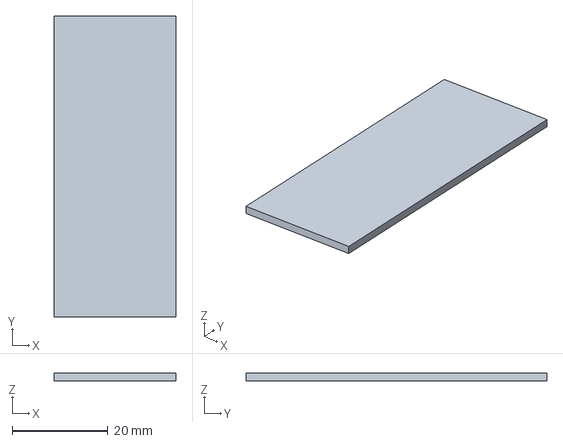
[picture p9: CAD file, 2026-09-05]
hardware/cad/exports/06_devkit_placeholder.step
25.4 x 62.7 x 1.60 mm

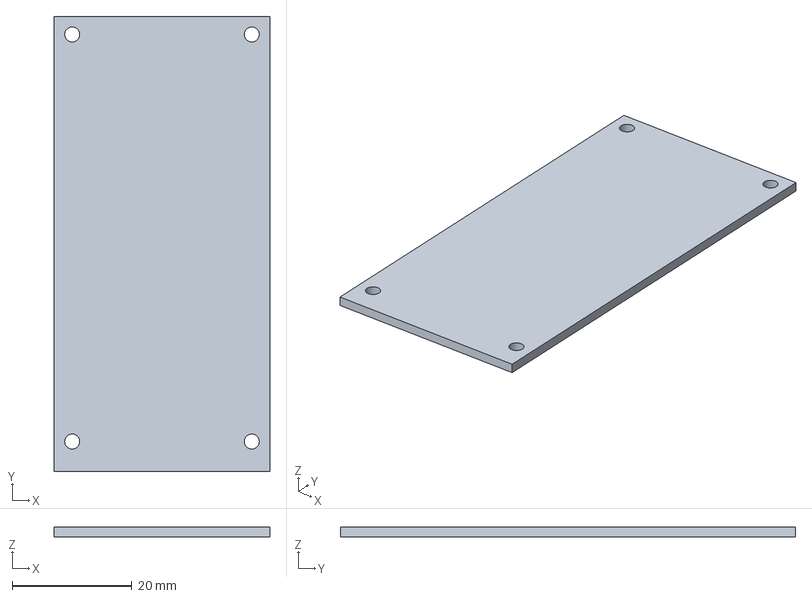
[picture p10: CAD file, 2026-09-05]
hardware/cad/exports/05_carrier_placeholder.step
36.0 x 76.0 x 1.60 mm

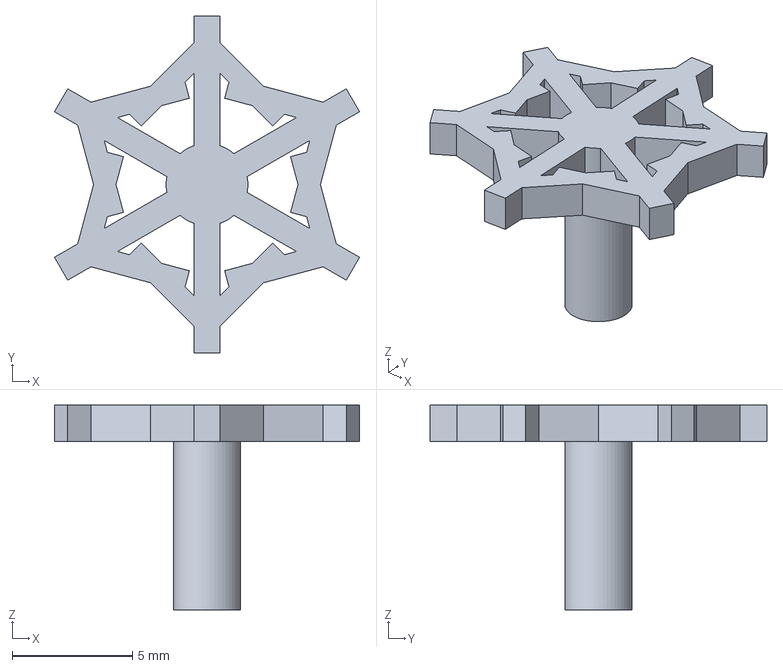
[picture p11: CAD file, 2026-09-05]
hardware/cad/exports/12_snowflake.step
12.7 x 14.0 x 8.50 mm

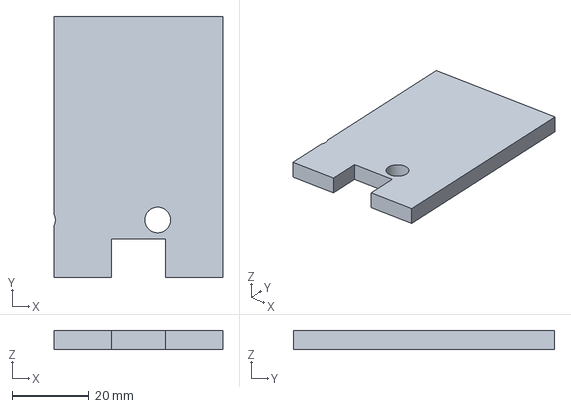
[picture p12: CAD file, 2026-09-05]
hardware/cad/exports/10_oem_placeholder.step
44.0 x 68.0 x 5.00 mm

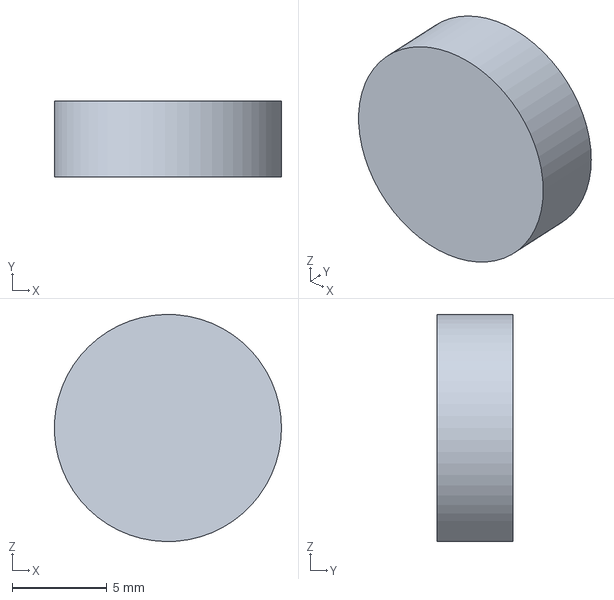
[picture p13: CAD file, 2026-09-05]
hardware/cad/exports/04_oem_wheel_placeholder.step
12.0 x 4.00 x 12.0 mm

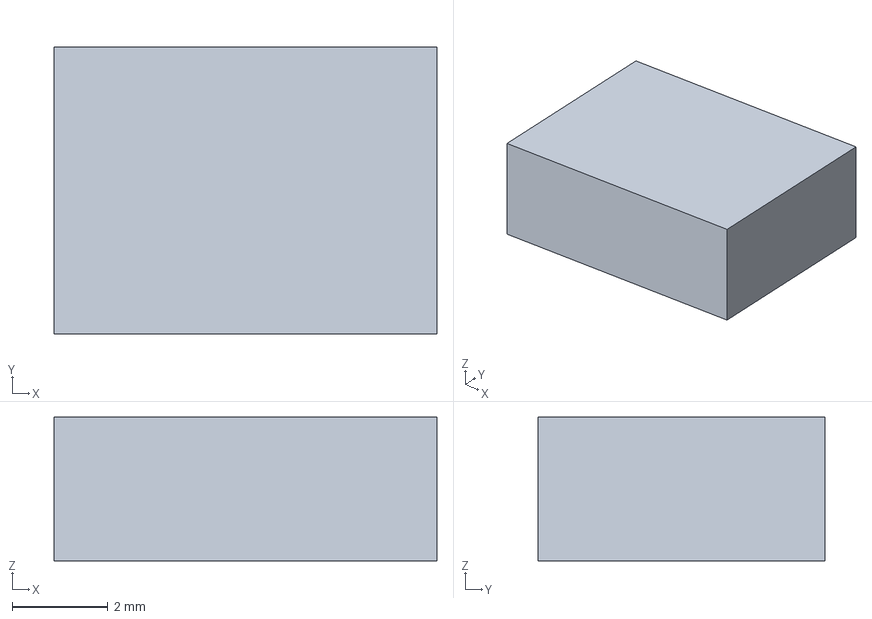
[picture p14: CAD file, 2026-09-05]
hardware/cad/exports/09_usb_uart_placeholder.step
8.00 x 6.00 x 3.00 mm

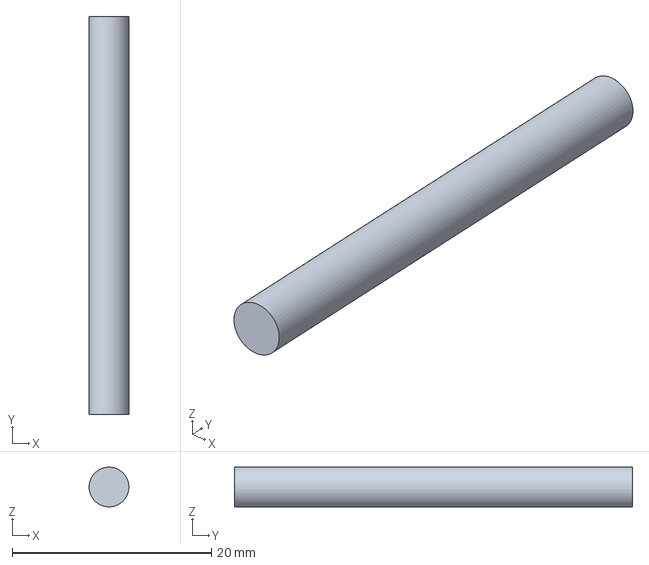
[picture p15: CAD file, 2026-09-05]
hardware/cad/exports/17_usb_cable_-7.step
4.00 x 40.0 x 4.00 mm

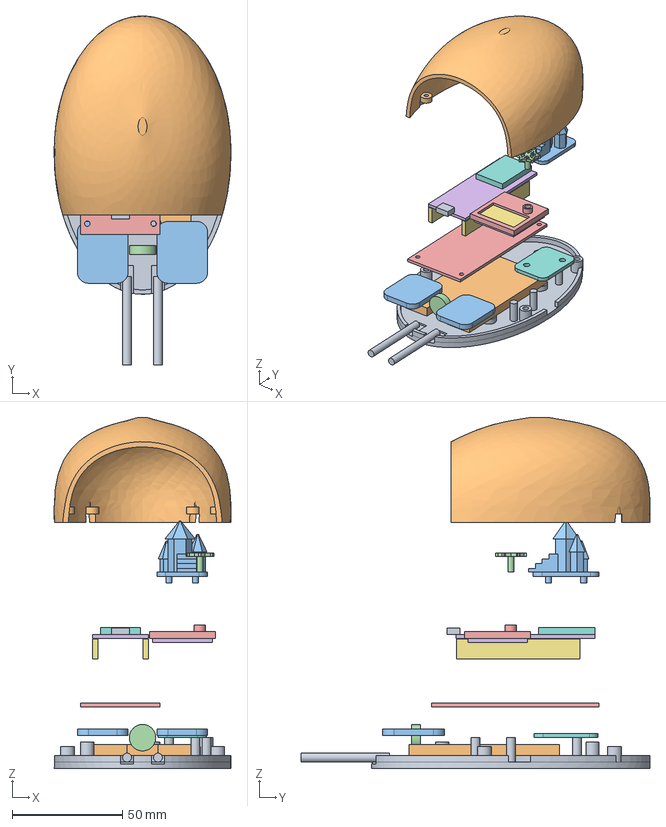
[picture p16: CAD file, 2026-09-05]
hardware/cad/exports/lingban_exploded.step
80.0 x 158.0 x 159.0 mm
01_base
02_clear_canopy
03_button_left
03_button_right
04_oem_wheel_placeholder
05_carrier_placeholder
06_devkit_placeholder
07_socket_-21.43
07_socket_1.43
08_esp_module_placeholder
09_usb_uart_placeholder
10_oem_placeholder
11_cloud_stair_castle
12_snowflake
13_screen_frame
14_display_placeholder
15_display_glass
16_castle_socket_sled
17_usb_cable_-7
17_usb_cable_7

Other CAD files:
hardware/cad/exports/07_socket_-21.43.step
hardware/cad/exports/08_esp_module_placeholder.step
hardware/cad/exports/16_castle_socket_sled.step
hardware/cad/exports/03_button_left.step
hardware/cad/exports/01_base.stl
hardware/cad/exports/02_clear_canopy.stl
hardware/cad/exports/03_button_left.stl
hardware/cad/exports/03_button_right.stl
hardware/cad/exports/04_oem_wheel_placeholder.stl
hardware/cad/exports/05_carrier_placeholder.stl
hardware/cad/exports/06_devkit_placeholder.stl
hardware/cad/exports/07_socket_-21.43.stl
hardware/cad/exports/07_socket_1.43.stl
hardware/cad/exports/08_esp_module_placeholder.stl
hardware/cad/exports/09_usb_uart_placeholder.stl
hardware/cad/exports/10_oem_placeholder.stl
hardware/cad/exports/11_cloud_stair_castle.step
hardware/cad/exports/11_cloud_stair_castle.stl
hardware/cad/exports/12_snowflake.stl
hardware/cad/exports/13_screen_frame.step
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

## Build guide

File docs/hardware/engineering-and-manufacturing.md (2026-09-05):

# 灵伴 Crystal Mouse EVT-A 工程与制造交接

数字工程原型，未进行实物打样、板级功能测试、认证或量产验收。**唯一首发核心为299元目标含税零售价（1000台量产情景，灯＋触摸＋OLED）**；当前先做5台DevKit双USB工程样机，样机成本单列待报价，不是299元商品。499仅未来外观/服务套装。商业裁决来源为docs/product/DECISIONS.md；108元是未来批量商业模型假设，本次保留开发板方案的真实工程估算，不为迎合目标压低成本。

## 架构与器件审查

|对象|已检查/设计值|尚未通过的门槛|
|---|---|---|
|ESP32-S3-DevKitC-1 v1.1 N8R8|官方 J1/J3 表核对 GPIO4/5/6/7/8/9/10；避开绑带0/3/45/46、USB19/20、UART43/44、Octal RAM35–37、板载RGB38/48；官方DXF文字尺寸62.74×25.40、节距2.54、边距1.27与8.00|采购料号、实物版本、模块配置和排针方向必须逐脚核对；不能以兼容板代替官方板而不复审|
|排针插座|2×22，2.54节距，排间22.86；1.0成品孔/1.7焊盘，9mm高绝缘体占位|插座针径、焊尾长度、底面与OEM间隙；1.0孔是工程假设|
|供电|仅开发板3V3给载板；PCB不连接J1-21 5V，无VBUS并接。3V3线宽0.25mm，低电流载板，2层1oz估算|USB5V建议有明确能力的1A电源/Hub端口；USB枚举前/USB-UART供电限制、稳压器热耗和线缆压降未实测|
|电流预算|无线峰值按开发板500mA@5V保守预算；载板3V3外设<=60mA（OLED40+RGB11+其他9）；总USB保守上界约560mA，留裕量到1A|不能在普通500mA USB端口宣称无线满载稳定。先USB-UART、关闭Wi-Fi，测启动/白屏/满亮/无线发射峰值；示波器看3V3跌落与复位|
|RGB|外接共阳四脚RGB LED；3通道各470Ω、GPIO直接低电流灌电流；PWM duty=255−亮度、off=255/HIGH，先预装off再attach；最坏Vf=1.6V时每通道3.62mA，总10.85mA；无高浪涌灯链|未冻结LED供应商料号与脚序；RGB亮度/色差、外壳透光、限流误差须实测。渲染光环为光导视觉概念，并非已经实现的均匀灯带|
|屏幕|SSD1306类128×64、4线I2C、3.3V模块候选，包络27×27×4；载板接口GND/VCC/SCL/SDA；4.7k上拉到SW3V3，100kHz起步；实装profile固定候选0x3C，HAL当前仅状态图标|不同商家尺寸/孔距/脚序、上拉电压、地址0x3C/0x3D、全白峰值不一致；未冻结MPN。不得把5V上拉模组直接接GPIO|
|触摸|GPIO7=TOUCH7；1k串联、触摸电极/GND双针；建议短于50mm的绝缘线；不做生理测量|电极建议铜箔约10×15、隔1–2mm非导电壳；实装LB_TOUCH_THRESHOLD=0、CAPS touch=0，默认禁用采集；湿手、静电、USB接地与阈值需实测。电极形状/铜箔未算进PCB实板|
|隐私开关|J7外接机械DPDT；一极切灯/屏SW3V3，一极允许态把GPIO10接地；外10k上拉断线默认隐私|开关是外接线束元件，**未冻结实物开关封装/行程/面板孔**。建议触点>=100mA@5V，绝缘安装，红色机械OFF标识；先确认公共端，再压接|
|隐私电气边界|实装HAL在隐私时detach PWM/Wire.end并将GPIO4–9改INPUT；清状态，无触摸推送；SW3V3断电后不显示隐私灯/屏|未加总线隔离器，I2C与RGB可能通过GPIO反灌；故障固件下不能证明彻底断电。开关不硬断触摸/USB/主机Agent。必须测断电电压/漏电；如不合格，加专用隔离/负载开关并重布板|
|天线|PCB上部x7..29/y0..8双层禁铜，路由器额外禁止全宽y<8走线；装配天线朝后，侧旁不放金属城堡、线圈、电镀饰件|结合官方天线布局建议核对到实物模块位置；需测USB线缆/手掌覆盖RSSI与发射，不能声称RF验证通过|
|ESD|OEM USB与开发板USB保留原有防护；载板新增触摸线有D1工程占位|**D1为DNI未装、非量产ESD方案**。需选低电容合适钳位TVS并按实际封装改板；0805仅占位。外接屏/LED/开关线束须关在壳内；IEC61000-4-2测试未做|
|装配|贴片器件全部底面、插座顶面；USB线两路独立；元器件绝缘隔离OEM|必须使用底面绝缘片、避免螺钉焊尾接触OEM；PnP顶视/底视与旋转厂商需核对；D1不装|

3.3V为唯一GPIO电平，无5V容限承诺。没有电池、无线充电、音频/摄像头/医疗传感器。触摸只做本地交互，舒适度提醒来自用户授权的软件情境，不诊断、不评分员工、不秘密采集。

唯一线协议为[LB1 ASCII+CRC16](../software/serial-protocol.md)，115200 8N1 USB-UART桥、UART0 RX44/TX43、native CDC关闭；N8R8 profile为8MB/qio/qio_opi/opi。GPIO4–10保持冻结。无每消息ttl_ms或TOUCH/PRIVACY推送；有效空GET/PING维持会话，>=5秒无心跳清输出并高阻；SET不保活。允许LOW稳定40ms且online才恢复外设。逻辑text为至多80 UTF-8 bytes的小写hex，GET可读；渲染屏文案不表示固件能渲染任意文字。

## 机械设计与工厂待确认

坐标：X左右、Y向后、Z向上，mm；底面Z=0。当前展示包络约126长×80宽×54高，明显偏大的展示样机，**不作为已验证的人体工学鼠标**。透明壳覆盖后掌托，前端按钮与OEM滚轮独立。参数化JSON与CadQuery脚本为编辑源；每个零件同时有BREP STEP与STL。

- 底板3mm，主壁名义径向约2–2.35mm，配合目标0.35mm/侧；透明壳为双层椭圆放样差集，非等厚注塑壳。局部法向壁厚与脱模角尚未完整验证，不能直接开钢模。
- M2螺丝过孔2.3、热熔铜螺母试孔3.2、柱外径6.4；柱顶/掌托保留0.35高度间隙。铜螺母必须按实际外径、打印工艺做试片；透明树脂壳用螺钉通孔，避免直接热熔开裂。
- 底壳4个载板立柱与PCB的30×68孔距对应；板坐标到CAD：`Xcad=Xpcb−28`、`Ycad=40−Ypcb`、`Zcad=12`。CAD PCB占位36×76×1.6。开发板插座23mm附近顶面需实物检查焊尾。
- 光学开孔14×18只作预留；**镜片到桌面Z高度、镜头中心XY、遮光腔、底脚厚度一律由OEM实际总成决定**。不购买未知光学芯片重新拼系统。OEM占位已留出载板柱避空，但并不证明任意OEM PCB能装入。
- 两个独立6×6 USB出线槽，4mm线径占位；线缆弯曲半径建议>=5×外径，前端需应力释放夹块/胶套。当前CAD没有完成带拉力认证的止拉结构，也没有双USB融合电路。
- 城堡、雪花、屏框独立导出。晶堡定位销直径2.8、插座孔3.5；可拆装胶-free设计意图，胶-free寿命未测。细雪花枝约0.9–1.1mm，建议韧性树脂打印；儿童误吞与尖角风险需做产品年龄/小零件评审。
- 屏框按候选27×27模块预留，不含已确认螺孔。底壳有屏PCB/城堡底座绝缘支撑柱，但屏框锁定卡扣和底座防脱螺钉尚需ECO；当前定位不代表跌落后保持性。隐私开关侧面孔仅操作位置示意；开关尺寸、卡扣、拨杆防误触需实际开关图纸后重建。
- OEM按钮盖没有完成按压杠杆与滚轮轴承机构。现在的盖板是可编辑外观件；应先扫描/卡尺量OEM原按键，再做悬臂/预行程/限位和寿命设计。不可直接以当前零件承诺可用手感。
- 需测试小/中/大手、左右手可达性、腕伸角、握持防滑、重心、100g/150g/200g不同配重。当前未测重量，禁止用渲染推断舒适度优于普通鼠标。

向工厂/工程师提交前必须补齐：OEM完整2D/STEP及光学高度；开发板实际版本与排针位置；屏幕/LED/开关/连接器MPN及图纸；螺母/螺钉/底脚规格；透明料缩率和耐黄变；天线净空；线束长度/脚1标记/防呆；装配公差链与按钮寿命。当前会话未联系厂家。

## 价格分档与成本假设（人民币，估算而非报价）

SKU映射与[产品裁决](../product/DECISIONS.md)一致，首轮仅验证299核心；其他档位用于后续价格测试，不同时备货。目标价不是报价、利润保证或5台样机价格。

|含税目标价|统一功能/定位|当前工程状态|
|---:|---|---|
|99|普通透明有线鼠标|无完整Agent交互能力；不由当前DevKit样机证明成本|
|199|灯＋触摸，无屏|未来减配选择，未新做第二块板|
|299|**首发核心：灯＋触摸＋OLED**，原创透明壳/晶堡，独立USB鼠标与交互模块|1000台情景目标；5台EVT验证同一功能方向，触摸需标定，屏当前仅状态图标|
|499|未来外观/服务套装|核心硬件功能沿用299，外观/服务内容另定；不再称工程试销首发|
|899|未来企业配置包|部署/权限/管理配置，明确分享与>=5人聚合；不新增生理评分或秘密采集|

### 商业1000台模型与开发板工程估算分开

[制造商业BOM](../manufacturing-commercial/bom-cost-estimate.csv)的9项合计**108元/台**：OEM19、壳11、ESP32-S3模块16、屏15、灯/导光/触摸5、PCB/电源/连接线14、装配测试12、包装6、损耗返工10。它是未来1000台未报价模型，**模块16元不等于官方N8R8开发板的采购价，壳11元不含新开模**。该CSV未冻结税费/发票；以下敏感性仅为可比性假设108为未税直接成本，必须RFQ澄清。108已包括装测12与损耗10，不再重复除以95%或加同一损耗。

**当前DevKit结构保留原工程估算**（1000台采购情景，未税到厂、非供应商报价）：OEM总成25–40；官方/可追溯开发板32–48；载板PCB/贴片/插座/阻容/线束/开关16–25；OLED10–18；低流RGB与电极2–4；塑胶壳/按钮/框20–28；原创装饰件8–14；线缆/螺母/螺钉/底脚8–12；包装与绝缘耗材8–16，合计129–205，规划保守下限135。该方案材料BOM135–205、装测22–32，按95%一次有效良率，`(BOM+装测)/0.95`≈**165–250元/合格台**，不含NRE、渠道、售后、云服务、研发、运费及资金成本。此成本没有被改写为108。

- **5台EVT工程样机，待报价**：透明打印/CNC与手工抛光，材料+电子+外协工艺450–1000/台；装配3–6小时/台、按80元/小时估计240–480；整台690–1480未税。按80%有效良率另乘1.25，约**863–1850元/合格台**。这些是保留的工程估算，不是已购买价格或首发销售价。
- **100台小批敏感性，待报价**：无钢模，复模或打印/后处理，未税BOM220–360、装测35–60、90%良率后约283–467/合格台；已高于299含税售价对应的未税收入。不能把该结构直接当作299试销可盈利。
- **开模NRE**：上下壳+按钮/框6–15万元、装饰模1.5–4万元、测试夹具1–3万元、可靠性/EMC/法规服务3–8万元，合计11.5–30万元未税估计。1000台摊115–300/台，10000台摊11.5–30/台；上述直接成本不含此摊销。

### 299元目标的成本敏感性

仅按硬件13%VAT简化反推，299/1.13=**264.60元未税收入**；服务套装税务另评估。下表差额是扣渠道/售后等之前的余额，**不是毛利承诺或净利润**；各行批量、良率/NRE口径不同，不能混加损耗。

|场景|未税直接成本/合格台|264.60减该成本|判断|
|---|---:|---:|---|
|未来1000台商业模型，已含损耗项|108|156.60|依赖模块/公模壳/采购与良率假设，尚无供应商证据|
|商业模型总额上涨20%，仅压力假设|129.60|135.00|尚未含新开模与渠道等成本|
|保留DevKit的1000台工程估算，95%良率|165–250|14.60–99.60|高位仅余14.60，不能证实299可盈利|
|商业108＋新开模NRE按1000台摊销|223–408|−143.40至41.60|新模高位已亏损，必须按实际工艺/总量复审|
|保留DevKit＋NRE按1000台摊销|280–550|−285.40至−15.40|该组合不足以支持299商业可行性|
|100台打印/复模工程小批，90%良率|283–467|−202.40至−18.40|不能据此承诺299发售，先完成样机门槛|

结论：**299是唯一目标，当前证据尚未验证其可行性**。需要真实RFQ、模块化降本/公模可行性、良率及渠道/售后核算；若不成立，向主控提交价格/成本决策，不另立499首发口径。数量/资金/日期门槛以[验收与排期](../manufacturing-commercial/acceptance-and-schedule.md)为准。30天节点受到货、工程与合规验收限制；未满足则工程评审，不强制交付。

## 七天样机工程计划（依赖到货，不承诺量产）

|日|工程活动|当天可验收产物|门槛/退路|
|---|---|---|---|
|D1|冻结OEM实际总成、开发板版本、屏/开关MPN；卡尺与光学基准测量|标注尺寸表、接口/供电评审、改CAD差异|未到货则只能数字样机，不启动精密加工|
|D2|工程师复审原理图、DRC、ESD/反灌/连接器；修改后复跑|签字版受控BOM/PCB与线束图|未通过则洞洞板/线束开发，不下正式PCB|
|D3|透明/底壳试片及零件打印；载板快样或手焊等效连接|壳体与铜螺母试片、上电前连通检查|壁厚/黄变/公差问题当天修件|
|D4|限流电源上电；3V3、满白屏/RGB、隐私反灌测试|电流/电压波形、端口枚举记录|异常断电定位，不接用户主机冒险试用|
|D5|OEM原功能装配，独立ESP串口握手；断网/断心跳/隐私态联调|鼠标原生HID通过、LB1 ASCII+CRC16串口日志|USB两路保持独立，固件问题不掩盖成硬件融合|
|D6|手感、线缆止拉、短时热测、触摸误触、初步ESD预扫|至少3人握持记录、问题清单|不把预扫当正式认证，任一安全/结构问题阻止试销|
|D7|修订并装出目标5台；主控演示与评审|可重复演示样机、实测验收记录、下一轮ECO|未达门槛明确延期；本周目标只有样机|

## 制造就绪矩阵

|领域|当前级别|实际证据|仍需工作|
|---|---|---|---|
|概念与参数化CAD|数字EVT|CadQuery源、逐件STEP/STL、BREP有效性与干涉报告|公差链/壁厚/跌落/按钮机构/OEM适配|
|可视化|概念渲染|Blender场景、PNG、转台源|没有实物摄影；光导/发光窗为视觉示意|
|PCB拓扑与铜线|数字EVT|可编辑KiCad，实际走线，CLI ERC/几何DRC/含schematic-parity报告|器件冻结、板级电气/ESD/热/反灌评审|
|制造文件|评审用|Gerber、钻孔、BOM、PnP、网表|全部NOT-FOR-FAB，未授权下单|
|固件接口|LB1冻结合同|已只读核对软件/固件实现、N8R8 profile与GPIO；主控报告两目标编译及HAL测试通过|未烧录/未真实串口板测；触摸阈值仍0|
|电源/热/无线|未实测|预算与净空规则|示波器、温升、USB约束、RF对比|
|供应链与成本|估算|批量/税/良率/NRE口径|供应商报价、料号替代、可追溯性|
|认证/量产|未开始|无证书、无板测、无工厂验收|法规评估、DVT/PVT、工装与来料/出货标准|

## 装配顺序与验收清单

1. 核对底壳、柱高、光学孔和底脚基准；OEM总成裸机做鼠标按键、滚轮、移动、不同桌面检查，记录基准性能。
2. 给载板底面贴绝缘片，所有不装位确认，焊点清洁；万用表确认3V3/GND无短路，J1/J3脚1朝向正确，未连接5V。
3. 将已检查的开发板插入2×22插座，确认无错位、无弯针；暂不安装透明壳。载板与OEM保持电气绝缘，不并接两路USB供电。
4. 外部DPDT先用通断档标公共端、允许端、隐私端；照J7定义接线，外壳印有ON/PRIVACY。屏、RGB、触摸线束逐根核对，不凭线色判断。
5. 限流上电记录冷启动、满屏、RGB和无线峰值；USB A/B分别枚举。未确认输入电源能力时关闭Wi-Fi。记录3V3最小值与复位次数。
6. 隐私态：灯/屏物理电源切断，LB1 STATE报告privacy=1、led=off、touch=0、text为空；无推送事件；detach PWM、Wire.end、GPIO4–9 INPUT且无内部上拉，灯/屏不显示privacy，指示由UI/开关本体提供；测SW3V3漏电和电压，拔断状态线仍默认隐私。主机审批执行独立，不由触摸授权。
7. 装屏框、插雪花，再装城堡独立底座/定位销；检查与天线和壳体至少预定间隙。紧M2螺钉不强拧树脂，不热熔透明壳。
8. 排两根USB线，安装实际止拉件；合壳后重复OEM性能、供电与触摸测试；记录重量、手感、线缆干涉、噪音、发热、磨擦和刮手边。
9. 连续2小时演示循环、100次隐私切换、20次USB插拔/断心跳恢复作为EVT初筛建议；不是可靠性/寿命认证。跌落、拉力、ESD正式指标由工程师确定后执行。
10. 任何未确认项阻止进入fab-candidate或对外销售。工程师签字、受控版号、生产BOM、厂商DFM与首件验收后才可考虑下单。

补充RF装配门槛：载板上端孔、后部壳体紧固点可能落在天线周边15mm建议无金属区内；数字PCB禁铜通过不代表整机天线净空合格。首版默认关闭Wi-Fi/BLE，使用USB-UART。若启用无线，必须将附近紧固件/铜螺母改为经尺寸确认的非金属固定方案或移位，并复核天线参考设计与RSSI/吞吐。不得把当前通用铜螺母方案当作已完成RF设计。

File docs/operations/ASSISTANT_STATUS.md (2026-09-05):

# 助手监督状态 / README

本任务按 gpt-6-astra / low 会话配置执行。已读仓库 AGENTS.md。仅交付本文件、`scripts/supervise.py` 与 `.local/assistant-supervisor/` 本任务状态；未修改 session_runner.py，未进行 Git、UI、外联、付费操作，未读取原始需求、env 或密钥。

## 实际检查与运行

2026-09-06 启动后台监督 PID **47112**，PID 文件 `.local/assistant-supervisor/pid`。每 60 秒本地检查，默认最多 10 小时；不需要 LLM 长驻轮询。运行记录为 `status.json`，退出记录为 `lifecycle.json`；以 PID 文件及实际进程为准，历史退出记录不代表新进程退出。

首次检查：assistant / hardware / pitch / software 均为 running、attempt=1；主控心跳 `at=2026-09-06T00:51:54.349654+08:00`、`state=working`，thread_id 与真实主控 `01a0725c-ccf9-7192-8446-f23b0f6d55e3` 一致。本次限定日志尾部未见结构化错误、429、断网或退出事件；并非完整历史无错误的保证。没有发送真实恢复消息。

## 监督范围与恢复合同

- 只读取 `.local/sessions/*.status.json`、对应同名 `.jsonl` 最后 64 KiB，以及 `.local/root-heartbeat.json`。日志只分类顶层 CLI `error`、`turn.failed`、`thread.failed`、`process.exited`、`session.exited` 事件；忽略提示词、工具输出及普通文本中的错误字样，不保存原文。计数是滚动尾部计数，不是累计。
- 会话状态记录 state / attempt / exit_code；子会话故障只观察。session_runner 已有 CLI 重试，监督器不启动、恢复或终止其他会话。
- 主控心跳 at 必须是带时区 ISO 时间，thread_id 必须匹配真实 ID；过期阈值默认 600 秒。缺失、损坏、未来时间或 ID 不符均不触发恢复。
- 还必须由同一主控心跳或同 ID 状态提供：state 为 failed/error/crashed/exited/disconnected/rate_limited，`recovery_required: true`，非空稳定 `failure_id`，以及不早于心跳、不晚于当前时间的带时区 `failed_at`。同一故障不得反复生成新 ID。主控任一 running/working/waiting/ui_wait/waiting_ui/waiting_for_input/retrying/completed/stopped 状态否决恢复。
- 当前心跳没有这些故障字段，因此当前仅观察。单纯心跳超时、正常长任务、UI 等待、子会话退出、普通错误日志，都不足以恢复主控。不以运行时长判死，不强制重启。
- 条件满足才执行官方 `codex queue --thread 01a0725c-ccf9-7192-8446-f23b0f6d55e3 --message 继续`。故障哈希在调用前持久化，每个故障至多调用一次；失败或超时也不重试该故障，跨故障至少退避 30 分钟。CLI 超时 30 秒。队列接受不等于主控已恢复。锁防止重复监督进程；保留 ledger.json 才能维持跨启动去重。

## 复现与停止

从仓库根目录运行：

```sh
python3 scripts/supervise.py --self-test
PYTHONDONTWRITEBYTECODE=1 python3 .local/assistant-supervisor/test_supervise.py
python3 scripts/supervise.py --once
python3 scripts/supervise.py --hours 10
```

`--once` 仅观察，不排队；已有监督进程时锁会拒绝第二实例。后台进程已启动，不需重复启动。随时停止：

```sh
touch .local/assistant-supervisor/STOP
```

也可核实 PID 后发送 SIGTERM。STOP 每秒检查；若正在调用 queue，等待该调用退出或最多 30 秒超时。后续手动重新启动前只删除本任务 STOP 文件，保留 ledger；最长运行由单调时钟限制，退出清除 PID 文件。

实际验证：合成测试通过 14 项判定/去重断言；独立临时合成状态、mock subprocess 验证官方命令参数、跨运行故障去重、30 分钟退避、STOP、短期限退出、结构化日志过滤。测试零真实 queue 调用。官方 `codex queue --help` 已验证命令存在。生产快照成功，后台存活检查见本任务状态。未验证真实故障恢复、长达 10 小时连续运行、网络断开后队列送达或重新联网恢复。

## 权限与账户待办

Ghostty CUA 已明确拒绝该 app：监督器不会绕过，也无法自动授予权限或输入密码。账户剩余 2% 时进行一次正常重置是用户要求，但目前没有证据证实该控件存在。待主控通过 Chrome 核查余额和正规重置机制；仅正规可用重置才可执行。本任务没有执行重置、购买或切换账号，也无法从这些本地状态监控余额。

监督器能在本机进程仍运行时观察已落盘状态；不能保证断网时 LLM 继续工作，不能修复网络、绕过权限、确认未落盘故障或保证主控写心跳。电脑睡眠/关机、磁盘故障、队列不可用会影响监督与恢复。故障证据不足时保持不操作。

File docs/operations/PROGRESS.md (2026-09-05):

# 执行进度

更新时间：2026-09-06T02:30:12.526156+08:00

交付及验证完成，已推送私有GitHub并发布Release。14个附件（13个交付物+SHA清单）的服务器大小、上传状态和SHA-256均与本机一致。

|工作流|本地完成结果|
|---|---|
|软件|员工/企业工作台、权限/撤销/审批/outbox、任务记忆、主动规则；59项自动测试|
|临时模型|gpt-6-astra / medium，真实HTTP三场景成功；固定合成文字，默认离线，19/20测试预算|
|浏览器|隔离Chrome 14项场景+9项模型UI检查；真实软件28秒录屏|
|固件|safe与EVT-A两配置编译，LB1 104行共用向量，独立HAL安全状态复核|
|硬件|20件CAD、真实KiCad布线，ERC/DRC/parity归零；保留NOT-FOR-FAB|
|工厂|硬件专用ZIP、167项整合评审ZIP、RFQ/验收/七天样机计划|
|商业/路演|16页BP、18页PPTX/PDF/离线HTML、逐字稿、60问、财务模型与生态计划|
|视频|8条2K/15秒+2分钟合集；8个API任务全部成功，刊例预占96元/100元上限|
|安全|.env为0600且Git忽略；不进镜像/工厂ZIP；门户私有路径拒绝；发布前扫描|

## 交付边界

尚无实物样机/通电/烧录/认证/量产证据，没有外发连接器、厂家联系、采购下单或生产部署。299元与1000台108元成本是目标/模型，DevKit五台样机的工程估价单列。模型提供方响应不能独立认证其模型别名；失败诊断缺少完整usage，不编造全程模型费用。

入口：[总README](../../README.md)、[验收矩阵](../verification/RELEASE_READINESS.md)、[附件](RELEASE_ASSETS.md)。

发布地址：https://github.com/huapohen/imagine/releases/tag/v0.1.0-evt-a-20260906

发布校验：[GitHub附件证据](../verification/github-release.json)。源码发布基准：`5c4de598698949c652809cd4b7987b8d8f200e82`；后续主控提交仅补充发布状态与报告。

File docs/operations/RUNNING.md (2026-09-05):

# 本次交付运行记录

核对时间：2026-09-06T02:36:03.042277+08:00

- 默认离线应用：`http://127.0.0.1:8765/`，真实health检查ok，后台worker无错误。启动命令`./software/start.sh`；本次私有角色链接位于权限0600的`.local/demo-server.log`，终端可查看，资料服务器禁止访问该路径。
- 资料中心：`http://127.0.0.1:8766/`，已在用户Chrome打开最终页；8项隔离浏览器检查通过，10个视频均取得可播放元数据，桌面/移动截图已保存。
- 一次性合成QA服务18765已停止，内存数据库销毁、私有令牌文件清理。
- 所有软件、硬件、PPT及修复CLI均已正常完成，未遗留付费模型或视频生成进程。会话ID与退出码见`CLI_SESSIONS.json`。
- 本地监督器已收到STOP，停止监视；没有执行真实故障恢复、额度重置、购买或GPU租赁。十小时是本次工作上限，未声称连续运行十小时或自动恢复保证。

应用和资料中心为本机进程，重启电脑后需要重新执行启动命令。不改系统开机启动、代理或用户浏览器保护。当前Chrome配置对8765的拦截曾存在；可直接查看真实软件录屏与测试证据，未为此关闭保护。

复现浏览器验收：先执行`python3 scripts/browser_qa_server.py`，再执行`scripts/verify_browser.mjs`与`scripts/verify_model_ui.mjs`（Node+Playwright环境定位见脚本）；这两项不调用第三方模型。模型实时测试另有显式开关，当前剩余1/20调用，不自动补充。

最终发布完成：私有仓库Release可访问，14附件校验一致。主控停止临时监视后，保留上述两项本地服务；不再自动消耗模型或视频预算。

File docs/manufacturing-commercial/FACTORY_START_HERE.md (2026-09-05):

# 晶鼠 EVT-A：工厂评审与样机交接入口

本包用于电子/机械工程师复核、供应商报价与五台样机计划。**所有制造输出仍为 NOT-FOR-FAB，请先完成下面的确认，再形成可下单版本。** 本次没有向工厂发出订单或消息。

## 先看这五份资料

1. `hardware/COMPLETION.md`：实际产物、数字检查和实物待验证项。
2. `hardware/specs/architecture.md`、`pin-map.md`：双USB、开发板、模块引脚和LB1接口。
3. `docs/verification/HARDWARE_REVIEW.md`：独立检查与整改结果。
4. `docs/manufacturing-commercial/rfq-template.md`：按同一规格拆项报价。
5. `docs/hardware/engineering-and-manufacturing.md`：装配、七天计划和制造门槛。

## 实物确认与签字

|责任|工厂/工程师须确认|完成证据|
|---|---|---|
|OEM鼠标与机械|真实总成尺寸、固定孔、光学中心/透镜高度、按钮与滚轮行程、止拉件、屏幕模块及开关包络|实测图纸、试装、干涉与公差记录|
|电子|开发板型号与针序、OLED与共阳RGB具体料号、DPDT两极线束、稳压器/USB供电能力、D1 ESD选型|MPN与图纸、原理图/BOM复核签字、台架测量|
|固件联调|USB-UART桥115200、LB1握手与CRC、40ms隐私释放、5秒断联安全态、触摸阈值标定|真实串口记录、灯屏/开关操作视频、功耗与反灌测量|
|透明件与装饰|材料/工艺、透光/黄变/刮擦、壁厚、装饰防脱、手感、开模前公差|样块与首件照片、装配与耐久检查|
|质量与合规|ESD/EMC、USB稳定、温升、跌落/按键寿命、包装运输及适用认证|测试计划、报告、失效整改与小批验收|

请分别报5台EVT、100台小批与1000台估算，列税费、运费、MOQ、NRE、透明件工艺、良率、返工责任、交期和质保。299元是未来核心版目标零售价；商业模型108元批量制造成本不是本包五台开发板样机的报价要求。

当前固件触摸阈值为0，未标定时禁用触摸。safe配置全部交互引脚禁用；EVT-A配置仍需实物审查后才能接线/烧录。机械隐私开关切灯屏外围电源，固件停止相关GPIO驱动；电脑上的Agent进程及OEM鼠标HID不因此断电。

收到资料、生成Gerber、编译固件、ERC/DRC为零，均不等于已获得投板或量产批准。

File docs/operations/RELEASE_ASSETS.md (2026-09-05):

# 私有Release附件

版本：[`v0.1.0-evt-a-20260906`](https://github.com/huapohen/imagine/releases/tag/v0.1.0-evt-a-20260906)。仓库保持私有，需要已授权GitHub账号访问。

视频和评审ZIP在本机已经生成；它们作为Release附件分发，避免普通Git历史反复存储大媒体。源码、PPTX/PDF、文档、渲染图和验证报告在仓库内。

|附件|用途/恢复位置|
|---|---|
|`01_crystal_mouse_focus.mp4` 至 `08_robot_extension.mp4`|八条2K/15秒成片，放入`media/final/`|
|`LINGBAN_8_concepts_2min.mp4`|2K/120秒合集，放入`media/final/`|
|`lingban-software-demo.mp4`|28秒真实浏览器软件演示，放入`media/demo/`|
|`lingban_evt_a_review.zip`|完整硬件数字工程评审包，NOT-FOR-FAB|
|`lingban_factory_review.zip`|硬件、固件源/接口、RFQ与验收整合包；先读包内`FACTORY_START_HERE.md`|
|`lingban_minimax_originals.zip`|8条未修改的提供方原片，保留AIGC元数据；解压到仓库根即还原`media/generated/`|
|`SHA256SUMS.txt`|上述13个文件的精确SHA-256；同内容机读清单见[RELEASE_ASSETS.json](RELEASE_ASSETS.json)|

## 新电脑恢复

在仓库根目录、已登录具有仓库权限的`gh`环境执行：

```sh
gh release download v0.1.0-evt-a-20260906 --repo huapohen/imagine --pattern '0*.mp4' --pattern 'LINGBAN*.mp4' --dir media/final
gh release download v0.1.0-evt-a-20260906 --repo huapohen/imagine --pattern 'lingban-software-demo.mp4' --dir media/demo
gh release download v0.1.0-evt-a-20260906 --repo huapohen/imagine --pattern 'lingban_*_review.zip' --dir hardware/delivery
gh release download v0.1.0-evt-a-20260906 --repo huapohen/imagine --pattern 'lingban_minimax_originals.zip' --pattern 'SHA256SUMS.txt' --dir release
```

下载后对照机读清单的`local_path`和`sha256`核验；同名文件已存在时`gh`默认拒绝覆盖。原片ZIP只在需要重新后期时下载，不是播放成片的前置条件。

本地重算附件哈希：`python3 scripts/release_manifest.py`。模型`.env`、API账本/限时下载地址、角色令牌、软件数据库、CLI私有日志、安装包和工具环境均不进入附件。

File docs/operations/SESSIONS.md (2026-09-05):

# 会话登记

主控制器：`01a0725c-ccf9-7192-8446-f23b0f6d55e3`，负责集成、预算、独立验收与私有发布。独立Codex CLI使用gpt-6-astra并显式指定推理强度；临时应用模型默认medium。

Ghostty访问被CUA明确拒绝：`Computer Use is not allowed to use the app ... for safety reasons.` 已采用独立CLI PTY执行，没有通过其他方式操纵被拒绝的Ghostty应用。私有提示词与日志留在Git忽略的`.local/sessions/`。

|CLI任务|模型/推理|线程ID|状态|
|---|---|---|---|
|assistant|gpt-6-astra / low|`01a0727b-d519-7843-bf7c-d9bed7e1b18b`|completed|
|hardware|gpt-6-astra / high|`01a0727b-cbe3-7931-8d31-374ce90a032f`|completed|
|hardware_fix|gpt-6-astra / high|`01a0727b-cbe3-7931-8d31-374ce90a032f`|completed|
|pitch|gpt-6-astra / high|`01a0727b-d084-79c1-8074-8b08c55c0373`|completed|
|pitch_fix|gpt-6-astra / high|`01a0727b-d084-79c1-8074-8b08c55c0373`|completed|
|software|gpt-6-astra / high|`01a0727b-c769-70e0-81e9-ea5e04341f48`|completed|
|software_fix|gpt-6-astra / high|`01a0727b-c769-70e0-81e9-ea5e04341f48`|completed|

协作会话：business_research完成商业/16页BP及最终口径复核；video_research完成视频规格、免费后期与真实软件录屏；integration_review完成独立软件/电气/协议/制造包审查；model_integration以gpt-6-astra/medium完成临时模型接入和真实测试。各工作按目录分工，主控统一提交。

监督器仅记录本地运行状态，未使用恢复重置、购买额度或租GPU。其最长10小时是上限，不代表已经连续监测10小时，也不能保证主控故障自动恢复。实际停止/服务状态见[运行记录](RUNNING.md)。

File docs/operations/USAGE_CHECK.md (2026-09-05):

# 用量核对

2026-09-06T02:03:59.923647+08:00，经已登录Chrome使用情况页实际查看：每周剩余 **57%**，显示约1天8小时后重置。页面提供两次「完全重置」正常控件。

本次没有使用重置、购买额度、打开自动充值或租用GPU。用户授权的2%阈值未达到。监督脚本不读取账号用量，也不承诺自动执行浏览器操作。

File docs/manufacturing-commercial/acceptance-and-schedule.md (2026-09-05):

# 样机、试产验收与采购排期

2026-09-06｜拟定工程/商务门槛，未完成实验室认证和实物测试。D1指团队真正开始执行且物料可用的首日，不代表今天已经开工。

## 7天目标：5台可重复演示样机

| 天 | 工程/采购动作 | 当天证据 | 不满足时 |
|---|---|---|---|
| D1 | 冻结单一299版；清点现成OEM鼠标、S3开发板、屏和触摸件；发RFQ须项目授权后由负责人实际执行 | 规格v0.1、库存与短缺清单、5台样机BOM | 降为外置灯/触摸原型；不抢开模 |
| D2 | 台架接线；验证鼠标独立枚举和指针/按键；模块单独通信 | 原始USB日志、功耗记录、接线图 | 保留双USB，不强行合并 |
| D3 | 完成灯/触摸/屏状态机和本地任务事件闭环 | 可重复输入→提醒→理由→确认演示 | 减少动画，先保核心链路 |
| D4 | 制作可装配展示壳/固定架；评估手感、热、线缆与电路隔离 | 尺寸实测、装配照片、风险清单 | 外置伴随模块；标注非量产壳 |
| D5 | 装配5台、编号、离线模式与断连恢复测试 | 每台测试记录、固件版本/hash | 隔离不良，不混入演示 |
| D6 | 10个场景重复演示；邀请少量自愿内部试用 | 演示视频/缺陷清单/授权记录 | 停止问题场景，只展示已通过路径 |
| D7 | 设计评审，确认下一步是否进入EVT | 5台样机或明确失败原因；更新BOM/报价偏差 | 不宣布出货，不向付费客户交付未验收样机 |

7天验收：5台中的全部可完成鼠标基本功能、任务提醒/触摸查看、个人静音/暂停、模块断开后鼠标可用；连续8小时桌面运行无不可恢复故障；未授权事件不进入企业端，外部动作不自动执行。此测试不等于可靠性认证。

## D8—D30：条件成立才交付50—100台受控试产

D8—D10：选定候选工厂、DFM、10台EVT、冻结BOM候选和禁替代清单；实验室先判断适用标准与排期。D11—D14：解决高优缺陷、20人自愿试用开始、完成USB兼容/电气与外观初检；无合格物料不提前下大单。D15：G1评审；通过才签受控试产单，争取50—100台；付款、数量和期限需要具体合同。D16—D21：物料来料检查、首件确认、产测治具/程序验证、装配；并继续7日使用反馈。D22—D25：100%功能检查、规定抽样可靠性测试、返工复测。D26：G2评审核对合规判定、追溯、售后、个人数据和实际需求。D27—D30：只向已同意试产条件的客户分批发货；留售后备件与问题隔离空间。

若新增注塑模具、定制PCB返板、实验室排期、强制合规项、供料或人体工学任一未解决，30天节点改为工程评审，不强制发货。量产预测从实际EVT/PVT完成后重排，7天/30天不是对外交付保证。

## 三道放行门

| 门 | 放行条件 | 签字角色 |
|---|---|---|
| G0 原型→EVT | 独立鼠标链路、基本授权闭环、5台记录齐全、无安全关键缺陷 | 工程/产品 |
| G1 EVT→试产下单 | 10台EVT功能通过；DFM/BOM/合法USB身份明确；合规路径无未决强制障碍；20人测试已开始；资金能覆盖全单＋售后 | 工程/采购/财务 |
| G2 试产→交付 | 最终要求的测试/合规完成；100%出货功能合格；一次良率>=95%；无严重外观/电气/隐私缺陷；序列号可追溯；目标D7仍启用>=60%、至少半数确认有用；合同/退换/保修/数据说明齐备 | 质量/产品/交付负责人 |

这些是内部管理阈值而非统计质量保证。仅20人的留存不用于公开普适效果宣称；失败时先改产品，不放宽门槛掩盖问题。

## 验收矩阵（由工程把数值冻结进规格）

| 项 | 试产方法/数量 | 接受条件 |
|---|---|---|
| 鼠标基础功能 | 每台移动、左右键、滚轮、DPI功能如有；实机Win/macOS；Linux为扩展矩阵 | 无丢键/卡键/光学遮挡；登记实际系统版本 |
| USB链路 | 每台插拔10次；样本10台每台100次；挂起/恢复20次 | 枚举稳定；AI模块复位不拖垮鼠标；未通过hub方案退回双线 |
| 功耗/温升 | 样本5台测待机/最亮/通信/故障工况；8小时运行 | 不超USB协商供电及器件额定值；接触表面温度目标<=42℃（环境25℃），最终依合规实验室评估 |
| 灯/屏/触摸 | 每台显示测试图和全部状态、触摸100次；5台连续1000次 | 无坏点明显缺陷/失联；触摸只请求批准，不直接外部动作 |
| 透明壳外观 | 每台固定光照/距离检查并与签样比较 | 无锐边/裂纹/裸露导体；划痕、缩水、气泡按双方限度样定义 |
| 线材/应力释放 | 样本5台按双方确认弯折/拉力规范 | 无导体露出、接触不良；具体载荷由结构/实验室冻结 |
| 运输包装 | 3件包装样按适用运输测试方案跌落/振动 | 开箱功能正常、壳无裂、包装信息完整；不以自定跌落替代标准 |
| 8小时老化 | 全批或治具产能允许的完整计划；序列号记录 | 无死机/异常温升/显示故障，失败批隔离 |
| 数据边界 | 每固件/软件版本做未授权输入、撤回、暂停、删除、团队<5人、敏感字段注入 | 不对外发送、不产生个人绩效/生理推断；日志不含凭据 |
| EMC/ESD/安规/物质 | 最终结构与供电方案送有资质方，按适用规则 | 报告覆盖确切型号/版本，未完成必须标未完成并禁止需要该项的销售 |

100%功能检验与抽样破坏性试验分开。首批小批不照搬AQL表；如后续用GB/T 2828.1/ISO 2859-1，应书面确认批量、检验水平、AQL、Ac/Re和严重缺陷零接受规则。关键安全和隐私缺陷零容忍，任何一例触发批次隔离与根因评审。

## 采购与库存控制

建表字段：PO号、物料料号/版本、供应商、MOQ、单价含税口径、订购数、承诺日期、实到数、检验状态、付款节点、ECN、批次。第一单最多覆盖50—100台＋经批准的备件；未经需求门槛不提前下1000台。长交期屏/壳料优先双源评估，不能因断料随意换料；不预购无线芯片/电池/机器人电机。

缺陷返修先登记序列号、问题、固件和工位，再更换件和复测。返修设备本地不留用户任务资料；如果处理电脑agent问题，由用户导出脱敏诊断。退换政策、保修承诺与法定义务由销售地区实际规则审定，不以“试产”免除法定消费者权利。

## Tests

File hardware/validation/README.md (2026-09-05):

# 实际验证记录

- `cad-brep.json` / `cad-intersections.json`：实际OpenCascade实体有效性、逐件包围盒/体积与两两正体积干涉；阈值0.05mm³。不代表公差链、壁厚或实物装配测试。
- `stl-mesh-check.json`：导出的STL经trimesh检查封闭、水密、法向、正体积、连通组件。复现 `hardware/tools/venv/bin/python hardware/validation/validate_artifacts.py`。
- `pcb-drc.json` / `sch-erc.json`：KiCad9.0.7真实检查，parity命令带`--schematic-parity --exit-code-violations`，独立几何报告为`pcb-geometric-drc.json`；报告没有靠排除/忽略规则抹掉错误。`kicad-command-results.json`记录真实导出退出码。
- `netlist-pinmap-check.json`：独立官方引脚预期对实际KiCad XML网表；49功能＋33明确NC焊盘用完整网名逐项对照原理图网表，不去掉/前缀，且NC必须单脚无铜。检查避开5V、USB、UART、绑带与PSRAM脚。
- `routing-summary.json`：自编双层网格路由器统计；路由器宣称成功不能替代KiCad DRC，须结合正式报告。
- `media-probe.json`：ffprobe真实MP4编码/分辨率/时长。PNG/视频均概念演示，无实物照片。
- `network-probes.json` / `mirror-probes.json` / `tool-integrity.json`：下载线路与完整性。工具日志里首次下载失败/旧迭代失败保留审计，不代表最终产物失败。

未进行任何电气通电、固件烧录、示波器峰值、热、ESD、RF、HID装配性能、按钮寿命、人体工学、认证或厂家DFM验证。完整已测/未测边界见COMPLETION与docs/hardware。

本轮整合证据在`integration/`：before报告复现86项parity差异；result报告为0，并核对118个既有CAD/渲染文件hash和PCB几何不变、GPIO/N8R8/LB1与只读实装来源一致。主控报告两目标固件编译与HAL隐私/共阳/断联通过；本轮没有重复编译、烧录或实物测试。

交付包清单采用明确格式白名单，不含tools、cache、.env、KiCad本地状态和临时锁；`delivery/package-audit.json`记录ZIP完整性、条目与manifest哈希核对。

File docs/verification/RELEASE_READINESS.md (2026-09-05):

# 最终交付验收矩阵

2026-09-06，主控集成。此版本可用于本地产品演示、项目/投资评审和深圳工厂技术讨论。制造状态保持 **NOT-FOR-FAB**；下表严格区分已执行的数字验证与尚无实物证据的项目。

|交付|实际验证与结果|证据|未验证边界|
|---|---|---|---|
|软件/权限|59项自动测试；服务端角色隔离、并发审批仅一次、撤销共享与A2A缓存、插件越权拒绝、规则提醒、持久化|`./software/test.sh`、`software/tests/`|生产部署、真实企业连接器、多用户负载|
|真实模型|WanAPI Responses，gpt-6-astra / medium；会议、阻塞、休息三个HTTP场景成功，均pending；重复幂等不增加调用，未批准outbox为空|[模型验收](../software/MODEL_INTEGRATION.md)|总预留19/20含诊断；成功三次1980 tokens并非全程用量；不能独立认证提供方模型别名或保留策略|
|员工/企业网页|隔离Chrome 152，14项场景回归+9项模型入口/离线回退/同意检查；桌面与390px移动布局，未见前端异常|[场景报告](browser/report.json)、[模型UI](browser/model-ui.json)、同目录截图|用户既有Chrome配置访问8765曾返回ERR_BLOCKED_BY_CLIENT，未关闭其保护；无实机硬件|
|固件/设备协议|LB1 Python/C++共用104行golden；独立75条CRC核验；Mock HAL隐私高阻、共阳反相、5秒离线、去抖/回绕；safe/EVT-A两目标实际编译|[固件](../../firmware/README.md)、[独立HAL源](hal_independent.cpp)、[硬件评审](HARDWARE_REVIEW.md)|未烧录、未接线、触摸阈值未标定、OLED为候选|
|CAD|20件有效STEP/BREP、20件水密STL；完整生成报告无>0.05mm³正体积干涉；独立STEP回读与关键部件求交通过|`hardware/validation/`、`hardware/cad/exports/`|OEM/器件仍有占位；壁厚、公差、人体工学、装配、止拉与强度须实测|
|KiCad|官方9.0.7 ERC0、几何DRC0、未连线0、schematic parity0；82个针脚精确网名一致，4个机械孔声明board-only|[独立复核](HARDWARE_REVIEW.md)、`hardware/validation/pcb-drc.json`|ESD料号/模块针序/电源峰值/反灌/EMC/DFM签字未完成|
|商业资料|16页BP PDF，财务CSV可重算；299核心目标、108批量估算、66.51贡献；500万元融资建议与60万元经营模型分开|[BP验收](../../pitch/business-plan/QA.md)、[商业复核](BUSINESS_RELEASE_REVIEW.md)|非报价、收入、融资或订单实绩；本次未验证真实留存与购买|
|路演|18页可编辑PPTX、PDF、离线HTML及讲稿；286段正文一致、中文渲染检查、HTML15项检查|[PPT验收](../../pitch/qa/QA-report.md)|未验证Microsoft PowerPoint/Google Slides原生编辑保存及放映机字体|
|AI影片|8条各15.000秒、2560×1440；合集120.000秒；中文旁白/字幕/概念标签；原片及来源哈希保留|[媒体验收](../../media/FINAL_REPORT.md)|生成形态与CAD存在差异，不能证明功能、实物或运动安全|
|软件录屏|28.000秒真实隔离浏览器录屏与同次验证定格截图；明确合成数据/设备模拟/离线规则|[录屏来源与QA](../../media/demo/README.md)|早期已通过规则界面快照，不展示新增模型按钮，不是硬件录像|
|资料服务|14项公开/私有路径验证；.env、.local、私有API账本、下载与工具目录均拒绝访问|[路由检查](portal-access.json)|仅回环服务，无公网部署|

## 交接后的下一步

按[工厂入口](../manufacturing-commercial/FACTORY_START_HERE.md)取得OEM/模块真实图纸和拆项报价，完成电子机械复核后再形成可下单版本。七天目标是五台样机；30天试销取决于器件到货、合规与小批验收。没有对外发送采购/投资消息，没有下单、开模、租GPU或生产发布。

## 安全与费用记录

临时模型`.env`为当前用户0600文件，Git忽略；镜像和工厂包不包含它。真实模型只处理固定合成文本，默认程序离线。本人同意、权限、审批和预算均由本地程序验证，模型文本不能触发外部执行。

八条MiniMax-H3生成API全部成功，120输出秒按官方刊例预占96元，低于用户100元上限；不是账户最终扣款证明。模型接入人民币成本未从不完整usage推算。没有额外付费生成、付费语音或GPU租赁。

源码、文档及审查证据存于私有仓库；大体积附件、哈希与恢复方法见[Release附件](../operations/RELEASE_ASSETS.md)。用户可以复现检查，也可以直接从本地资料中心打开已生成交付物。

主控发布验收：工厂总包167项文件，内容与最终源快照一致；13个交付附件及SHA清单共14件已上传私有Release，GitHub返回的每件SHA-256均与本机匹配，见[发布证据](github-release.json)。门户另通过8项真实浏览器检查，10个视频均取得正确可播放元数据。

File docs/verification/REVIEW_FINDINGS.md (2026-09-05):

# 独立集成评审：灵伴 LINGBAN

评审日期：2026-09-06。范围为正在集成的数字原型；以下行号对应首次发现时的文件。软件、硬件、商业与演示仍由各自会话持续修改，本报告不是最终完成认证。高优先级发现已即时发送主控；修复后需回归，不能以本报告视为修复证据。

## 2026-09-06 最终回归状态

本轮 R1—R7 均已修复或按明确产品语义关闭；下面的折叠内容和旧口径表保留发现历史，不代表当前未修问题。

- **R1 已关闭**：全新内存 Store 首次 task/meeting 摄入成功；原 9 列/10 占位符错误消失。
- **R2 已关闭**：撤回后企业旧 A2A task 读取 404，同 messageId 重放重新计算 available=false；再次读取不再暴露旧缓存。
- **R3 按明确产品语义关闭**：主控决定按钮为“安静 10 分钟”，只暂停新通知，不承诺同证据到期重发。实测601秒后不重放同证据符合此决定；当前UI、HTTP示例和软件README均明确该语义，保留API名称snooze兼容。未发现当前操作文档承诺“稍后重新提醒”。
- **R4 已关闭**：非文本 file part 实际返回 -32005。
- **R6 已关闭**：RFQ 已明确离散共阳 RGB、GPIO4/5/6 PWM，与载板一致。
- **R5/R7 已关闭**：硬件架构、README/COMPLETION和制造说明已统一首发299灯＋触摸＋OLED、唯一LB1；旧LBP仅明确作为废弃稿。最终软件状态标识为 `LB1/1.0`；早期 `lingban.serial/1` 在协议文档中定义为LB1别名，不是第二种线缆协议。详情与固件修复证据见 `HARDWARE_REVIEW.md`。
- 插件权限较首次审查已有改进：现有专用令牌携带 plugin_id，由服务端强制绑定。实测只读插件令牌即使省略输入 plugin_id，写事件仍返回403；首次报告中“尚无插件专用令牌”的限制已失效。仍不可将 manifest-only 称为完整第三方代码沙箱。

<details>
<summary>首次发现与复现记录（历史；当前关闭状态见上文）</summary>

### R1 / P1：首次任务摄入阻断，连带 seed 无法完成

- 位置：`software/lingban/core.py:56,127`。
- `tasks` 表有 9 列；INSERT 使用 10 个占位符，实际提供 9 个值。
- 实际结果：首次 `task.upsert` 抛出 `sqlite3.OperationalError: table tasks has 9 columns but 10 values were supplied`；`meeting.upsert` 共用此路径；`seed()` 同样依赖首次任务创建。
- 回归：全新内存 Store 建员工，摄入一个 task/meeting；确认首次成功、相同幂等键重放成功、更新版本成功，并在全新数据库启动服务器。

### R2 / P1：企业 A2A 历史缓存绕过分享撤回

- 位置：`software/lingban/protocols.py:58-61,73-78,85-87`；撤回逻辑 `software/lingban/core.py:199-208`。
- A2A 将企业聚合保存到 task 的 artifacts、history 和 status.message。撤回只删除 `shared`，不使这些派生缓存失效。
- 实际复现：5 名员工分别明确分享 completed=10、blocked=1；企业发 `message/send` 得到 50/5。撤回一名后普通企业接口正确返回 `available=false`，但旧 task 的 `tasks/get` 以及同一 `messageId` 重放仍返回 `available=true, completed=50, blocked=5`。
- 修复要求：企业 A2A 派生内容必须受当前授权/统计世代约束；撤回后所有再次读取与幂等重放都应失效或重算，并覆盖三个内容字段。已经由外部接收者保存的副本不能保证追回，应明确此边界。

### R3 / P2：稍后提醒永不重发

- 位置：`software/lingban/core.py:159,173`。
- `snooze` 只设置十分钟 `focus_until`；到期后仍被相同 `fingerprint` 的永久去重阻止。
- 实际复现：内存 fixture 插入阻塞任务，首次 tick=1；反馈 snooze；时钟前进 601 秒；tick=0，提醒总数仍为 1。为继续独立检查，此复现仅在内存直接插入 fixture 绕过 R1，没有修改产品源码。
- 回归：同一未解决任务在稍后期限后准确重提醒一次；无反馈时仍保持去重；任务已解决时不重提醒。

### R4 / P2：A2A 不支持内容类型返回错误代码不符所声明版本

- 位置：`software/lingban/protocols.py:37`；参考 `software/reference/a2a-v0.3.0.json` 的 `ContentTypeNotSupportedError`。
- 非文本 part 实际返回 `-32003`。A2A 0.3.0 规定内容类型不支持为 `-32005`，`-32003` 表示 push notification 不支持。
- 回归：file/data 输入及不支持的输出 MIME 返回 `-32005`；不存在 task 保持 `-32001`。

</details>

## 交付口径发现历史（已关闭）

|编号|实际冲突|收敛要求|
|---|---|---|
|R5|`hardware/specs/architecture.md:6` 写首发 499 元；`docs/product/DECISIONS.md`、商业计划与财务输入写 299 元核心版|统一首发 299 元含税零售目标；5 台工程样机成本单列，不将开发板样机成本当量产 BOM|
|R6|`docs/manufacturing-commercial/rfq-template.md:7` 写可寻址 RGB；硬件架构与 pin-map 写共阳离散 RGB 三路 PWM|RFQ 与工程 BOM/原理图保持同一选型|
|R7|`software/lingban/core.py:250` 写 `lingban.serial/1`；硬件架构与产品决策写 `LBP/0.1`|模拟状态和未来串口编解码明确区分；实际实现共享同一协议版本、帧字段与长度限制，不能只改版本字符串就声称互通|

## 原型可接受限制与真实数据/实物前门槛

- 权限检查：角色和 owner 查询在已阅核心路径中存在；审批有 owner 约束，只有 pending 可决定，批准写本地 outbox 且 action 唯一。未发现该路径会自动对外发送；此处的本地 outbox 是已声明的演示限制。
- 聚合：普通接口强制同组织、当前同意世代与至少 5 人；重新授权清空历史分享，未自动复活旧数据。这个门槛不能防止相邻实时查询差分推断；当前精确实时总和尚无固定统计窗口、差分保护或极端值抑制。商业计划已指出该要求，演示必须继续标合成数据，真实员工数据启用前另行验收。
- 数据生命周期：已阅核心代码尚无自动保留期限或个人全量导出/删除API；撤回业务分享不等同于删除个人任务、事件、审计或全部派生数据。插件已有专用令牌、服务端权限绑定，但 manifest-only 不构成第三方代码沙箱；完整员工令牌仍应只交给员工本人。原型不执行第三方代码，真实数据使用前需另验生命周期合同。
- 隐私开关：最终合同明确物理开关屏蔽外设，不自动改变电脑的主动提醒/专注计时器，不删除个人数据；暂停主机提醒由独立“安静10分钟”控制。最终核心模拟隐私态led=off，提示明确仅在电脑UI；固件的高阻/屏总线停止已由独立HAL测试验证。无真实硬件时不推断物理隔离或瞬时零反灌已获证明。
- GPIO/PCB：GPIO4–10、N8R8保留脚已对照官方文本；后续实际KiCad网表/PCB精确82针脚比较、ERC/DRC/parity均通过，见 `HARDWARE_REVIEW.md`。反灌、功耗和真实信号时序未验证。
- CAD：后续当前20件STEP有效、生成的完整相交报告为空；独立回读base/carrier/canopy与其他有效部件求交亦无>0.05mm³干涉，见硬件评审。没有执行公差链或实物装配验收。
- MCP/A2A：MCP 声明 2025-06-18 stdio tools 子集，A2A 声明 0.3.0 同步文本 JSON-RPC 子集；均明确未认证。已审初始化、工具路由、结构与错误路径；未跑官方客户端互操作认证。未覆盖官方完整协议不作为缺陷。

## 实际检查与复现边界

1. 阅读仓库 AGENTS.md；未读取原始 input/1.txt、任何 .env 或凭据；未用 Git、未付费、未发消息到外部。
2. 静态阅读 `software/lingban/{core,mcp,protocols,server}.py`，用 Python 标准库和内存 SQLite 复现 R1—R4；测试数据均为本次临时合成数据。
3. 阅读产品决策、商业计划/财务说明、RFQ、硬件架构与 pin-map，交叉检查首发售价、RGB 与 LBP 口径。
4. 财务脚本仅在内存替换输出函数后重算，不写商业目录；5 行 SKU economics、33 行 monthly、3 行 summary 均与现有 CSV 完全匹配，脚本内部现金勾稽通过。
5. 本文最初仅覆盖软件核心与文档；后续固件编译、HAL、LB1协议、PCB和CAD检查已在 `HARDWARE_REVIEW.md` 单列。未验证PPT/视频、真实USB设备、实物装配、部署或真实企业数据处理。进行中的文件缺失未列为缺陷。

复现核心导入方式：在项目根目录设置 `PYTHONDONTWRITEBYTECODE=1` 后运行 Python，将 `software` 加入 `sys.path`，导入 `lingban.core.Store` 和 `lingban.protocols.A2A`。所有逻辑复现使用 `Store()` 内存数据库；R3 使用可控 `clock=lambda: now[0]`。主控可按每项给出的输入建立永久回归测试。

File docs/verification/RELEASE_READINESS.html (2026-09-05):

# 最终交付验收矩阵

2026-09-06，主控集成。此版本可用于本地产品演示、项目/投资评审和深圳工厂技术讨论。制造状态保持 NOT-FOR-FAB；下表严格区分已执行的数字验证与尚无实物证据的项目。

交付 | 实际验证与结果 | 证据 | 未验证边界
软件/权限 | 59项自动测试；服务端角色隔离、并发审批仅一次、撤销共享与A2A缓存、插件越权拒绝、规则提醒、持久化 | ./software/test.sh、software/tests/ | 生产部署、真实企业连接器、多用户负载
真实模型 | WanAPI Responses，gpt-6-astra / medium；会议、阻塞、休息三个HTTP场景成功，均pending；重复幂等不增加调用，未批准outbox为空 | 模型验收 | 总预留19/20含诊断；成功三次1980 tokens并非全程用量；不能独立认证提供方模型别名或保留策略
员工/企业网页 | 隔离Chrome 152，14项场景回归+9项模型入口/离线回退/同意检查；桌面与390px移动布局，未见前端异常 | 场景报告、模型UI、同目录截图 | 用户既有Chrome配置访问8765曾返回ERR_BLOCKED_BY_CLIENT，未关闭其保护；无实机硬件
固件/设备协议 | LB1 Python/C++共用104行golden；独立75条CRC核验；Mock HAL隐私高阻、共阳反相、5秒离线、去抖/回绕；safe/EVT-A两目标实际编译 | 固件、独立HAL源、硬件评审 | 未烧录、未接线、触摸阈值未标定、OLED为候选
CAD | 20件有效STEP/BREP、20件水密STL；完整生成报告无>0.05mm³正体积干涉；独立STEP回读与关键部件求交通过 | hardware/validation/、hardware/cad/exports/ | OEM/器件仍有占位；壁厚、公差、人体工学、装配、止拉与强度须实测
KiCad | 官方9.0.7 ERC0、几何DRC0、未连线0、schematic parity0；82个针脚精确网名一致，4个机械孔声明board-only | 独立复核、hardware/validation/pcb-drc.json | ESD料号/模块针序/电源峰值/反灌/EMC/DFM签字未完成
商业资料 | 16页BP PDF，财务CSV可重算；299核心目标、108批量估算、66.51贡献；500万元融资建议与60万元经营模型分开 | BP验收、商业复核 | 非报价、收入、融资或订单实绩；本次未验证真实留存与购买
路演 | 18页可编辑PPTX、PDF、离线HTML及讲稿；286段正文一致、中文渲染检查、HTML15项检查 | PPT验收 | 未验证Microsoft PowerPoint/Google Slides原生编辑保存及放映机字体
AI影片 | 8条各15.000秒、2560×1440；合集120.000秒；中文旁白/字幕/概念标签；原片及来源哈希保留 | 媒体验收 | 生成形态与CAD存在差异，不能证明功能、实物或运动安全
软件录屏 | 28.000秒真实隔离浏览器录屏与同次验证定格截图；明确合成数据/设备模拟/离线规则 | 录屏来源与QA | 早期已通过规则界面快照，不展示新增模型按钮，不是硬件录像
资料服务 | 14项公开/私有路径验证；.env、.local、私有API账本、下载与工具目录均拒绝访问 | 路由检查 | 仅回环服务，无公网部署

## 交接后的下一步

按工厂入口取得OEM/模块真实图纸和拆项报价，完成电子机械复核后再形成可下单版本。七天目标是五台样机；30天试销取决于器件到货、合规与小批验收。没有对外发送采购/投资消息，没有下单、开模、租GPU或生产发布。

## 安全与费用记录

临时模型.env为当前用户0600文件，Git忽略；镜像和工厂包不包含它。真实模型只处理固定合成文本，默认程序离线。本人同意、权限、审批和预算均由本地程序验证，模型文本不能触发外部执行。

八条MiniMax-H3生成API全部成功，120输出秒按官方刊例预占96元，低于用户100元上限；不是账户最终扣款证明。模型接入人民币成本未从不完整usage推算。没有额外付费生成、付费语音或GPU租赁。

源码、文档及审查证据存于私有仓库；大体积附件、哈希与恢复方法见Release附件。用户可以复现检查，也可以直接从本地资料中心打开已生成交付物。

主控发布验收：工厂总包167项文件，内容与最终源快照一致；13个交付附件及SHA清单共14件已上传私有Release，GitHub返回的每件SHA-256均与本机匹配，见发布证据。门户另通过8项真实浏览器检查，10个视频均取得正确可播放元数据。

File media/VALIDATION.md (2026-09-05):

# 实际验证 · 2026-09-06

- 动态读取macOS系统代理并测试端口与目标请求；官方文档直连200约0.380秒、系统代理200约0.571秒，选择直连。明细 `network-check.json`。
- 官方文档指南、创建、查询、列表、按量计费、OpenAPI JSON均HTTPS下载成功。`sources.json`保存URL、抓取时间、本地SHA-256。SHA不是官方签名。
- `python3 video_client.py plan`：8条、每条12.00元、总96.00元；0次网络/付费请求。
- `python3 -m unittest discover -s …/media -p test_video_client.py`：8项全部通过。模拟网络，无真实API。覆盖精确规格价格、未知价格拒绝、额外付费媒体拒绝、免费首帧、请求前预占、超时不自动重提、8条/预算上限、task_id保存、失败预算保留、未授权路由拒绝。
- 客户端与两个制作脚本 `py_compile` 通过。
- 本机ffmpeg 9.0.1、ffprobe、Pillow可用；ffmpeg不含drawtext/subtitles，采用Pillow中文透明PNG叠加。
- 本机实际创建10秒640×360纯色测试夹具+5秒静图，装配输出 `verification/assembly_test_15s.mp4`。ffprobe：15.000秒、640×360、H.264。抽取第12秒画面并目视确认中文标签可读：`verification/label_check.png`。这是技术夹具，不是产品视频、不是2K生成结果。
- 装配脚本保留原分辨率，明确记录源时长/类型/哈希和静态尾帧；不会将10秒片声称原生15秒。

尚未验证：真实API Key权限/余额、真实生成任务及等待时长、实际输出2K像素尺寸/质量、CDN下载响应、真实软件屏幕录制及macOS权限、真实硬件。研究代理未提交任何付费任务、未寻找或读取凭据。最终生成与账单属于主控制器后续执行，不能把本验证报告当作已完成生成证明。

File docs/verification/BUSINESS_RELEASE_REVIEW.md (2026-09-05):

# 最终商业口径复核

日期：2026-09-06。范围：`pitch/deliverables/final-20260906/` 的deck-content、speaker-notes与18页PDF；`pitch/business-plan/` 的16页BP PDF；现行商业Markdown/CSV、硬件规格与工程说明。未读取.env、原始输入、凭据或历史评审作为新问题；未联系外界、付费或操作Git。

## 结论

主要商业口径一致。发现一处商业成本历史假设未标旧，已按主控授权修正；发现一处派生硬件HTML仍含旧首发价，已交主控最终门户构建覆盖。未重新生成PPT/BP或财务CSV。

| 核验项 | 结果与证据 |
|---|---|
| 299 / 199 / 499 | 最终演示第8页、BP第8页、business-plan与当前硬件Markdown均为299灯/触摸/屏首发，199无屏，499未来套装；其他档位非同时制造。触摸是目标功能，硬件规格仍明确当前阈值未标定，不能当成实机完成。 |
| 108元规模模型 | 演示第12页/BP第9页均标1000台假设、无报价，含损耗10元；66.51元是贡献而非净利润。未冒称当前DevKit样机成本。 |
| 当前5台EVT | 工程说明保留450-1000元材料/工艺、240-480元装配，整台690-1480元未税，80%有效良率后约863-1850元/合格台；100台约283-467元/合格台。仍是待报价估算。 |
| 500万元 / 60万元 | 演示第16页、讲稿、BP第11页及源BP第11节一致：500万元为建议，200/100/60/80/60合计500；60万元是独立精简验证模型。未宣称融资已到账、用户指定500万元或500万元跑道已建模。 |
| 财务数字 | 最终演示和BP均为基准期末现金约6.05万元、累计亏损29.02万元；没有把最低现金4.59万元混作期末现金。 |
| 竞品事实 | 演示第9页/BP第7、16页：Microduck官方预售399美元、税运另计；Violoop预发布399美元起、优惠后369美元起。订单/交付/众筹成绩未证实，stars和厂商性能不当作销量或独立测试。 |
| 最终源文/PDF | deck-content的231个实际内容行，归一化空白后全部能在对应最终PDF找到；唯一不计行是“本文件直接取PDF文字”的说明行。两份PDF共34页已逐页提取文本核对指定口径。 |

## 本次发现与处置

**BIZ-01 已关闭：现行商业成本说明仍使用早期简化样机估算。** `docs/business/financial-model.md`原第26行的5台260-480元、50-100台145-190元，现明确标为已被当前DevKit估价替代的历史假设，并链接工程说明。108元仍为未来模块/公模1000台假设；170元仍为敏感性算例，明确不是当前EVT或100台报价。已确认两份最终PDF均无260-480/145-190这些旧区间，所以按主控决定不重建未受影响的PDF/CSV。该说明补充使源文件哈希变化，由主控记录；不应误认为模型已按DevKit工艺逐月重算。

**BIZ-02 待最终门户构建复核：派生HTML旧首发文字。** 检查时`hardware/specs/architecture.html`仍写“首发建议499元工程试销目标”，对应`architecture.md`已改299元目标。主控已获通知，需重生成此HTML并确认不再显示旧首发价。它不是历史评审条目，而是当前可访问生成页的同步问题。

## 核验版本

- 最终演示PDF SHA-256：`20fc938d085bf6f1ff022dec1bfa8d22ef12728ac3bf05f5a94ecc6fc40d369f`
- BP PDF SHA-256：`85253bbf3c1c69c0079d93a5e9b4ade2c1d5eb3ce4a1e2c4227f83a64216a3f2`

本次是发布口径与文本一致性审查，不替代实机、用户、供应商、法规或融资验证。模型3场景成功及受限合成草稿属于主控验证范围；默认离线示例不是生产系统已联调，本审查不扩大该能力声明。

主控最终补记：门户已重建，architecture.html与Markdown同为299元核心版；299条本地链接检查零缺失。BIZ-02已关闭。

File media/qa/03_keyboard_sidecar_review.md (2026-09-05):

# 03 键盘边栏 · 后期QA

实际审阅 `03_keyboard_sidecar_contact.jpg` 中1、5、9、13秒画面：

- 透明城堡边栏、旋钮、键盘与手部可辨识，四个时点未见明显畸变。
- 左上常驻AI概念/非已生产实机标签和片名清晰；底边常驻外观功能待工程验证/合成示意说明。
- 旁白字幕位于下方，避让核心城堡和旋钮；每行文字可读，没有裁切。
- 原片实际15.084秒；成片裁到15.000秒，保留2560×1440，无放大、补帧或静图凑时长。
- 本地Tingting旁白已合成并混入；原片环境音按0.10线性增益混音。ffmpeg实测 -16.06 LUFS / -1.50 dBTP，无削波。旁白文本与字幕来自同一字段。
- 音量为客观测量，未冒称人工耳听。完整可听抽轨 `03_keyboard_sidecar_listen.wav` 供主控试听。抽帧审阅不能排除帧间生成误差，不等同实机工程验证。

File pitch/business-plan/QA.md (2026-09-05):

# PDF质量检查记录

日期：2026-09-06。检查对象：当前16页 `lingban-business-plan.pdf`。

## 已执行

1. 阅读PDF技能，并在首次作者命令前成功运行 `mark_artifact_operation_started.mjs --operation-kind create --expected-output-count 1 --output-format pdf`，仅一次。
2. 使用bundled Python和ReportLab生成PDF；pypdf重新读取确认16页，每页可提取正文文本；关键数字66.51、500万元/60万元区分及融资合计500万元检查通过。
3. 使用bundled `pdftoppm` 实际渲染全部16页，110DPI，生成4×4全稿拼图。
4. 人工目检全16页拼图：封面、章节层级、页码、表格、图表、页脚和来源连续一致，未见内容裁切、重叠或空白页。
5. 单页放大抽查第5页公司授权边界、第9页BOM/单位贡献、第10页三情景现金图、第16页来源；中文、表格和轴标可读，未见缺字或溢出。第1页产品原图亦已独立查看，PDF中明确标非实物概念渲染。
6. pdfplumber逐字检查页面边界；Arial Unicode字符映射检查全部抽取正文，未发现缺失字形或页面之外的文字。检测到PDF内嵌字体子集，未复制字体文件。
7. 财务图表直接读取商业CSV；PDF校验入口与来源清单见 `qa/validation.json`、`qa/source-manifest.json`。原始CSV已通过可重复重算与现金勾稽。

## 覆盖与限制

这是商业计划关键内容的16页阅读版；完整逐字稿、60问、工厂模板及全部财务说明仍保留在Markdown/CSV，没有另制60问PDF。字体缺失、页面边界和数字检查不能自动证明语义完全一致，所以对上述高密度页做了人工细读。

未完成或未宣称：实际硬件/供电/合规测试、用户留存与付费验证、工厂报价、融资可得性、500万元扩张方案的完整跑道模型、实际法律审查。未在印厂实体打样或所有第三方阅读器中验证。

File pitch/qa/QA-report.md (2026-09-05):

# 最终内容同步验收

发布版本：`final-20260906`。日期：2026-09-06。本次仅同步内容和素材，沿用18页版式。唯一发布目录是 `pitch/deliverables/final-20260906/`；旧release移至`.build/archived-deliverables/`。

## 本轮同步内容

- 第5页重新导入最新 `hardware/renders/hero_raw.png`，保留产品主体和概念示意脚注。封面继续采用原创SVG并明确标注“原创产品概念示意”。未把几何检查或概念渲染称为实物验证。
- 第6页根据软件完成记录、协议文档及源码更新为 **MCP 2025-06-18 stdio JSON-RPC tools子集**、**A2A 0.3.0 JSON-RPC同步文本任务子集**。实际支持方法、已有测试覆盖、主要未覆盖项在页面展示，全部限制在讲稿列明。没有官方SDK端到端互通或认证声明。
- 同页明确本稿验收范围是电脑端本地规则Agent，批准只写本地outbox，没有外部发送器。软件完成记录已说明主控正在加入可选模型适配，由其独立验收，本稿不验证模型实现或调用。LB1待实机验证，未接设备或验证硬件连通。
- 第16页及讲稿对齐BP第11节，500万元为本方案建议，非用户指定金额，用途200/100/60/80/60万元。60万元独立运营模型继续采用NRE12万元、月固定5.5万元，基准10个月期末60494.30元（6.05万元），累计亏损29.02万元。不推算500万元跑道。
- 重新生成逐页讲稿、HTML内置讲稿与PDF文字正文deck-content.md，更新source-manifest.json和素材哈希。没有修改商业源或`pitch/business-plan/`。

## 本轮实际验证

| 检查 | 结果 | 证据 |
|---|---|---|
| 完整构建 | `./pitch/build.sh final-20260906-r5`实际成功 | .build/final-20260906-r5/ |
| PPTX结构和回读 | 18页，18份notes，Artifact Tool回读通过 | validation.json |
| 原生可编辑元素 | 原生文字、6张原生表格、原生架构图 | validation.json及PPTX XML |
| 布局与字体策略 | 零finding、零warning，Hiragino Sans GB策略通过 | validation.json |
| 融资金额 | 原生表格显式金额合约：200+100+60+80+60=500 | validation.json |
| 比例与单位贡献 | 40+20+12+16+12=100%；299-108-46.36-33.13-45=66.51元 | content-qa.json |
| 全稿重渲染 | bundled LibreOffice生成18页PDF，Poppler输出18张1600×900 PNG | .build/final-20260906-r5/render/ |
| PPTX/PDF文字 | 286段文字在对应PDF页找到，零缺失，字体资源均嵌入 | content-qa.json |
| 原文/讲稿/HTML | 18页notes与构建原文相符，HTML内置讲稿与来源逐页一致 | sync-qa.json |
| HTML显示图 | 18张嵌入图与最终PNG字节完全相同 | sync-qa.json |
| 构建源码 | 本次实际运行的build.mjs与src/build.mjs字节相同 | sync-qa.json |
| 视觉检查 | 第5、6、16页全尺寸目检通过，全稿缩略图检查通过；已修正第6页LB1文字换行 | visual-review.json；contact-sheet.jpg |
| 未改变页 | 其余15页与此前逐页验收版本像素完全相同 | visual-review.json |
| HTML实际浏览器 | Chrome 152.0.7977.77隔离headless，既有脚本15项检查通过 | html-qa.json |
| HTML实际打印 | 打印媒体显示18页，实际打印PDF页数18 | .build/final-20260906-r5/html-print-check.pdf |
| 来源清单 | 本次构建后复核清单，无源文件漂移；硬件原图副本与源文件哈希一致 | source-manifest.json；sync-qa.json；assets/manifest.json |

15项HTML检查覆盖：18张图片加载、初始页、左右方向键、Home/End、下一页按钮、讲稿展示、Esc关闭讲稿、全屏进入及退出、打印全页显示、移动端无水平溢出、零外部网络请求及零JS错误。用户已有Chrome profile对8765本地软件演示的拦截，不影响本次隔离浏览器中的离线file://HTML；本次未访问8765，也未绕过该拦截。

## 软件事实的证据边界

本任务实际读取并交叉核对了：

- `software/COMPLETION.md`
- `docs/software/README.md`与`docs/software/protocols.md`
- `software/lingban/protocols.py`中的MCP_VERSION、A2A_VERSION、Agent Card及A2A方法实现
- `software/lingban/mcp.py`中的握手状态机、工具列表和stdio处理
- `software/test-output/latest-tests.txt`中已记录的MCP握手/真实stdio、HTTP鉴权和A2A生命周期/归属/持久化等测试结果

本次融资稿同步**没有重新运行软件或固件测试**。上述协议测试结果引用已有软件验收记录，不冒充本会话复测或官方测试。收尾时软件完成记录已报告LB1集成代码与模拟测试修复完成，最终构建据此将“修复中”更新为“待实机验证”。此处引用软件会话记录，本任务未复跑软件/固件测试；编译或模拟测试不能证明硬件已接通。

MCP未覆盖resources/prompts/sampling/elicitation/roots/subscriptions/cancellation、进度、分页、listChanged、HTTP transport、OAuth及官方SDK端到端互通。A2A未覆盖流式/SSE、取消、重订阅、推送、异步、多轮上下文、文件/数据part、扩展metadata、gRPC、HTTP+JSON binding、签名/扩展Agent Card及OAuth。完整叙述随18页讲稿交付。

收尾复核已纳入最新`software/COMPLETION.md`、两份软件协议文档和`protocols.py`：A2A不支持内容类型的错误码为-32005（稿中不引用错误码），MCP/A2A版本、方法、支持子集和限制保持一致。最新hero原图也已在本轮重新导入。source-manifest.json记录此次构建的源文件截止时间和SHA-256；后续软件修复不自动纳入本次交付验收。

## 未验证与保留限制

- 没有在Microsoft PowerPoint或Google Slides中实际打开、编辑并保存。PPTX在其他电脑的字体替换效果仍须本机验证。
- 无实机连接、烧录、板级、供电、EMC、耐久、人体工学或认证验证；不把最新渲染的几何修复当作这些测试。
- 无官方协议SDK端到端互通、生产授权安全或企业连接器上线验证。
- 无真实客户/订单/收入/留存、供应商报价、制造良率、融资到账或退出估值证据。

## 文件与执行边界

最终实际构建命令为`./pitch/build.sh final-20260906-r5`。其5个交付文件经逐文件SHA-256一致性校验复制到稳定目录`pitch/deliverables/final-20260906/`。已验证原件归档在`.build/archived-deliverables/final-20260906-r5/`，此前同步版与版面修订稿也保留在归档目录。原始验证报告保持不变，复制链路见delivery-copy.json。

定稿文件SHA-256及大小见release-manifest.json。源文件清单包含最新BP、实际财务CSV/说明、研究资料、软件文档/源码/测试记录与硬件图源，见source-manifest.json。源码/素材哈希见authoring-manifest.json及assets/manifest.json。

本轮仅写pitch，未修改pitch/business-plan/或BP PDF，未执行Git、不付费、不读取原始input/1.txt或env、不对外联系。仅使用bundled LibreOffice，没有使用桌面LibreOffice。PPTX/PDF edit开始标记各成功执行一次。旧QA保留于`.build/content-sync-before/qa/`，不作为本轮结果。

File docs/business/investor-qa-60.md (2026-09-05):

# 投资人60问：回答口径与验证动作

2026-09-06。现处验证阶段，无已融资/已出货/已达成留存或收入的陈述。数字为模型假设；不能把目标改写成实绩。

## 需求与产品（1—12）

### 01. 一句话是什么？
透明鼠标＋电脑本地agent组成主动式办公伙伴，在用户授权的任务出现有用新证据时低打扰提醒。首期价值是少遗漏和更容易恢复任务，不是“鼠标会聊天”。

### 02. 为什么这是必须解决的问题？
尚未证明“必须”。我们先访谈任务遗漏造成的具体损失，再看用户是否愿持续开启、授权和付费；没有具体任务只喜欢外观的人，不算核心需求验证。

### 03. 为什么不直接用软件？
软件是功能主体，鼠标可能降低看见和确认提醒的成本。用相同内容做软件/鼠标交叉对照；硬件增量不足就保留软件、停止为硬件备货。

### 04. 最早买的人是谁？
有自主安装权限、经常跨任务切换的知识工作者和10—30人小团队。先避开安装受限、涉密和以员工监控为采购诉求的客户，以缩短验证链路。

### 05. 谁付钱，谁使用？
个人直销时是同一人；企业试点时预算负责人采购，但员工仍决定个人数据授权。采购合同不能成为读取所有个人信息的捷径。

### 06. 为什么透明外壳？
它让状态和结构可见，有外观记忆点，也可能降低“黑盒”感。但透明件易划伤、反光和显杂乱，必须与普通壳比较手感与长期接受度，不能视为壁垒。

### 07. 如何做到主动而不烦？
只接受用户选定任务和来源，以相关新证据、去重、安静窗口和提醒预算决定是否介入。用户能看理由、忽略、稍后和暂停，关闭率上升时减少提醒而非增加激励。

### 08. “陪伴”具体是什么？
是稳定可见的状态、可选择语气和专注时段的简短反馈，不宣称读懂情绪。不做生理/心理判断，也不通过内疚或依赖感让人持续使用。

### 09. 最小可用产品包括什么？
鼠标基础功能、授权手动任务、模拟或明确接入的事件、灯/触摸/屏提醒、理由、审批和个人回顾。未实现的IM连接器、云订阅与团队部署不得出现在“已上线”清单里。

### 10. 断网、模型故障或agent退出怎么办？
鼠标保持独立USB HID；本地规则提醒和已有任务可降级，复杂建议暂停并显示状态。演示与EVT必须注入这些故障，不能只跑顺畅路径。

### 11. 为什么第一期有线？
减少电池、充电、无线连接和认证相关复杂度，优先验证任务价值。代价是线缆和目标客群受限，不能把有线原型自动当成最终畅销形态。

### 12. 是否支持所有操作系统？
硬件标准鼠标HID具有兼容基础，但本地agent安装、权限和伴随模块通信必须分别验证。首批列出确切Windows/macOS版本，Linux作为扩展矩阵，不宣传“任何电脑即插即用AI”。

## 技术与信任（13—24）

### 13. 大模型在鼠标里运行吗？
不在。ESP32-S3负责灯/触摸/屏，电脑本地agent运行任务逻辑；可选云模型仅在用户授权下处理必要内容，离线规则无需云服务。

### 14. 需要一直录屏才能理解任务吗？
首期不做常驻录屏。用户手动输入或明确选择任务与内容来源；如后续增加单次截图，也必须有可见选择和范围提示，不能悄悄扩成全时观察。

### 15. 有麦克风、摄像头或生理传感器吗？
首期没有，也不将这些器件放入量产BOM。厂商替代料和ECN受控，避免以“预留能力”为由加装与任务无关的采集器件。

### 16. 企业能看到什么？
员工明确批准分享的业务结果，以及满足至少5人等防推断条件的聚合。个人原文、私聊、键鼠频次、情绪/身体状况和个人效率分数都不提供。

### 17. 五人聚合就足够匿名吗？
不够，这是最低显示门槛。还要限制切片、时间窗口差分、极端值、可识别自由文本和个人钻取，做访问控制与重识别风险评估。

### 18. 员工能拒绝或者撤回吗？
产品设计必须提供拒绝、按来源授权、暂停、撤回和删除入口，且不降低基本鼠标能力。已分享的业务结果如何撤回及企业合法留存义务要在试点协议写清，不能承诺删除所有已被他人合法保存的副本。

### 19. 触摸按钮等于硬件安全隔离吗？
不等于。原型触摸只是发送确认请求给电脑软件，未使用独立安全控制器形成不可绕过门控；宣传只能说“实体交互入口”，敏感动作仍靠可审核的软件审批。

### 20. 会自动发邮件、付款或修改文件吗？
首期只生成提案或在界面中明确批准后执行受支持动作，不能默默发送。付款、删除、交易、外部委派与企业资源变更需要更严审批与审计，未支持的动作就拒绝。

### 21. 提示注入和恶意任务内容怎么办？
外部内容作为数据，不可改变系统授权或触发新的执行权限；动作与对象需单独验证。测试要包含“忽略规则并发送资料”等恶意输入，审批界面也必须显示最终具体操作。

### 22. 个人信息合规如何处理？
按明确目的、最小必要、透明和相应处理依据设计，敏感信息首期不采集；实际试点要确认角色、留存、删除、处理者合同与跨境情况。个人信息保护法存在多种处理依据，本产品自愿授权原则不能被误写成对所有企业数据处理的通用法律结论。

### 23. 是否100%本地？
任务与偏好默认保存在电脑，本地规则可用；一旦用户选择云模型，必要内容会按授权传给该供应商，所以不能宣传100%本地AI。UI要明确本次是否离开设备，而非只展示一个笼统隐私口号。

### 24. 复用Active Agent有多快？
可复用的是事件、长期任务、证据、安静窗口、审批和outbox的架构概念。实际代码接口、安装体验、权限和可靠性需要工程检查，已有README不是本产品集成完成证明。

## 市场、竞争和增长（25—36）

### 25. 市场有多大？
目前没有可验证细分销量，不拿泛AI市场或全部鼠标保有量冒充可服务市场。先核算可触达200名个人、30个小团队的漏斗，再用真实转化更新可到达市场。

### 26. 为什么现在做？
电脑agent与成熟鼠标供应链可能降低试验成本，用户也更熟悉AI工具。但“现在”不是自动需求证据，仍需证明主动提醒比已有通知有用且可接受。

### 27. Microduck证明了什么？
官方资料证明其公开产品定位、软件架构和399美元预售标价，税运另计。它没有证明本项目销量，也不能从7374 stars或演示视频推导众筹金额和量产良率。

### 28. Violoop证明了什么？
官网展示HDMI/USB-HID、本地算力和实体批准的产品路线，页面处于预发布预约。399美元起及预约优惠后的369美元起是网页标价；53tok/s、2.7倍M4和token节省是厂商主张，未独立复现。

### 29. 和Violoop核心差别是什么？
我们使用用户电脑运行agent，不内置独立屏幕捕获与大模型计算硬件。可能更便宜、更易打样，代价是安装与权限依赖，不能承诺无需驱动/任何系统/锁屏继续工作。

### 30. 大厂鼠标厂商复制怎么办？
单个灯/屏和提醒功能容易复制，不能假装有硬件垄断。应累积被验证的任务体验、授权信任、售后与交付能力，并保留软件/配件/授权合作选择。

### 31. 护城河在哪里？
当前没有已成立护城河，只有可累积的低打扰策略、用户反馈、可复用供应链和分发。只有持续留存、推荐和单位贡献证明这些资产有价值，专利数量不能代替需求。

### 32. 获客怎么做？
先通过创始人展示和自愿设计伙伴招募获得20名测试者，再受控直销。每个渠道记录触达、试用、付费、退款和售后成本，前100台不做大额投流或铺货。

### 33. 用户愿意付299元吗？
尚未验证。必须让用户在真实价格下选择购买或明确可退订金，并区分熟人支持和真实办公需求；问卷“愿意买”不能直接当订单。

### 34. 如何避免成为几天后吃灰的玩具？
把每周“有帮助”的主动介入、D7/D30仍启用和退货原因作为主指标，不把动画互动次数当价值。若两轮改进后仍无持续使用，停止新增硬件库存。

### 35. 企业销售会拖慢吗？
会，安装、安全评审、授权和采购账期都可能很慢。先选小团队、标准配置和有限试点，不能为了一个客户做大量免费定制并把意向当合同。

### 36. 先中国还是海外？
先在可控本地环境验证，因为中文任务和供应链沟通更直接。海外需独立评估合规、退换、税运、模型可用性和客服，不能把美元竞品价格换算后直接上众筹。

## 定价、制造和财务（37—48）

### 37. 为什么五个价格档？
它们用于探索不同价值与服务边界，首期只生产299版。99普通透明鼠标、199无屏、499套装、899试点包要逐个证明需求与成本，不同时开五套模具。

### 38. 1499和3999卖什么？
仅是未来桌面计算底座/团队终端概念，规格和BOM尚未成立。不收预售、不计收入、不在首期融资材料中当成确定产品路线。

### 39. 299版BOM有依据吗？
108元是1000台规模设计估算，拆到OEM底座、壳、S3、屏、PCB、装配、包装和损耗，没有工厂书面报价。5台原型和50—100台小批更贵，必须拿3家同口径报价校正。

### 40. 真实单台赚钱多少？
模型299版扣税预留、制造、渠道、退款、履约、质保、支持和获客后约66.51元贡献。它不含月固定支出和NRE，不是净利润；制造成本升到170元时贡献仅约3.27元。

### 41. 为什么不说64%毛利？
299减108只看到制造差额，遗漏税、获客和交付成本，容易误导硬件经济性。我们同时给完整费用和现金口径，投资人可以直接修改CSV重算。

### 42. 订阅是主要收入吗？
还不是，也未进入10个月模型。19元个人/39元团队月费只是价格卡，先测调用成本、付费意愿和留存；基础鼠标和离线规则不能因停订阅失效。

### 43. 七天真能做出来吗？
目标是用现成OEM底座和开发板做5台演示样机，不是定制注塑量产。器件、接线或结构不合适就退回外置模块，不能以时间压力跳过电气与数据边界。

### 44. 三十天能保证出货吗？
不能保证。只有EVT、小批质量、适用合规、真实需求和售后条件均满足才争取50—100台受控交付；开模、返板和实验室延期都应推迟发货。

### 45. 怎么选工厂？
先要求完整BOM、合法USB身份、可追溯性、ECN和售后条款，排除不满足者后再比较质量、交付与成本。至少3份可比报价，最低价不覆盖资料缺失或未经授权替料。

### 46. 什么时候盈亏平衡？
按当前299版贡献和5.5万元月固定支出，仅该SKU约827台/月覆盖固定支出，仍不代表收回12万元NRE。基准10个月累计损益仍约负29万元，不能宣称十个月盈利。

### 47. 需要多少钱？
模型用60万元起始现金作情景，非已融资或固定募资报价；12万元NRE、每月5.5万元开支和预付备货是主要消耗。所有情景都缺少舒适的3个月现金缓冲，应根据实际报价和节奏缩支/降库存或落实资金后再采购。

### 48. 销量上升为什么也会缺钱？
货款提前付，库存和企业应收占钱，而利润不等于现金。上行情景最低现金约2.3万元，低于基准，说明应谈分批采购/验收付款并控制账期，不能只追销售额。

## 团队、融资与退出（49—60）

### 49. 团队要几个人？
先按3人核心角色规划：产品/客户、软件agent、硬件/供应链，质量与合规按次外部支持。模型人员月支出4.2万元是预算假设，不表示已招到团队或适合所有城市薪资。

### 50. 谁对交付负责？
明确产品、工程、质量、采购和财务的放行职责，即使多人兼任也保留记录。工厂说可以做，不等于产品负责人可以跳过合规、用户授权或售后承诺。

### 51. 下一轮融资的里程碑是什么？
可讨论的证据包括20人真实试用、留存/有用提醒、100台受控交付、退款/支持成本和可核实单位贡献。它们提高可评估性，却不保证投资人会出价。

### 52. 估值多少？
现阶段没有足够事实支持精确估值，不根据概念硬件价格或远期生态收入倒推高估值。先确定验证预算、创始人承担、可用融资工具和条款，再与真实投资方讨论。

### 53. 十个月退出是不是太激进？
十个月只是战略检查点，既不是承诺回购，也不是IPO/收购时间表。持续经营、融资、授权、资产交易与有序停止都应基于当时证据和实际对手方条件。

### 54. 谁会收购？
外围设备、企业软件或agent工具公司只是潜在合作类别，未联系也未收到意向。不能在材料中展示其logo暗示合作，或把公开产品相近当成收购概率。

### 55. 出售用户数据能变现吗？
不是本项目商业模式，也不得把个人任务、私聊、生理/情绪或员工表现数据作为出售资产。交易应围绕合法可转让代码、品牌、设计、工装和合同，并处理用户告知、授权及数据义务。

### 56. 如果项目失败怎么停？
优先交付或退款、保修、员工和供应商义务，停采数据并提供导出/删除与必要通知。库存/工装只能按可实现价格处置，不能把账面成本当现金回收。

### 57. 最容易被忽视的风险？
不只是AI能力，而是手感、USB稳定、透明件磨损、安装阻力、售后工时和员工对监控的担忧。每项都可能单独让用户不用，所以验证应覆盖完整一周而非发布会五分钟。

### 58. 半年为什么不同时做八种硬件？
每种硬件都新增供应链、固件、认证、库存和售后，早期分散会拖垮现金。先开放一个状态协议，再只选通过独立付费验证的低复杂度配件。

### 59. 怎样证明没有自我欺骗？
在招募前写下目标和停止条件，保留失败、退货和负反馈；区分真实事件、模拟、厂商宣称和估算。每周更新现金与待验证清单，不用众筹故事替代自己的数据。

### 60. 今天希望投资人做什么？
理解并审阅可执行假设、成本模型和阶段门槛，若有合适资源再讨论设计伙伴或按里程碑支持。当前没有要求立即付款、保证收益或承诺退出，任何合作都以具体可审阅条款为准。

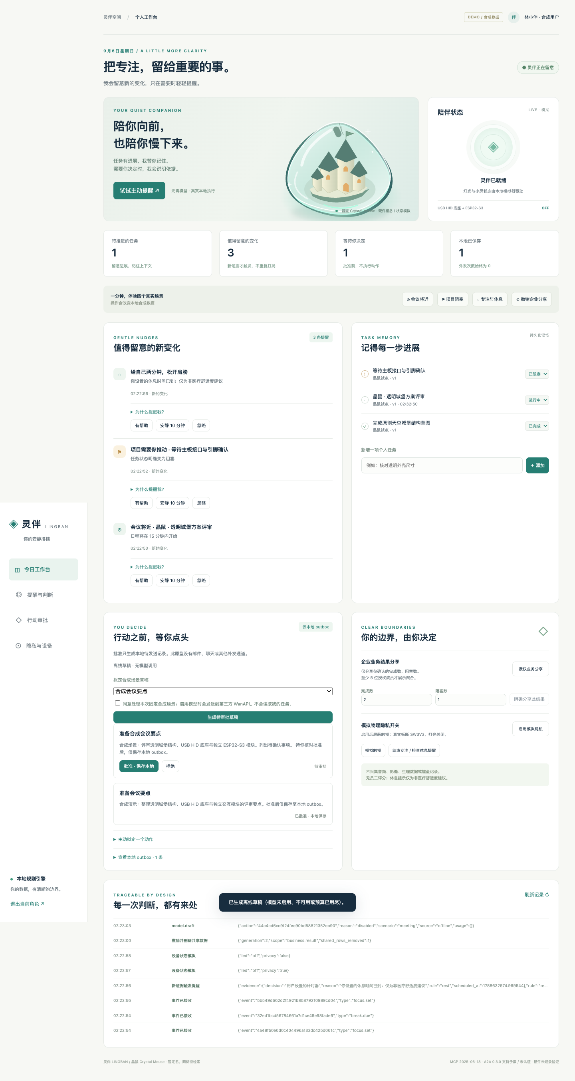
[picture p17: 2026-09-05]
docs/verification/browser/model-offline.png

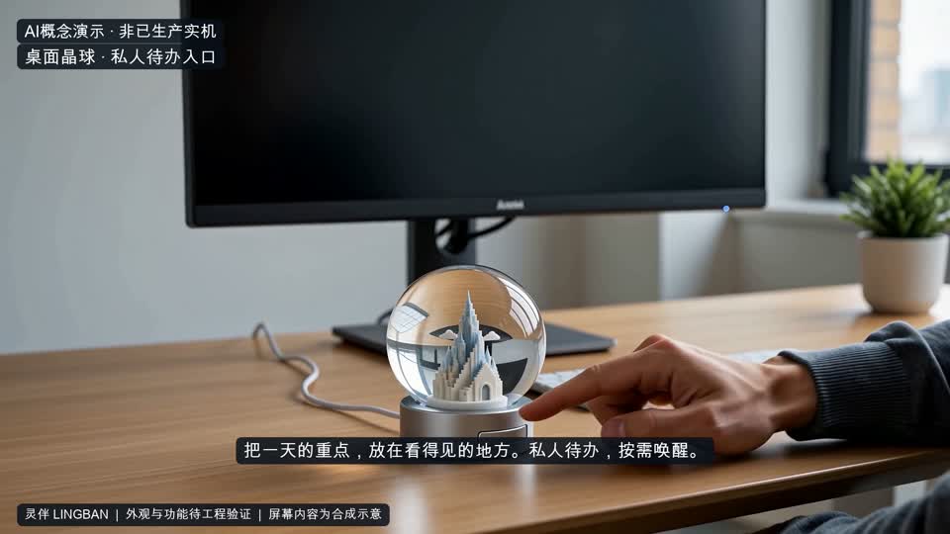
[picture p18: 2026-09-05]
media/qa/04_desktop_orb_05s.jpg

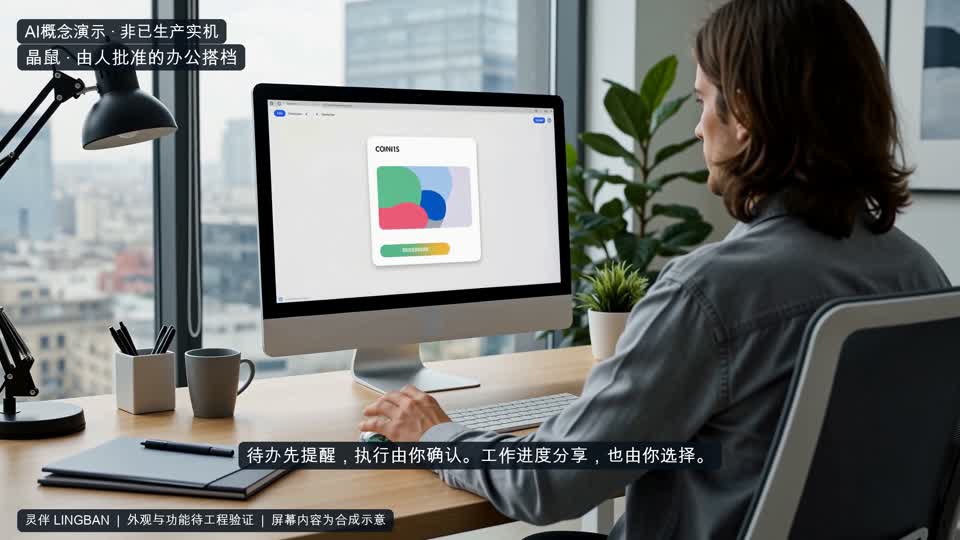
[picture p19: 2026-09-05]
media/qa/02_crystal_mouse_workday_13s.jpg

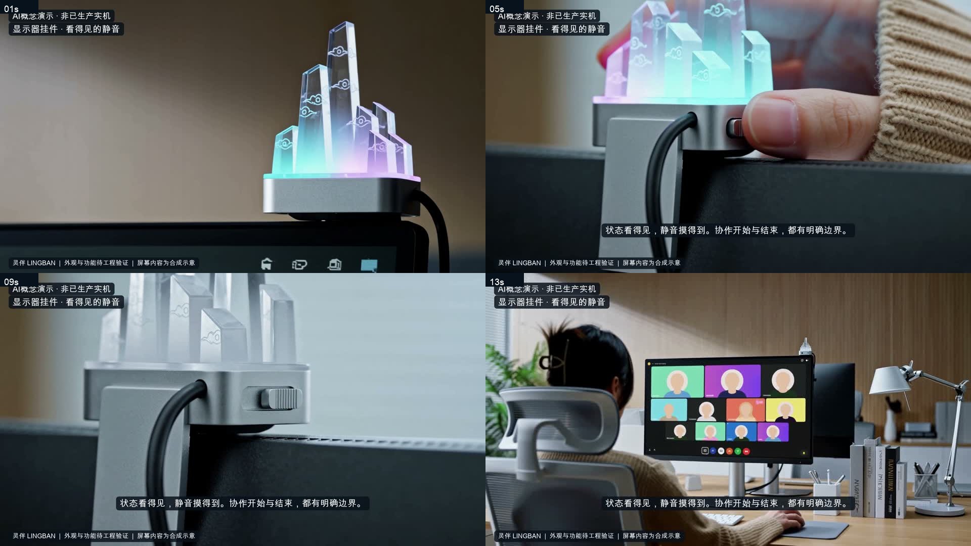
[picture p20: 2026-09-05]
media/qa/05_monitor_charm_contact.jpg

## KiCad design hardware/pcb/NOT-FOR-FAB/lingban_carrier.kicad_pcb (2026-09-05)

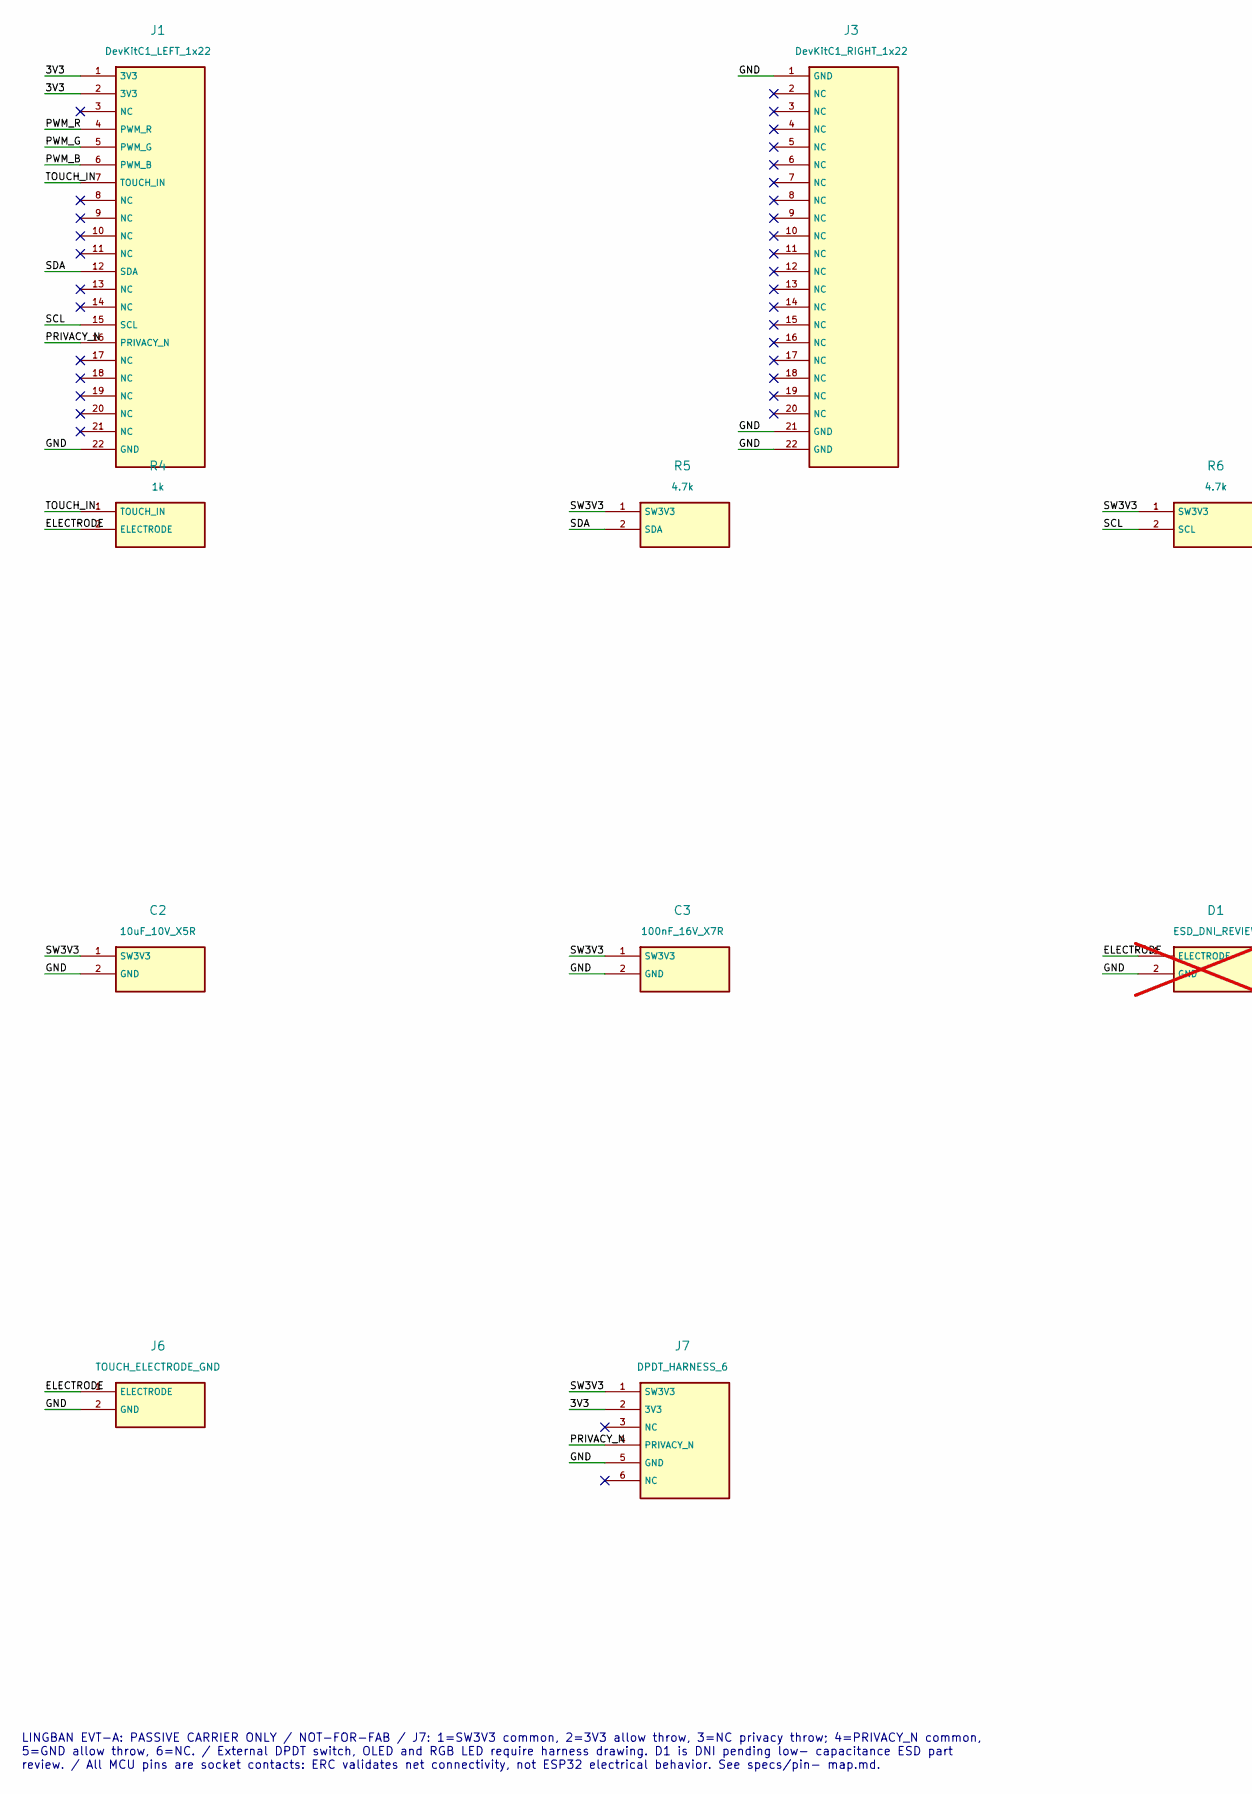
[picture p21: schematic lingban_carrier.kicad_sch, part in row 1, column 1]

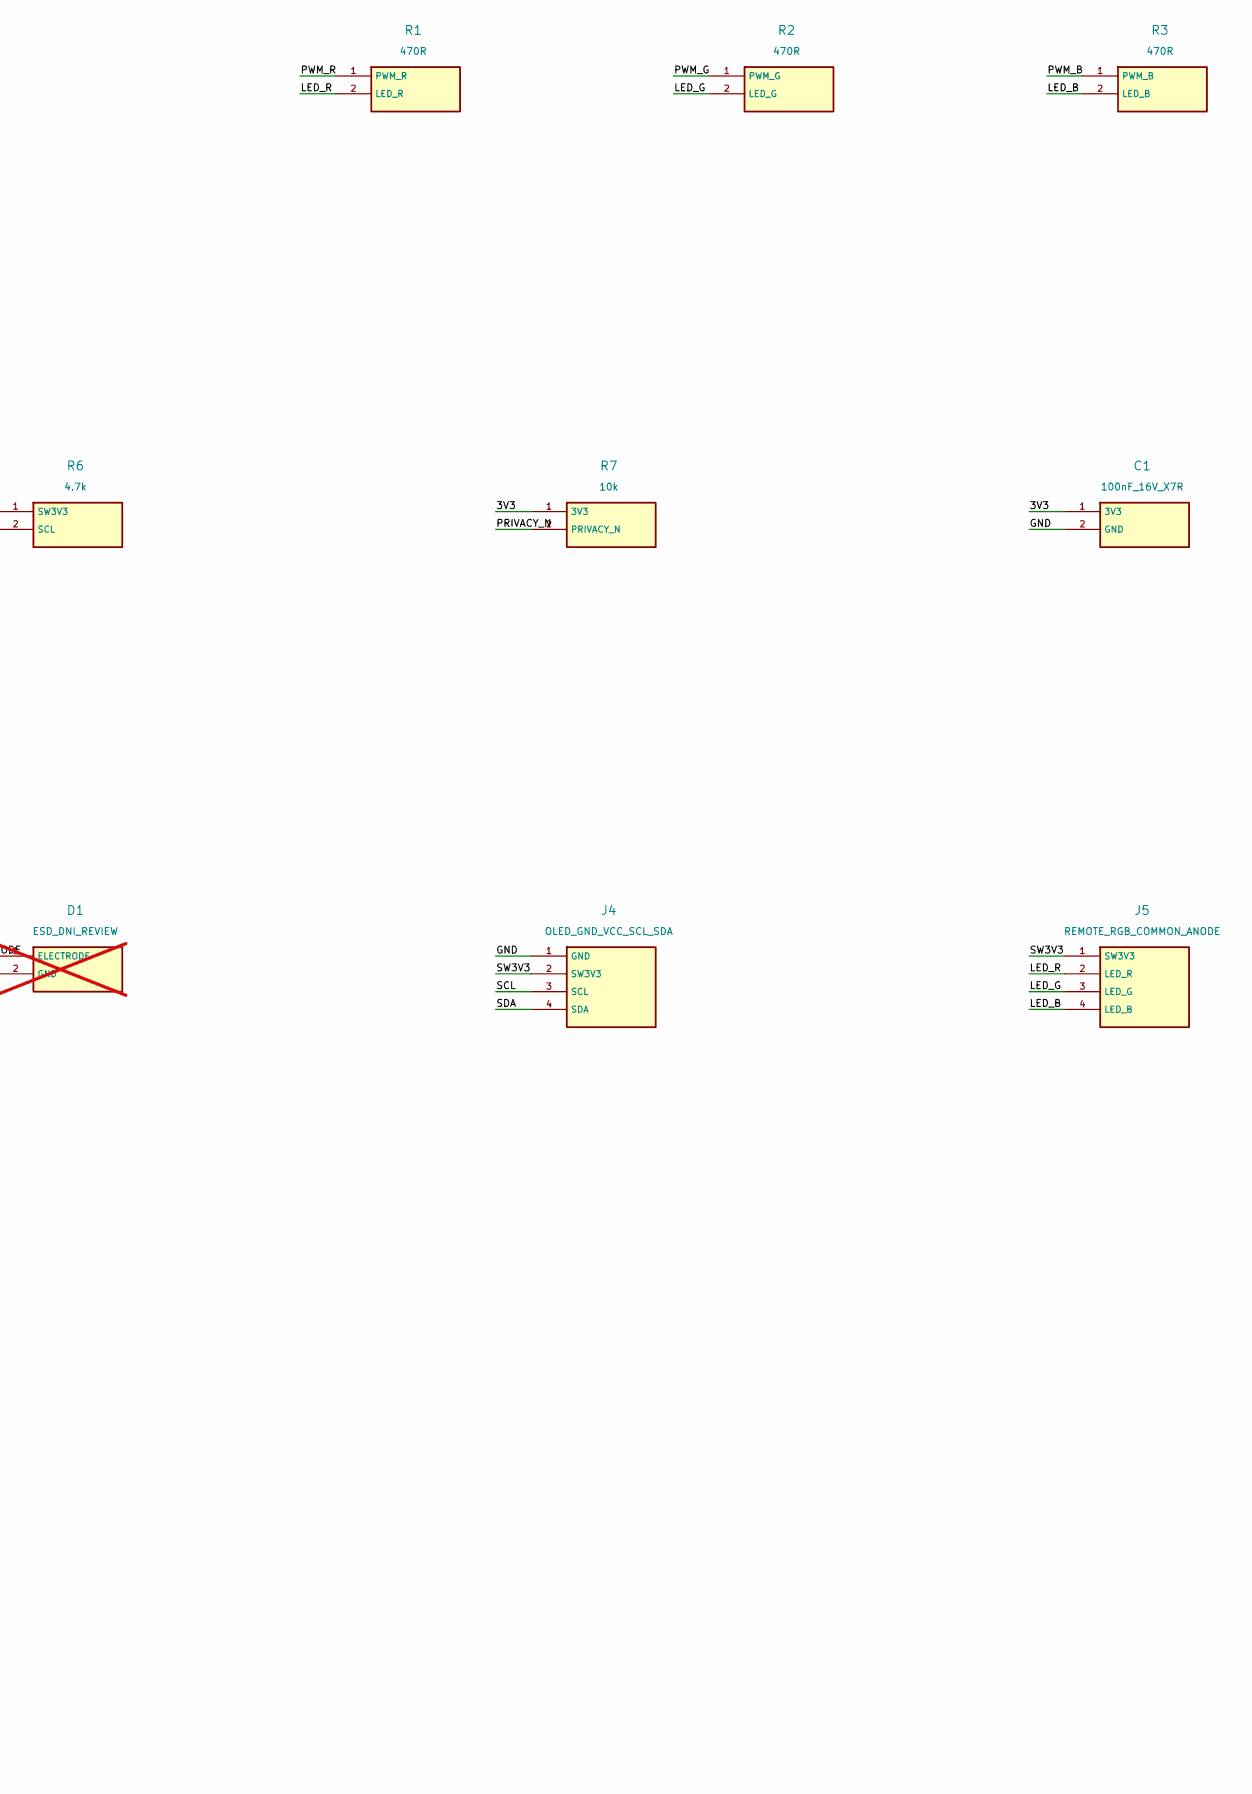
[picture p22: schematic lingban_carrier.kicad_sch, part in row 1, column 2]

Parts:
C1: 100nF_16V_X7R; C1
C2: 10uF_10V_X5R; C2
C3: 100nF_16V_X7R; C3
D1: ESD_DNI_REVIEW; D1; not fitted
J1: DevKitC1_LEFT_1x22; J1
J3: DevKitC1_RIGHT_1x22; J3
J4: OLED_GND_VCC_SCL_SDA; J4
J5: REMOTE_RGB_COMMON_ANODE; J5
J6: TOUCH_ELECTRODE_GND; J6
J7: DPDT_HARNESS_6; J7
R1: 470R; R1
R2: 470R; R2
R3: 470R; R3
R4: 1k; R4
R5: 4.7k; R5
R6: 4.7k; R6
R7: 10k; R7

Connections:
/3V3: C1.1 (3V3), J1.1 (3V3), J1.2 (3V3), J7.2 (3V3), R7.1 (3V3)
/ELECTRODE: D1.1 (ELECTRODE), J6.1 (ELECTRODE), R4.2 (ELECTRODE)
/GND: C1.2 (GND), C2.2 (GND), C3.2 (GND), D1.2 (GND), J1.22 (GND), J3.1 (GND), J3.21 (GND), J3.22 (GND), J4.1 (GND), J6.2 (GND), J7.5 (GND)
/LED_B: J5.4 (LED_B), R3.2 (LED_B)
/LED_G: J5.3 (LED_G), R2.2 (LED_G)
/LED_R: J5.2 (LED_R), R1.2 (LED_R)
/PRIVACY_N: J1.16 (PRIVACY_N), J7.4 (PRIVACY_N), R7.2 (PRIVACY_N)
/PWM_B: J1.6 (PWM_B), R3.1 (PWM_B)
/PWM_G: J1.5 (PWM_G), R2.1 (PWM_G)
/PWM_R: J1.4 (PWM_R), R1.1 (PWM_R)
/SCL: J1.15 (SCL), J4.3 (SCL), R6.2 (SCL)
/SDA: J1.12 (SDA), J4.4 (SDA), R5.2 (SDA)
/SW3V3: C2.1 (SW3V3), C3.1 (SW3V3), J4.2 (SW3V3), J5.1 (SW3V3), J7.1 (SW3V3), R5.1 (SW3V3), R6.1 (SW3V3)
/TOUCH_IN: J1.7 (TOUCH_IN), R4.1 (TOUCH_IN)

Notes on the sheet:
LINGBAN EVT-A: PASSIVE CARRIER ONLY / NOT-FOR-FAB / J7: 1=SW3V3 common, 2=3V3 allow throw, 3=NC privacy throw; 4=PRIVACY_N common, 5=GND allow throw, 6=NC. / External DPDT switch, OLED and RGB LED require harness drawing. D1 is DNI pending low- capacitance ESD part review. / All MCU pins are socket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

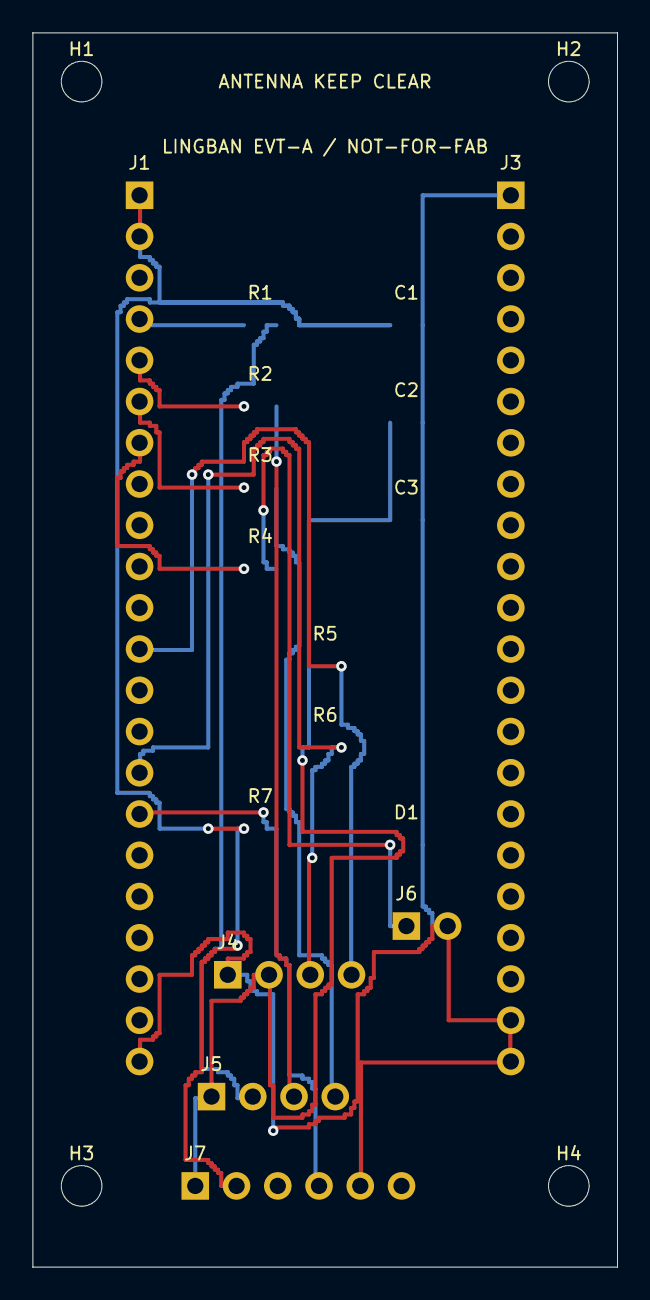
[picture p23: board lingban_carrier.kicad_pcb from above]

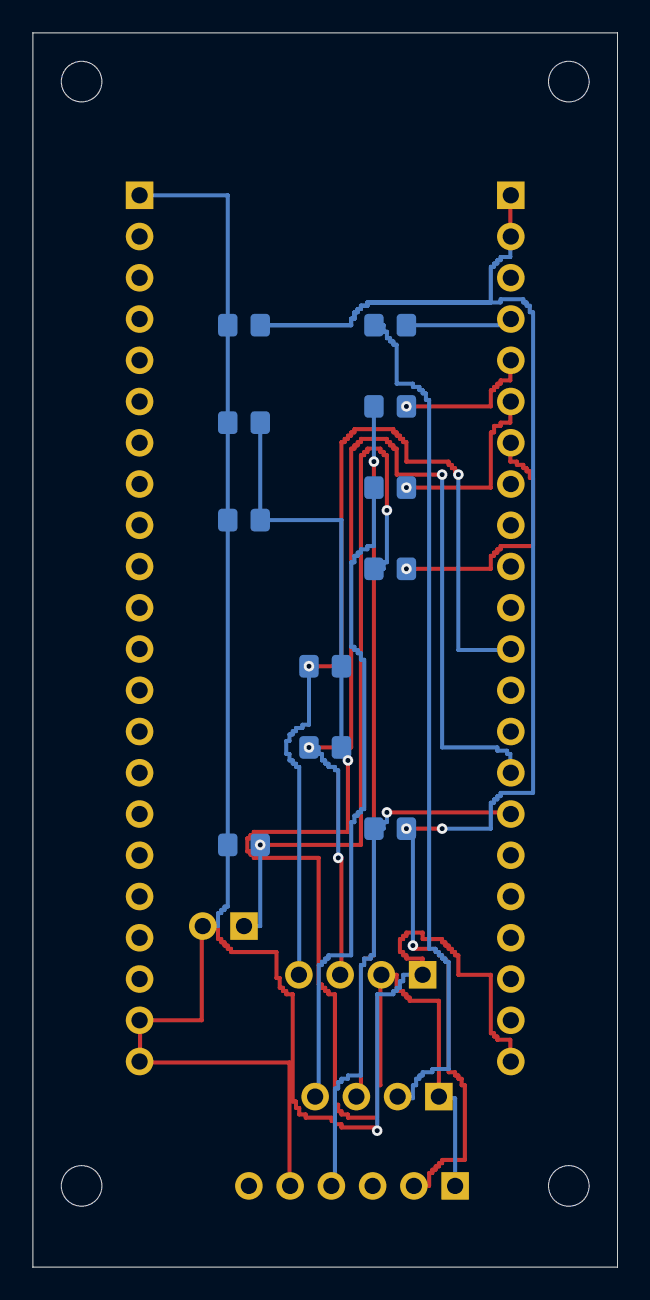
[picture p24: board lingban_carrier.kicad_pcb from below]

Board: 2 copper layers, 36.0 x 76.0 mm, 21 parts (11 on the bottom side), 14 nets.

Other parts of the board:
H1: M2_CLEARANCE; H1
H2: M2_CLEARANCE; H2
H3: M2_CLEARANCE; H3
H4: M2_CLEARANCE; H4

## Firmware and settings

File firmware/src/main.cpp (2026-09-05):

#include <Arduino.h>
#include <Wire.h>
#include "board_config.hpp"
#include "controller.hpp"

struct ArduinoHal{
    bool touchSample=false,touchStable=false;uint32_t touchEdge=0;
    bool readPrivacy(int pin){return digitalRead(pin)!=LOW;}
    void input(int pin){pinMode(pin,INPUT);if(pin==LB_PIN_TOUCH){touchSample=false;touchStable=false;}}
    void outputHigh(int pin){digitalWrite(pin,HIGH);pinMode(pin,OUTPUT);}
    void pwmPrepare(int channel,int duty){ledcSetup(channel,5000,8);ledcWrite(channel,duty);}
    void pwmAttach(int pin,int channel){ledcAttachPin(pin,channel);}
    void pwmDetach(int pin){ledcDetachPin(pin);}
    void pwmWrite(int channel,int duty){ledcWrite(channel,duty);}
    bool wireBegin(int sda,int scl){bool ok=Wire.begin(sda,scl);Wire.setClock(100000);Wire.setTimeOut(5);return ok;}
    void wireEnd(){Wire.end();}
    // Bound each I2C transaction. Recheck the physical contact before every transfer.
    bool powered(){return LB_PIN_PRIVACY>=0&&digitalRead(LB_PIN_PRIVACY)==LOW;}
    bool command(uint8_t c){
        if(!powered())return false;
        Wire.beginTransmission(LB_SCREEN_ADDRESS);Wire.write(0x00);Wire.write(c);return Wire.endTransmission()==0;
    }
    bool screenInit(int address){
        if(!powered())return false;
        Wire.beginTransmission(address);if(Wire.endTransmission()!=0)return false;
        const uint8_t init[]={0xAE,0xD5,0x80,0xA8,0x3F,0xD3,0,0x40,0x8D,0x14,0x20,0,0xA1,0xC8,0xDA,0x12,0x81,0x7F,0xD9,0xF1,0xDB,0x40,0xA4,0xA6};
        for(uint8_t c:init)if(!command(c))return false;
        // Display stays OFF until the first fresh frame has been drawn.
        return true;
    }
    void screenBlank(){command(0xAE);}
    void screenDraw(const std::string& led){
        uint8_t pixels[1024]={0};
        auto dot=[&](int x,int y){if(x>=0&&x<128&&y>=0&&y<64)pixels[x+(y/8)*128]|=uint8_t(1<<(y%8));};
        auto box=[&](int x,int y,int w,int h){for(int a=x;a<x+w;a++)for(int b=y;b<y+h;b++)if(a==x||a==x+w-1||b==y||b==y+h-1)dot(a,b);};
        box(36,26,56,30);box(30,16,18,40);box(80,16,18,40);box(55,8,18,48);box(60,43,8,13);
        int bars=led=="off"?0:led=="teal"?2:led=="blue"?3:4;
        for(int i=0;i<bars;i++)box(107,48-i*10,10,7);
        for(uint8_t c:{0x21,0,127,0x22,0,7})if(!command(c))return;
        for(int i=0;i<1024;i+=16){
            if(!powered())return;
            Wire.beginTransmission(LB_SCREEN_ADDRESS);Wire.write(0x40);Wire.write(pixels+i,16);
            if(Wire.endTransmission()!=0)return;
        }
        command(0xAF);
    }
    bool touchPressed(int pin,uint32_t threshold,uint32_t now){
        bool sample=touchRead(pin)>threshold;
        if(sample!=touchSample){touchSample=sample;touchEdge=now;}
        if(uint32_t(now-touchEdge)>=40)touchStable=sample;
        return touchStable;
    }
};
lingban::BoardPins boardPins(){
    lingban::BoardPins p;p.red=LB_PIN_LED_R;p.green=LB_PIN_LED_G;p.blue=LB_PIN_LED_B;p.touch=LB_PIN_TOUCH;
    p.sda=LB_PIN_SDA;p.scl=LB_PIN_SCL;p.privacy=LB_PIN_PRIVACY;p.address=LB_SCREEN_ADDRESS;p.threshold=LB_TOUCH_THRESHOLD;return p;
}
lingban::Device device;ArduinoHal hal;
lingban::Controller<ArduinoHal> controller(device,hal,boardPins());
std::string incoming;bool dropping=false;uint32_t lastInput=0;
void setup(){
    controller.begin(millis()); // Read physical privacy before any screen/PWM initialization.
    // CDC_ON_BOOT=0: Serial is UART0, RX44/TX43, connected to the board's USB-UART bridge.
    Serial.begin(115200,SERIAL_8N1,44,43);
}
void loop(){
    controller.step(millis());
    // Bound serial work per pass so a continuous input stream cannot starve the privacy poll.
    unsigned budget=64;
    while(budget--&&Serial.available()){
        controller.step(millis());char c=char(Serial.read());lastInput=millis();
        if(c=='\n'){
            if(!dropping){incoming+=c;auto reply=device.receive(incoming,millis());controller.step(millis());if(!reply.empty())Serial.print(reply.c_str());}
            incoming.clear();dropping=false;
        }else if(!dropping){incoming+=c;if(incoming.size()>=lingban::MAX_FRAME){incoming.clear();dropping=true;}}
    }
    if((!incoming.empty()||dropping)&&uint32_t(millis()-lastInput)>=1000){incoming.clear();dropping=false;}
    delay(1);
}

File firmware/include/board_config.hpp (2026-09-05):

#pragma once
// Unverified pins are deliberately disabled. Hardware session owns final pin map.
#ifndef LB_PIN_LED_R
#define LB_PIN_LED_R -1
#endif
#ifndef LB_PIN_LED_G
#define LB_PIN_LED_G -1
#endif
#ifndef LB_PIN_LED_B
#define LB_PIN_LED_B -1
#endif
#ifndef LB_PIN_TOUCH
#define LB_PIN_TOUCH -1
#endif
#ifndef LB_TOUCH_THRESHOLD
#define LB_TOUCH_THRESHOLD 0
#endif
#ifndef LB_PIN_PRIVACY
#define LB_PIN_PRIVACY -1
#endif
#ifndef LB_PIN_SDA
#define LB_PIN_SDA -1
#endif
#ifndef LB_PIN_SCL
#define LB_PIN_SCL -1
#endif
#ifndef LB_SCREEN_ADDRESS
#define LB_SCREEN_ADDRESS -1
#endif
// Prototype privacy wiring: LOW explicitly enables interaction; HIGH/disconnected is private.
// EVT-A: SW3V3 common-anode RGB, 470 ohm series per GPIO sink. OFF=HIGH / PWM255.
// Privacy removes SW3V3: no LED privacy light; all peripheral pins become INPUT high-Z.

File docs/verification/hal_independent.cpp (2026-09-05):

#include "controller.hpp"
#include <cassert>
#include <iostream>
#include <map>
#include <string>
#include <vector>
struct Mock {
 bool privacy=true,bus=false,flipOnPrepare=false;int writes=0,draws=0,blanks=0,touches=0,ends=0;
 std::map<int,std::string> modes;std::map<int,int> duties;std::vector<std::string> events;
 bool readPrivacy(int){events.push_back("read");return privacy;}
 void input(int p){modes[p]="input";events.push_back("input");}
 void outputHigh(int p){assert(!privacy);modes[p]="high";events.push_back("high");}
 void pwmPrepare(int c,int d){assert(!privacy&&d==255);duties[c]=d;if(flipOnPrepare)privacy=true;}
 void pwmAttach(int p,int c){assert(!privacy&&duties[c]==255);modes[p]="pwm";events.push_back("attach");}
 void pwmDetach(int p){modes[p]="detached";}
 void pwmWrite(int c,int d){assert(!privacy);duties[c]=d;++writes;}
 bool wireBegin(int,int){assert(!privacy);bus=true;return true;}
 void wireEnd(){bus=false;++ends;}
 bool screenInit(int){assert(!privacy&&bus);return true;}
 void screenBlank(){assert(!privacy&&bus);++blanks;}
 void screenDraw(const std::string&){assert(!privacy&&bus);++draws;}
 bool touchPressed(int,uint32_t,uint32_t){assert(!privacy);++touches;return true;}
};
lingban::BoardPins evt(){lingban::BoardPins p;p.red=4;p.green=5;p.blue=6;p.touch=7;p.sda=8;p.scl=9;p.privacy=10;p.address=0x3c;return p;}
void inputs(const Mock& h){for(int p:{4,5,6,7,8,9})assert(h.modes.at(p)=="input");assert(!h.bus);}
int main(){
 using namespace lingban;
 {
  Device d;Mock h;Controller<Mock> c(d,h,BoardPins{});c.begin(0);
  d.receive(encode(1,"HELLO","versions=1"),0);c.step(100);
  assert(d.privacy&&!c.active&&h.writes==0&&!h.bus&&h.modes.empty());
 }
 {
  Device d;Mock h;Controller<Mock> c(d,h,evt());c.begin(0);inputs(h);
  assert(h.events.size()>1&&h.events[1]=="read");
  d.receive(encode(1,"HELLO","versions=1"),0);c.step(300);inputs(h);assert(h.writes==0&&h.draws==0);
  h.privacy=false;c.step(301);c.step(340);assert(d.privacy&&!c.active);c.step(341);
  assert(!d.privacy&&c.active&&h.bus);for(int i=0;i<3;++i)assert(h.duties[i]==255);
  d.receive(encode(2,"SET","led=teal"),350);c.step(350);
  assert(h.duties[0]==255&&h.duties[1]==195&&h.duties[2]==217&&h.touches==0);
  int oldWrites=h.writes,oldDraws=h.draws;h.privacy=true;c.step(351);inputs(h);
  assert(d.privacy&&!c.active&&h.writes==oldWrites&&h.draws==oldDraws&&h.ends==1);
  c.step(900);assert(h.writes==oldWrites&&h.draws==oldDraws);
  h.privacy=false;c.step(901);c.step(941);assert(c.active);for(int i=0;i<3;++i)assert(h.duties[i]==255);
  d.receive(encode(3,"GET"),1000);d.receive(encode(4,"SET","led=amber"),1001);c.step(5999);assert(c.active);
  c.step(6000);inputs(h);assert(!d.ready&&!c.active&&d.led=="off"&&d.screen.empty()&&h.blanks==1);
  assert(d.receive(encode(5,"SET","led=blue"),6001).find("handshake_required")!=std::string::npos);
  d.receive(encode(6,"HELLO","versions=1;session=0123456789abcdef"),6002);c.step(6002);assert(c.active);
 }
 {
  Device d;Mock h;h.privacy=false;h.flipOnPrepare=true;Controller<Mock> c(d,h,evt());c.begin(0);
  d.receive(encode(1,"HELLO","versions=1"),0);c.step(40);inputs(h);
  assert(d.privacy&&!c.active&&h.writes==0&&h.draws==0);
 }
 {
  Device d;d.physicalPrivacy(false);const uint32_t start=0xffffff00u;
  d.receive(encode(1,"HELLO","versions=1"),start);d.poll(uint32_t(start+4999));assert(d.ready);
  d.poll(uint32_t(start+5000));assert(!d.ready);
 }
 std::cout<<"Independent HAL PASS: boot privacy, safe profile, 40ms release, common-anode off/colors, immediate high-Z, I2C shutdown, disabled touch, 5s fail-safe/recovery, privacy-edge guard, millis rollover\n";
}

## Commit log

2026-09-05 Add product decisions, business model, factory RFQ and review portal
    [bom-cost-estimate.csv, financial-assumptions.csv, financial-inputs-skus.csv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]
2026-09-05 Deliver LINGBAN EVT-A software, reviewed hardware, pitch and media package
    [01_base.step, 01_base.stl, 02_clear_canopy.step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]
